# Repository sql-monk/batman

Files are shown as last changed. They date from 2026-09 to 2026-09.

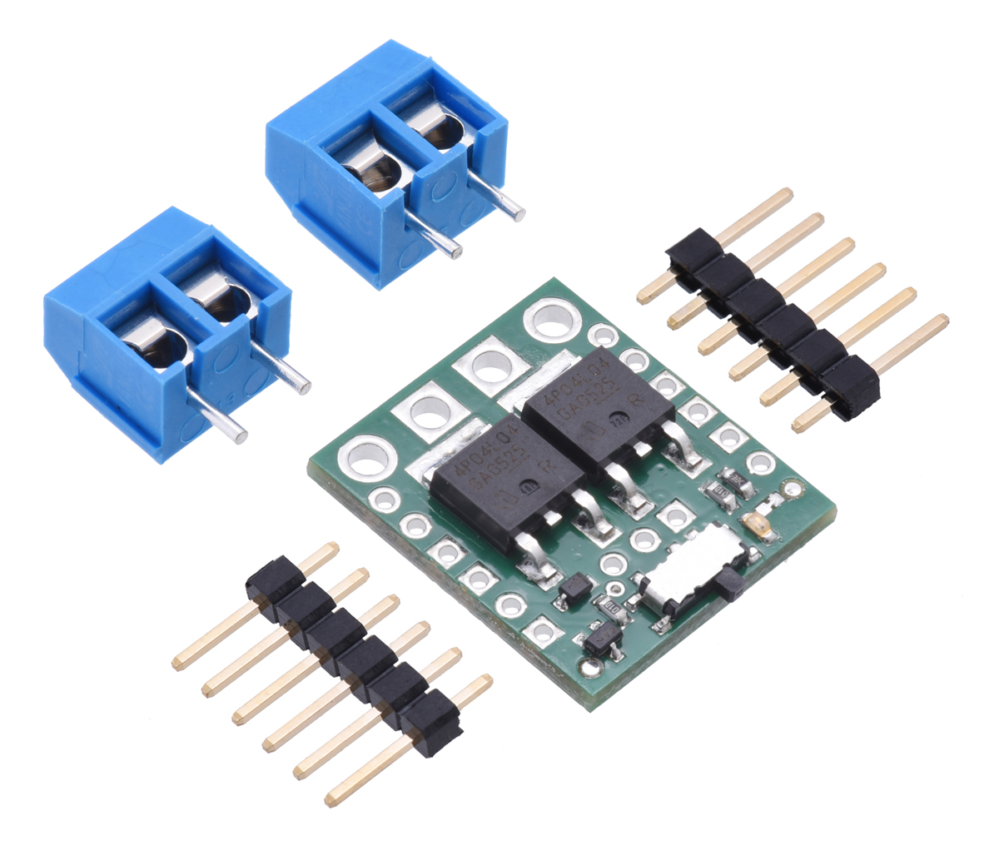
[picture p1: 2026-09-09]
mechanical/references/pololu-switch-terminals.jpg

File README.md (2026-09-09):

# batman — менеджер двох акумуляторів (LiFePO₄ 8S + свинець 24 В)

Пристрій, що заряджає два акумулятори по черзі від одного DPS5015, віддає їх на спільне навантаження через ідеальні діоди з керованими ключами, і рахує, скільки кожен акумулятор прийняв і віддав.

Основа — наявні модулі з [docs/components.md](docs/components.md). Чотири однобічні плати ЛУТ: A з ESP і двома портами I²C для ADS, B з аналоговими входами та фільтрами без I²C, C з розподілом 3,3 В, D з розподілом 5 В. Два окремі ADS1115 одержують аналог із B, живлення/I²C із A. Потрібен ще один ADS1115; C/D розподіляють готове живлення, а не замінюють стабілізатори.

| Тека | Вміст |
|---|---|
| [docs/concept.md](docs/concept.md) | задум, архітектура, вибір модулів, вимірювання й підрахунок А·год, припущення, відкриті питання |
| [docs/plan.md](docs/plan.md) | план робіт: документація, схема й плати, корпус, прошивка, сервіс; порядок і критерії готовності |
| [docs/components.md](docs/components.md) | кожен модуль і базовий компонент: характеристики, розпіновка, розміри з позначкою джерела, кількість, публічні посилання |
| [docs/README.md](docs/README.md) | зміст документації, правило «одне число — одне місце», позначення |
| [docs/connections.md](docs/connections.md) | вузли, кола з номерами, GPIO ESP32, роз'єми A–D, шкала АЦП |
| [docs/dps5015-modbus.md](docs/dps5015-modbus.md) | порт, регістри, послідовності команд, помилки DPS5015 |
| [docs/measurement.md](docs/measurement.md) | вибірка, інтегрування, автонуль, SoC, NVS |
| [docs/protocol.md](docs/protocol.md) | пристрій ↔ сервіс: пошук, JSON, REST |
| [docs/firmware.md](docs/firmware.md) | вимоги до прошивки: старт, стейт-машина, параметри |
| [docs/service.md](docs/service.md) | вимоги до сервісу: БД, агрегати, сторінки, розгортання |
| [docs/enclosure/requirements.md](docs/enclosure/requirements.md) | що вмістити, зони, зазори, тепло, друк, перелік STL |
| [docs/tests.md](docs/tests.md) | бланки перевірок і результати |
| [hardware/README.md](hardware/README.md) | єдиний проєкт KiCad 10, сім сторінок схеми, розведені A–D, PDF ЛУТ, свердління, BOM, кабелі та умови допуску прототипу |
| `firmware/` | код ESP32: вимірювання, підрахунок А·год, Modbus до DPS5015, ключі, Wi-Fi-телеметрія |
| `service/` | кросплатформений сервіс (Windows → Raspberry Pi 4): пошук пристрою, збір, зберігання, агрегати, графіки |
| `mechanical/` | модель корпусу, STL, звіти придатності до друку |

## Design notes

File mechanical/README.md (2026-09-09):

# Корпус BATMAN: деталізоване компонування

Актуальна механічна ревізія: [cad/assembly-cable-modular.blend](cad/assembly-cable-modular.blend). Кабельні рівні кріпляться до стійок рамками з пазами й передніми планками, як рівні електроніки. Чотири однакові висувні касети C92 мають сітку 32 мм для перестановки стандартних прямих секцій, поворотів, трійників та виводів вниз. [Набір деталей і порядок перестановки](modular-cables.md). Перевірені 31 закріплена секція, 26 проходів і стиків та незмінність 118 компонентів. Це механічний конструктор маршрутів; нові довжини джгутів, міжрівневі з'єднання й друкованість ще не затверджені.

Попередня ревізія з індивідуальними опорами й з'єднаними кабель-каналами: [cad/assembly-cable-supported.blend](cad/assembly-cable-supported.blend). Її схема прокладання та знімання касет: [cable-routing.md](cable-routing.md). Для неї перевірено контактний шлях усіх 33 лотків до кріплень та 29 стиків. Ці результати не переносяться на нове розташування модульних кабельних касет.

Попередня ревізія каналів: [cad/assembly-cable-routing.blend](cad/assembly-cable-routing.blend), збережена без перезапису.

Попередня деталізована ревізія: [cad/assembly-detailed.blend](cad/assembly-detailed.blend). Попередній ескіз [cad/assembly.blend](cad/assembly.blend) не перезаписано.

## Деталізація компонентів, 2026-09-09

У сцені `BATMAN - detailed assembly` показано всі 35 вузлів базового складу: PCB A/B/C/D, ESP32, два ADS1115, DPS5015 без дисплейної панелі, два ключі Pololu, три XL74610, три датчики струму, двоканальне реле, LM2596, OLED, кнопка, чотири ATO, C1/C2, три розподільні вузли, чотири XT60 та два зовнішні DS18B20. Не встановлені резервні модулі, налагоджувальні прилади й опційний корпусний вентилятор. Штатний вентилятор DPS показано.

Зовнішні силові з'єднання: **XT60 BAT1, BAT2, PSU IN, LOAD OUT**. У моделі є ключований корпус, два контакти, паяльні чашки й ізольовані хвости. Конкретний різновид XT60, стать контактів і спосіб фіксації власником ще не задані: це родова геометрія, не затверджене креслення панельної посадки.

- 83 посадкові позиції PCB та 216 контактних позицій перенесені з актуального KiCad, включно з монтажними отворами і допоміжними посадками. Старий список розкладки містив відсутній J9; він не створюється у моделі.
- ESP32 поставлено за координатами 38 контактів J1. Резистори й кераміка показані як один SMD-корпус 1206 з боку B.Cu; суміщені виводні конденсатори вдруге не додавалися.
- DPS має окремі клеми, конденсатори, радіатор, вентилятор, тороїд і UART; решта модулів мають відповідні корпуси, роз'єми й органи керування. Деталі покупних плат реконструйовані за описами та фото, не обміряні поелементно.
- C1/C2 перенесені безпосередньо до паяльних чашок LOAD XT60; стара віддалена колиска в новій ревізії прихована. Нова фіксація буфера ще не розроблена.
- DS18B20 показані зовні: під час роботи вони кріпляться до акумуляторів, а не всередині корпуса.

Оглядові сцени: `BATMAN - detailed open`, `BATMAN - detailed levels`, `BATMAN - logic detail`, `BATMAN - power detail`, `BATMAN - XT60 rear`. Рознесений вид не задає монтажних координат.

Перевірки у [detail-check.json](detail-check.json): повнота 35 вузлів, 83 посадки, 216 координат контактів, межі корпуса й зазор до кришки для 14 внутрішніх модулів, кадрування. **Це не повна перевірка перетинів, розведення джгутів або готовності до друку.**

Невідомими залишаються точний триконтактний ACS-модуль, корпуси C1/C2, придбання другого ADS, висоти роз'ємів, посадки XT60/ATO/OLED, доступ USB після прив'язки ESP до J1, фіксатори та тепловий режим. Генерична форма XT60 і приблизні деталі покупних плат не використовуються як підтверджені посадкові розміри.

Відтворення: запустити [export_components.py](export_components.py) Python-ом KiCad, відкрити попередню модель у Blender, виконати [detail.py](detail.py), [detail_views.py](detail_views.py), [detail_finish.py](detail_finish.py). Створюється окремий файл; генератори відмовляються перезаписувати вже наявні деталізовані сцени. Експорт PCB: [pcb-components.json](pcb-components.json).

Джерела: [компоненти](../docs/components.md), актуальний KiCad, [Pololu 2815](https://www.pololu.com/product/2815), [Pololu 2452](https://www.pololu.com/product/2452), [Joy-IT DPS5015](https://www.joy-it.net/en/products/JT-DPS5015). Фото виробників у каталозі `references` використовуються для звіряння; вони не є фото конкретних екземплярів власника.

## Попередня конструктивна основа

Це перевірка конструктивної ідеї, **не готовий комплект для друку**. Вихідну сцену Blender збережено окремою сценою `Scene`; електроніку в KiCad не змінено.

## Рівні

| Рівень | Висота основи пластин | Наповнення |
|---|---:|---|
| L0, дно | 3 мм | Навісні C1/C2, нижні зовнішні силові клеми; габарити тимчасові |
| L1, логіка | 40,2 мм | PCB A/B/C/D та окрема пластина двох ADS1115 |
| L2, силова частина | 123,2 мм | DPS5015, реле і LM2596, три пластини силових гілок |

Габарит корпуса 220 × 220 × 216 мм. Кришка, стінки й дно по 3 мм; пластини 2 мм. Кожен рамковий рівень має дві смуги напрямних, задній упор та знімну передню планку. Паз заввишки 2,4 мм дає 0,4 мм сумарного вертикального зазору.

Пластини шириною 92 мм входять спереду. Для виймання задньої пластини треба спочатку від'єднати джгути й витягти передні пластини в тій самій смузі. Передні планки стримують вихід касет. Остаточні фіксатори модулів і кріплення їхніх опор ще не завершені.

## Сцени Blender

- `BATMAN - assembly`: фактичне складене положення деталей з панелями.
- `BATMAN - open`: ті самі координати, панелі приховані для огляду.
- `BATMAN - levels`: рознесені рівні, передні пластини частково висунуті; це ілюстрація, а не монтажні координати.

Колекції підписані за рівнями та пластинами. Приховані об'єкти `envelope` містять спрощені габарити модулів. Видимі зображення компонентів не є точними моделями покупних плат.

## Що Підтверджено

- Поточні PCB: A 78 × 78, B 86 × 68, C 43 × 33, D 63 × 40 мм.
- Монтажні отвори PCB перевірені в актуальному KiCad-файлі: 3,5 мм від краю, Ø3,4 мм.
- DPS 91 × 67 × 40 мм і міжцентрові отворів 86 × 64 мм взяті з обміру в документації.
- Скрипт перевіряє габарити заготовок, інтервали між пластинами, прохід повз передні стійки та зазор стійок PCB від верхніх губок пазів.
- Окремо перевіряється замкненість сіток заготовок. Це не повна перевірка перетинів або міцності.

## Перед Друком

C1 Ø12 × 22 мм та C2 6 × 4 × 7 мм використані **лише як тимчасові макети**: фактичні кількість і розміри не підтверджені. Конденсатори на PCB й готових модулях залишаються на місці. Навісний буфер треба тримати поруч із клемами LOAD, не подовжуючи його виводи заради компонування.

Потрібні обмір покупних модулів і панельних клем, фінальні притиски, кріплення опор до пластин, посадки OLED/USB/DS18B20/запобіжників, перевірка джгутів, вентиляції та друкованості рамок. STL поки не випущені, щоб ескіз не сприймався як готова механіка.

Повний перелік заготовок, їхні габарити й об'єми: [report.md](report.md). Результати: [check-result.json](check-result.json), [mesh-check.json](mesh-check.json).

## Відтворення

У новій сесії Blender виконати [build.py](build.py), потім [views.py](views.py) через Python із заданим `__file__`. Обидва скрипти використовують `bpy`; звичайний Python не створить модель. Генератор відмовляється перезаписувати вже створену непорожню сцену.

[check.py](check.py) працює звичайним Python після генерації [manifest.json](manifest.json). Джерело габаритів PCB: [../hardware/modular-layout.json](../hardware/modular-layout.json).

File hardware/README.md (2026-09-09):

# BATMAN: чотири модульні PCB

**CAD-прототип, не перевірений на стенді.** Основний проєкт: [batman/batman.kicad_pro](batman/batman.kicad_pro), KiCad 10.0.6+. У [спільній PCB](batman/batman.kicad_pcb) чотири замкнені контури: це чотири фізичні плати, не одна плата з міддю між ними. Схема має кореневий і шість функціональних аркушів.

## Склад

Актуальна ревізія трасування 2026-09-09: **223 сегменти (A: 85, B: 77, C: 28, D: 33), тільки напрямки 0/45/90°**. Попередня версія зі 165 сегментами довільного напрямку замінена. Компоненти, їхні кути, контакти та чотири перемички залишені на місцях; глобальний мінімум кількості перемичок не доведений. GND з'єднує заливка. Вільні кінці трас точно збігаються з центрами контактів, інші стики мають спільні центральні лінії; сегментів коротше 1 мм немає. DRC усіх плат, паритет схеми та PDF 1:1 перевірені. Експорт відхиляє некратні 45° напрямки. Опис перенесення GPIO33 нижче стосується попереднього етапу розміщення.

| PCB | Функція | Розмір, мм | Локальні перемички | Отвори |
|---|---|---|---|---|
| A | ESP32 DevKitC, два порти ADS I²C, OLED, UART DPS, SPI, кнопка, 1-Wire, драйвери реле | 78 × 78 | WA1–WA4 | 86 |
| B | Шість аналогових входів, дільники, RC-фільтри; аналогові виходи до окремих ADS | 86 × 68 | немає | 39 |
| C | Розподіл 3,3 В і кероване живлення mACS через Q3 | 43 × 33 | немає | 18 |
| D | Розподіл 5 В, діодне «АБО» B1/B2 перед зовнішнім LM2596, зірка живлення реле | 63 × 40 | немає | 32 |

Чотири перемички WA1–WA4 на A паяються до наявних контактів; B/C/D без перемичок. WA1 (+3V3) закінчується на SMD-паді R16.2, WA4 (SCL) на R17.1: ізолювати та механічно розвантажити дроти. WA2 з'єднує кнопку J11.2 з J1.7; WA3 — SCL J20.3 з J10.2. Жодна локальна перемичка не підключається до J22. Разом 175 отворів, включно з 16 монтажними M3 Ø3,4 мм. ADS1115 J2/J13 — два зовнішні модулі, посадок під них на A–D немає.

Ревізія GPIO33 2026-09-09: 352 сегменти, усі довжиною не менше 1 мм. **SENS_PWR перенесений на J1.8 / GPIO33; J1.12 / GPIO14 тепер NC.** J22 піднятий і повернутий вертикально; усі три його контакти (+3V3, GND, SENS_PWR) з'єднані з ESP міддю без локальних перемичок. Це перевірено на копії PCB без моделей дротів. Для проходу живлення пересунутий роз'єм кнопки J11. Кабель CB2 до окремої плати C залишається потрібним. У прошивці задати SENS_PWR=33, HIGH/Hi-Z=OFF, LOW=ON; старе призначення GPIO14 непридатне. Загальна площа плат зменшена приблизно на 6%. Збережені ручні позиції J6/J7/J26/R13/R18; попередні зміни J20/J21/R16/R17, C3/C4 та роз'ємів D залишені. Старі монтажні таблиці й перемички не використовувати.

Силові 10 А батарей і навантаження не проходять через ці PCB. Зовнішні модулі, запобіжники й панельні клеми залишаються у схемі. C1/C2 навісно на зовнішній шині LOAD+/GND; D3 DNP. Нова PCB B є **аналоговою**, не колишньою платою буфера.

## Міжплатні Кабелі

Порядок у таблиці: від контакту 1 до N. Кабелі однойменні, 1→1; **не перевертати за фізичним напрямком гребінки**. Звіряти номери на монтажних PDF.

| Кабель | Звідки → куди | Контакти 1…N |
|---|---|---|
| CB2 | A.J22 → C.J23 | +3V3, GND, SENS_PWR |
| CB3 | C.J24 → B.J25 | GND, +3V3_SENS |
| CB4 | D.J27 → A.J26 | +5V, GND |
| CB5 | A.J28 → D.J29 | RELAY_IN1, RELAY_IN2, GND |
| CB6 | D.X6 → B.X8 | B1, B2, GND; напруга батарей до дільників, не рівні 3,3 В |

Між A–D п'ять кабелів, 13 жил. **CB1 вилучений; J21 тепер на A. Старі кабелі J20/J21 і J24/J25 несумісні з цією ревізією.** [interboard-cables.csv](batman/output/interboard-cables.csv) містить кожну жилу CB2–CB6. `WC*` на спільній PCB моделюють зовнішні дроти, не мідь. Лінії Dwgs.User показують відповідність кінців, не маршрут і довжину джгута.

## Підключення Окремих ADS

| Роз'єм PCB | Контакти PCB 1…N | Зовнішній модуль і контакти |
|---|---|---|
| A.J20 | +3V3, GND, SCL, SDA | J2 (0x48): VDD, GND, SCL, SDA |
| A.J21 | +3V3, GND, SCL, SDA | J13 (0x49): VDD, GND, SCL, SDA |
| B.J32 | I_B1, I_B2, U_B1, U_B2, GND | J2: A0, A1, A2, A3, GND |
| B.J33 | I_LOAD, U_LOAD, GND | J13: A0, A1, GND |

Це ще чотири кабелі, 16 жил, не включені в CB2–CB6. Точні контакти — [cable-map.csv](batman/output/cable-map.csv). На кожному ADS обидві землі кабелів з'єднати в локальній точці GND із надійною ізоляцією та розвантаженням дротів; один контакт модуля не означає два незалежні гнізда.

J20/J21 — два роз'єми **однієї** шини GPIO22=SCL/GPIO21=SDA. Є одна пара R16/R17 по 4,7 кОм до 3V3 на A; не додавати ще одну пару для другого порту. C6/C10 — локальні 100 нФ VDD–GND біля відповідного зовнішнього ADS, не на B: перевірити наявність на модулі, за відсутності встановити. Перемички ADDR та невикористані входи — [ads-configuration.csv](batman/output/ads-configuration.csv).

I²C: початково 100 кГц, короткий внутрішній кабель до 20 см, подалі від силових дротів. Перевірити фронти осцилографом і сумарні підтяжки на A, ADS-модулях та OLED: врахувати паралельний опір і допустимий струм LOW. Це не інтерфейс для довгого зовнішнього кабелю. CB6 вести окремо від I²C; дроти B1/B2 мають бути захищені від КЗ біля джерела.

## Аналогова Плата B І Канали

На B немає ADS, SDA/SCL і неперемиканої шини +3V3. Потрібні **два окремі модулі ADS1115**, один додатковий до початкового комплекту. Їхні позначення J2/J13 збережені у схемі, але мають власника EXTERNAL. Перевірити маркування `VDD GND SCL SDA ADDR ALRT A0 A1 A2 A3`. Локально на J2 ADDR з'єднати з GND, на J13 з VDD; спочатку розімкнути заводську перемичку ADDR→GND другого модуля, інакше буде КЗ. На J13 локально заземлити A2/A3, обидва ALRT залишити NC.

| АЦП | Адреса | A0 | A1 | A2 | A3 |
|---|---|---|---|---|---|
| J2 | 0x48 | I_B1 | I_B2 | U_B1 | U_B2 |
| J13 | 0x49 | I_LOAD | U_LOAD | GND | GND |

Обидва PGA ±4,096 В, 475 SPS; це діапазон перетворення, **не дозвіл перевищувати живлення на вході**. Дільники: U_B1/U_B2 100k/10k, U_LOAD 100k/4,7k. Струми через RC 1k/1u; напруги через дільники й 100n. GPIO34/39 ESP тепер NC, аналогових кабелів до A немає. ALRT не підключені, готовність опитувати через I²C.

ADS розмістити біля B; аналогові кабелі початково до 10 см, окремо від силових і цифрових джгутів. Перевірити шум та зміщення при передачі Wi-Fi й роботі реле. Усі підключення робити з вимкненим живленням: напруга на B1/B2/LOAD може підживлювати знеструмлений ADS через входи. Живі аналогові входи без живлення ADC не допускаються; схема не містить окремого захисту від такого режиму.

mACS мають лише VCC/GND/VOUT, без FAULT. J3/J4: VOUT, GND, VCC; J5: VCC, VOUT, GND. Збережене припущення ACS711EX 3,3 В / 90 мВ/А. Позначення власника `VSS` неоднозначне: **не подавати плюс без перевірки моделі та маркування**. Датчик на 5 В не є прямою заміною.

## Живлення

**C і D є розподільними платами, не новими стабілізаторами.**

- D.X1: B1, B2, GND. P28 від зовнішньої мінус-шини до D.X1.3. VD1/VD2 формують VIN_DC на D.X2.1 для входу наявного LM2596; X2.2 GND. Його вихід, заздалегідь виставлений на 5,0 В, підключається до D.X3.1/2.
- D.J27 живить VIN DevKitC на A через CB4. D.J31: резервний вихід 5V/GND, штатно без навантаження. 5 В потрібні DevKitC і реле.
- D.J8: IN1, GND, IN2, VCC, JD-VCC. Перемичку VCC–JD-VCC на реле зняти. NT1 біля X3 є мідною зіркою; гілки опто та котушок не об'єднувати біля J8.
- 3,3 В утворює стабілізатор DevKitC. A.J20/J21 живлять окремі ADS, A.J22 передає 3V3 на C.J23. C.J24 живить тільки датчики через B; Q3 комутує +3V3_SENS. SENS_PWR LOW=ON, HIGH/Hi-Z=OFF. C.J30: резервний 3V3/GND, штатно без навантаження.
- **Не підключати зовнішнє джерело до A.J20/J21 або C.J30:** це виходи 3V3 DevKitC. C.J24 також не є входом живлення. USB одночасно із зовнішнім VIN дозволений лише після перевірки конкретного DevKitC на зворотне підживлення.

Орієнтовна початкова межа зовнішнього навантаження 3,3 В: до 100 мА сумарно на ADS, mACS, OLED, підтяжки й периферію, **лише якщо конкретний DevKitC має такий запас після власного споживання**. Це не паспортний рейтинг плати. Піки Wi-Fi, котушки, нагрів LDO, падіння на Q3 й кабелях перевірити на стенді. Резервні виходи не створюють додаткової потужності. За браку запасу потрібна інша ревізія з окремим стабілізатором 3,3 В, не паралельне підключення джерел.

GND спільний. Через CB2–CB6, цифрові й аналогові кабелі ADS та UART є кілька шляхів повернення струму: модульність **не забезпечує гальванічної розв'язки чи відсутності петель землі**. Силові повернення вести окремо, перевірити топологію на стенді.

## Виготовлення

ЛУТ, тільки **B.Cu**: сигнали ≥0,8 мм; GND і живлення 3,3/5 В ≥1,0 мм; B1/B2/LOAD+/VIN_DC ≥1,2 мм. Зазор за участю доріжки ≥0,65 мм, між готовими падами ≥0,5 мм; від батарейних мереж B1/B2/LOAD+/VIN_DC до іншої міді ≥1,0 мм, включно із заливкою. Відступ від краю ≥0,5 мм. Це технологічний запас для низьковольтного батарейного пристрою, не сертифікація ізоляції та не дозвіл підвищувати робочу напругу або струм. Силові 10 А залишаються поза PCB.

Без via, mask/paste. THT-пади номінально мають F.Cu у KiCad, але цей шар не виготовляється. Резистори лише 1206; C3–C5, C7–C9, C11–C13 мають альтернативні THT/1206-пади, ставити **один** корпус на позицію. C1/C2 зовнішні на шині, C6/C10 біля зовнішніх ADS.

| Плата | Мідь, дзеркало 1:1 | Монтаж |
|---|---|---|
| A | [A/copper-mirrored.pdf](batman/output/A/copper-mirrored.pdf) | [A/assembly.pdf](batman/output/A/assembly.pdf) |
| B | [B/copper-mirrored.pdf](batman/output/B/copper-mirrored.pdf) | [B/assembly.pdf](batman/output/B/assembly.pdf) |
| C | [C/copper-mirrored.pdf](batman/output/C/copper-mirrored.pdf) | [C/assembly.pdf](batman/output/C/assembly.pdf) |
| D | [D/copper-mirrored.pdf](batman/output/D/copper-mirrored.pdf) | [D/assembly.pdf](batman/output/D/assembly.pdf) |

У кожній теці A–D є недзеркальна мідь, wiring.pdf, Excellon/карта свердління й Gerber. Спільні PDF у output показують усі чотири плати, не стару 100×80 PCB. Друк Actual size / 100%, без Fit; перевірити лінійкою контур і крок 2,54 мм.

[pinout.csv](batman/output/pinout.csv): контакти від лівого верхнього кута своєї PCB. [drill-list.csv](batman/output/drill-list.csv) і [drill-summary.csv](batman/output/drill-summary.csv): отвори за платами. [jumpers.csv](batman/output/jumpers.csv): WA1–WA4 на A. [cable-map.csv](batman/output/cable-map.csv): кабелі зовнішніх модулів, включно з ADS. [bom.csv](batman/output/bom.csv): J1 — DevKitC із гніздами, J2/J13 — окремі ADS, не дублікати модулів.

## Перевірки Та Обмеження

ERC, DRC/паритет спільної PCB, DRC кожної локальної плати та PDF 1:1: [validation.json](batman/reports/validation.json), [pdf-validation.json](batman/reports/pdf-validation.json). Експорт перевіряє відсутність міжплатної міді, сегментів коротше 1 мм та правильні контакти кабелів ADS. Для роботи потрібні чотири перемички A, п'ять кабелів CB2–CB6, чотири кабелі до ADS і їхні локальні з'єднання ADDR/A2/A3/GND. DRC не перевіряє фактичний зовнішній монтаж.

До виготовлення звірити посадки DevKitC (38 пінів, міжряддя 25,4 мм), клемників 5,00 мм, BC547/BC557 C-B-E та осьових 1N5819 K-A. MCU: USB унизу, антена зверху; keepout на A не замінює перевірки реального модуля. Зовнішні ADS закріпити на ізольованих тримачах біля B, не залишати на дротах. **Корпуси та висоти не обміряні; DRC не перевіряє їхню посадку.** Джгути не прокладати над антеною.

До підключення батарей закрити попередні питання безпеки: реле 10 А проти старої вимоги прошивки 12 А; відсутність апаратного взаємоблокування K1/K2; неможливість гарантувати безструмову комутацію при всіх відмовах DPS; ground-loop через UART. D3 DNP: напис 33 В не гарантує обмеження до 35 В. Не перевищувати 10 А на наявному реле. FAULT від mACS немає. Перший запуск з обмеженням струму, без батарей і силового навантаження. Стендові випробування не виконані.

## Відтворення

Наведений нижче старий процес **не відтворює актуальні 223 сегменти**. Поточний результат збережений у головній PCB та reports/routing45/staged. [octilinear.py](octilinear.py) обмежує маршрути напрямками 0/45/90°; [clean_paths.py](clean_paths.py) без цього обмеження дозволяє довільні кути й не відтворює поточну ревізію. Інструменти в reports/routing45 використовують історичні знімки, а не нові ручні правки. Локальні плати мають світові координати основної збірки: старий `modular.py --merge` повторно змістить їх. Для актуального комплекту не запускати старі `--finish-copper`, `polish.py` або `--merge`; перевірка та експорт головної PCB через `export.py` підтримуються.

[circuit.py](circuit.py): з'єднання й власники деталей; [connector_pinout.json](connector_pinout.json): зовнішні роз'єми; [modular-layout.json](modular-layout.json): геометрія; [modular.py](modular.py): плати й кабелі. Старі floorplan.json / placement.py / placement.json не керують цією ревізією. Прямі одноплатні входи pcb.py і freeroute.py вимкнені.

```powershell
$python = "$env:LOCALAPPDATA\Programs\KiCad\10.0\bin\python.exe"
& $python hardware/circuit.py
& $python hardware/modular.py --route --finish-copper --wire
foreach ($board in @('A', 'B', 'C', 'D')) {
	& $python hardware/polish.py "hardware/batman/reports/$board/candidate.kicad_pcb"
	if ($LASTEXITCODE -ne 0) { throw "PCB $board needs local correction" }
}
& $python hardware/modular.py --merge
& "$env:LOCALAPPDATA\Programs\KiCad\10.0\bin\kicad-cli.exe" pcb drc --refill-zones --save-board --exit-code-violations hardware/batman/batman.kicad_pcb
& $python hardware/export.py
python hardware/review_pdf.py
```

Потрібні pcbnew/numpy/sexpdata у Python KiCad, Java 25 і Freerouting 2.4.1 (`FREEROUTING_JAVA`, `FREEROUTING_JAR`, або перевірені файли в TEMP); PyMuPDF потрібний лише останній перевірці. Трасування локальне, API/аналітика вимкнені. `--board A` (або B/C/D) обмежує трасування однією платою; `--merge` збирає всі чотири. Не використовувати старі SES після зміни контактів чи геометрії.

Генератори **перезаписують** CAD. Не запускати поверх ручних правок без перенесення їх у модель. Технічні знімки й настройки DRC у reports/A–D, відкривати для роботи основний batman.kicad_pro. [batman.kicad_dru](batman/batman.kicad_dru) переносити разом із проєктом. Після зовнішньої перебудови не зберігати старий відкритий у KiCad вміст поверх нового.

[polish.py](polish.py) є історичним інструментом видалення та злиття коротких сегментів; подовження окремих шматків прибране. Чистий DRC сам по собі не гарантує акуратних стиків центральних ліній. [refine.py](refine.py) зберігає історичний експеримент у reports/refinement, використовує зафіксований saved-input і не є входом для імпорту майбутніх ручних правок.

[gpio33.py](gpio33.py) зберігає кандидат перенесення GPIO33 у reports/gpio33. `--check-j22` вилучає моделі перемичок тільки з тестової копії та перевіряє мідну зв'язність J22 з J1 по всіх трьох мережах. Очікувані обриви інших мереж у copper-only-drc.json не є DRC виробничої PCB. Скрипт використовує свій зафіксований saved-input; для майбутніх ручних правок цей знімок не є актуальним джерелом.

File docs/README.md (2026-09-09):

# Документація — зміст і правила

## Файли

| Файл | Що всередині | Хто за ним працює |
|---|---|---|
| [concept.md](concept.md) | задум, архітектура, ключові рішення, межі, припущення, відкриті питання | усі |
| [plan.md](plan.md) | план робіт по п'яти потоках, критерії «готово, коли» | усі |
| [components.md](components.md) | кожен модуль і базовий компонент: характеристики, розпіновка, розміри з позначкою джерела, кількість | схема, корпус, BOM |
| [connections.md](connections.md) | вузли, силові й сигнальні кола з номерами, GPIO ESP32, роз'єми A–D, шкала АЦП | схема, плати, прошивка (`pins.h`) |
| [dps5015-modbus.md](dps5015-modbus.md) | порт, регістри, послідовності команд, помилки | прошивка |
| [measurement.md](measurement.md) | вибірка, фільтрація, інтегрування, автонуль, SoC, що і коли в NVS | прошивка |
| [protocol.md](protocol.md) | пристрій ↔ сервіс: пошук, `POST /sink`, JSON телеметрії та подій, REST пристрою | прошивка, сервіс |
| [firmware.md](firmware.md) | вимоги до прошивки: безпечний старт, стейт-машина, пороги, OLED, Wi-Fi, OTA | прошивка |
| [service.md](service.md) | вимоги до сервісу: БД, агрегати, сторінки, розгортання | сервіс |
| [enclosure/requirements.md](enclosure/requirements.md) | що вмістити, зони, зазори, тепло, правила друку, перелік деталей | корпус |
| [tests.md](tests.md) | протоколи стендових і приймальних перевірок з результатами | усі |

## Правило «одне число — одне місце»

Кожне число живе в одному файлі, решта на нього посилаються:

- характеристики й розміри модулів, номінали компонентів — **components.md**;
- номери проводів, GPIO, адреси I2C, коефіцієнти дільників — **connections.md**;
- регістри й таймаути DPS — **dps5015-modbus.md**;
- частоти вибірки, пороги фільтрів, формули — **measurement.md**;
- профілі заряду, пороги стейт-машини — **firmware.md** (таблиця параметрів NVS), concept.md їх лише описує словами;
- формат JSON і REST — **protocol.md**;
- зазори, товщини, допуски друку — **enclosure/requirements.md**.

Закрите питання чи скасований пункт — видаляється, а не позначається виконаним.

## Позначення

| Позначення | Що |
|---|---|
| mDPS, mDIO1–3, mSW1–2, mREL2, mACS1–3, mADC, mMCU, mDC5, mOLED | модулі (components.md) |
| K1, K2 | канали mREL2 — вибір гілки на заряд |
| Bat1 / Bat2 | LiFePO₄ 8S 50 А·год / свинець 24 В 65 А·год |
| B1, B2, CHG, LOAD+, GND, +5V, +3V3 | вузли (connections.md) |
| F1, F2, Fchg, Fout | запобіжники гілок, заряду, виходу |
| P01…, L01… | силові й логічні кола (connections.md) |
| I_B1, I_B2, U_B1, U_B2, U_LOAD, I_LOAD, T1, T2 | вимірювані сигнали |
| SW1_ON, SW2_ON, K1, K2, SENS_PWR, BTN, OW, DPS_TX/RX | сигнали GPIO (connections.md); FAULT є програмним станом, не проводом mACS |
| плати A / B / C / D | ESP із двома портами ADS / аналогові фільтри / розподіл 3,3 В / розподіл 5 В; ADS зовнішні, монтаж у hardware/README.md |
| зовнішній вузол шин | силові клеми LOAD+/GND та навісні C1/C2, не PCB B |

Одиниці: В, А, А·год, Вт·год, °C, мм; десятковий роздільник — кома в тексті, крапка в коді та JSON.

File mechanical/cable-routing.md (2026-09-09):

# Наступна Механічна Ревізія

Модульні касети зі стандартними переставними секціями описані у [modular-cables.md](modular-cables.md); модель [cad/assembly-cable-modular.blend](cad/assembly-cable-modular.blend). Нижче збережено попередню схему індивідуальних лотків. Її висоти, довжини й результати перевірок не застосовуються автоматично до нових касет.

# Кабель-канали BATMAN

Актуальна модель: [cad/assembly-cable-supported.blend](cad/assembly-cable-supported.blend). Попередні моделі не перезаписано. Електроніку, положення модулів і схеми KiCad не змінено.

## Опори та стики

- Лотки A й обох ADS спираються на поперечини з кріпленням M3 до рамки: під ними немає пластини, тому опора йде саме від рамки.
- Лотки B/C/D, DPS, реле та LM2596 отримали додаткові опори на своїх пластинах. Опори C/D і DPS відсунуті від ручок висування.
- Силовий стояк і лоток запобіжників закріплені кронштейнами до задньої панелі. UI-стояк і верхній лоток OLED/кнопки мають кронштейни до передньої панелі.
- Розриви між відгалуженнями та магістралями закриті переходами зі знімними кришками. До трьох силових гілок і DPS додані дугові переходи з радіусом осьової траси 15 мм. LM2596 входить у верхню камеру силового стояка через перехід зі зміною висоти.
- Внутрішні стінки у зонах стику прорізані, включно з переходами горизонталь → вертикаль; сам контакт зовнішніх коробів не замінює кабельного проходу.

[cable-contact-check.json](cable-contact-check.json) перевіряє геометричний контакт поверхонь, а не лише перелік назв: усі 33 лотки мають контактний шлях до опори, усі 29 міжлоткових стиків проходять перевірку. Для контакту використовується числова межа 0,16 мм, а не допуск для друку. Задні й передні п'яти мають 0,1 мм модельного зазору до панелі під стягування болтом. У [cable-support-check.json](cable-support-check.json) записані опори, стики та перевірка нових деталей на перетини з корпусом/електронікою.

У сцені `BATMAN - supported cable assembly` корпус і кришки каналів на місці. У розрізі `BATMAN - supported cable cutaway` лишені задня стінка та смуги передньої панелі біля кронштейнів, щоб було видно опорні поверхні; ці смуги не є новими окремими деталями корпуса. Окремі ракурси: `BATMAN - supported cable logic`, `BATMAN - supported cable power`, `BATMAN - supported cable rear anchors`.

## Розподіл джгутів

| Канали | Призначення | Внутрішній переріз, мм |
|---|---|---|
| P-IN, PV, PF | XT60, вертикальний силовий стояк, чотири запобіжники | 22 × 14; 16 × 14; 16 × 12 |
| P0 | Верхня силова магістраль між гілками | 18 × 14 |
| P1 / P2 / P3 | ACS, вузли B1/B2/LOAD, ключі та ідеальні діоди | 16 × 12 |
| PD / PR / PL | DPS IN/OUT, зарядне реле, LM2596 | 10 × 14; 14 × 12; 8 × 10 |
| S1 / S2 | Міжплатні з'єднання й підключення керування силових модулів | 12 × 10 |
| SV | Окремі підйоми сигналів через пластини | За кількістю жил; див. перевірку |
| AN48 / AN49 | Тільки аналог і GND від B до двох ADS | 6 × 6 |
| UI | OLED і кнопка; вертикальний канал біля передньої панелі | 4 × 7 та 6 × 6 |

Всі канали підписані. Жовті призначені для силових проводів, сині для сигналів та низькострумового живлення, зелені для аналогових з'єднань B → ADS. Земляний провід сигналу йде разом із цим сигналом, а не окремою силовою магістраллю.

У моделі 33 секції з окремими знімними кришками. Передбачені вушка зі щілинами 4,2 × 1,4 мм для багаторазових стяжок шириною 3 мм. Основна верхня магістраль, канали гілок, нижня магістраль та підвіси сигнального лотка мають опори з отворами Ø3,4 під M3. Відгалуження не треба приклеювати до дротів або плат.

Силовий стояк проходить через відкриті вирізи внутрішнього краю пластин C і relay/supply. Для сигналів зроблені окремі проходи в силових пластинах, для UI — крайовий виріз біля DPS. Змінені тільки копії механічних деталей у новій ревізії. Вирізи й центри монтажних отворів перелічені у [cable-check.json](cable-check.json).

## Прокладання

1. Установити силові джгути XT60 → запобіжники → силові гілки в P-IN/PV/PF/P0. Не використовувати корпус або гвинти як електричний провідник.
2. Від P1/P2/P3 залишити короткі місцеві хвости до клем ACS, B1/B2/LOAD, ключів і діодів. Входи/виходи DPS ведуться PD, реле PR, LM2596 PL. Полярність і реальні точки підключення визначаються електричною документацією, а не кольором 3D-кривої.
3. CB2–CB6, датчики й керування прокласти по S1/S2. До модулів піднятися через окремі SV. Не прив'язувати сигнальний джгут до силового навіть у місці загального проходу; місцеві перехрещення робити під прямим кутом.
4. B.J32 → ADS 0x48 і B.J33 → ADS 0x49 вести тільки AN48/AN49. Живлення/I2C з A.J20/J21 вести окремо через S1. Не робити запас довжини аналогового кабелю великими кільцями.
5. OLED/кнопку підняти UI. DS18B20 вести від A.X4 у сигнальній зоні до задніх проходів; гільзи лишаються зовні на акумуляторах.
6. Перед вийманням касети знеструмити пристрій, розстебнути відповідні стяжки, зняти її перехідник до нерухомої магістралі, від'єднати й звільнити місцеві хвости. За потреби звільнити болтову опору лотка на касеті. Канали не є кабельним ланцюгом: висувати підключену пластину не можна. Для задньої касети спочатку вийняти передню в тій самій смузі.

Доступ до хвостів тепер через знімні кришки переходів. Старі окремі червоні дуги над розривами прибрані; їх замінено геометрією переходів. Не перегинати силові жили через торець лотка; радіус фактичного кабелю перевірити за його ізоляцією. Осьовий радіус переходу не гарантує такий самий радіус кожної жили біля внутрішньої стінки.

## Перевірено

- 33 канали, 163 змодельовані деталі каналів, кришок, опор і вушок; сітки замкнені, деталі в межах корпуса.
- Не виявлено перетинів поверхонь нових друкованих деталей із наявними деталями корпуса та електроніки після вирізів. Це не повна перевірка всіх з'єднань нових деталей між собою або вкладених об'ємів.
- Основні силові й сигнальні траси рознесені на 20,7–30,7 мм. Цей результат не поширюється на короткі хвости біля самих роз'ємів.
- Розрахункове заповнення кожного каналу не більше 45%; для силових жил прийнято зовнішній Ø3,5 мм, для сигналів Ø1,3 мм, для LM2596 Ø2 мм. Перевірено також укладання намальованих рядів під кришкою.
- AN48/AN49 приблизно по 76 мм, включно із 15 мм резерву на хвости, за змодельованими точками й низькопрофільним укладанням. Перед обтисканням перевірити реальні гребінки; обмеження 100 мм зберігається.

Дроти в моделі демонструють заповнення й призначення каналів. Це **не перевірена поконтактна 3D-розводка**: криві окремих каналів не є доказом електричної неперервності між клемами.

## До виготовлення

Кріплення стояків і лотків до панелей та пластин змодельовані й геометрично перевірені. Перед виготовленням залишаються вибір довжин болтів і посадок гайок, з'єднання друкованих опор із лотками, втулки проходів, реальні згини та роз'єми хвостів, міцність, друкованість і доступ викруткою. Зображення M3 показують призначення кріплення, не остаточну специфікацію метизів. STL для виробництва не випущені.

У поточній PCB немає J9, хоча старий cable-map його згадує. UART-канал передбачений, але точки зняття DPS_TX/DPS_RX/GND треба підтвердити по актуальній PCB перед монтажем.

## Огляди й відтворення

- `BATMAN - cable assembly`: зібраний корпус із кришками каналів.
- `BATMAN - cable open`: стінки й кришки каналів прибрані для огляду.
- `BATMAN - cable power`, `BATMAN - cable logic`: окремі рівні.
- `BATMAN - cable rear`: задній стояк і запобіжники без панелей.

Відкрити попередню деталізовану модель у Blender, виконати [cable_channels.py](cable_channels.py), [cable_branches.py](cable_branches.py), [cable_finish.py](cable_finish.py) у цій послідовності. Вони створюють окрему ревізію та відмовляються перезаписувати готові сцени. [cable_repair.py](cable_repair.py) — тільки журнал одноразового виправлення раннього прототипу в поточній сесії; для нового відтворення його не запускати.

Для актуальної ревізії відкрити попередню модель із каналами та виконати [cable_supports.py](cable_supports.py), [cable_joinery.py](cable_joinery.py), [check_cable_supports.py](check_cable_supports.py), [cable_supported_views.py](cable_supported_views.py) в одній сесії Blender. Старі сцени збережені; нові мають префікс `BATMAN - supported cable`.

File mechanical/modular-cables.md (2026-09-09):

# Модульні кабельні касети

Модель: [cad/assembly-cable-modular.blend](cad/assembly-cable-modular.blend).

Це нова механічна ревізія: замість горизонтальних лотків з індивідуальними опорами використані окремі висувні кабельні касети. Попередня [модель з опорами](cad/assembly-cable-supported.blend) збережена без змін. Електроніка та її 118 компонентних об'єктів залишені на тих самих місцях.

## Посадка Як У Рівнів

Дві додаткові рамки повторюють принцип рамок електроніки: пази 2,4 мм, задній упор, знімна передня планка, кріплення до чотирьох кутових стійок. У копіях стійок додані отвори під кріплення рамок на висотах 88,2 і 174,2 мм. Передні кінці нових напрямних укорочені із зазором 0,2 мм до передньої планки.

Кожна рамка приймає дві **однакові касети C92 розміром 92 × 202 × 2 мм**. Праву касету розвернуто на 180°. Низ пластин: 87,2 та 173,2 мм. Висота корпуса не змінена. Сумарний вертикальний зазор пластини у пазі становить 0,4 мм. Це номінальна геометрія; усадку друку ще треба перевірити.

На кожній касеті 12 позицій, дві колонки по шість, із кроком **32 мм**. У кожної позиції вікно 22 × 22 мм для виходу джгута й вентиляції та чотири отвори Ø3,4 мм на квадраті 25 × 25 мм. Знизу отвори мають зенкування під потайні гвинти. Перестановка секцій не потребує свердління нових отворів.

## Однакові Деталі

| Код | Деталь | Призначення |
|---|---|---|
| C92 | Касета 92 × 202 мм | Спільна основа для обох рівнів і обох смуг |
| A4 | Підставка 4,2 мм із вікном | Спільний перехід від сітки касети до секції |
| S32 | Пряма | Продовження траси |
| L32 | Поворот 90° | Зміна напрямку |
| T32 | Трійник | Відгалуження |
| X32 | Чотиристоронній вузол | Сполучення чотирьох напрямків в одній порожнині |
| D32 | Кінцевий вивід вниз | Отвір Ø16 мм до модуля через вікно касети |
| J32 | Вставка стику | Перекриває зазор між секціями врівень із дном |
| K32 | Спільна кришка | Підходить до всіх п'яти видів секцій |

Усі секції мають однаковий габарит 31,6 × 31,6 × 16 мм, дно 2 мм і канал завширшки 18 мм та заввишки 14 мм. На сітці 32 мм між корпусами залишається монтажний проміжок 0,4 мм; вставка J32 перекриває його. Її номінальний бічний зазор у посадці 0,1 мм на сторону. Секції можна повертати на 0°, 90°, 180° і 270°. Колір не змінює геометрії чи сумісності.

X32 не є ізольованим перехрестям: через нього не слід змішувати силовий і чутливий сигнальний джгути. Радіуси згину конкретних силових проводів у L32/T32 ще не підтверджені; для товстого джгута може знадобитися поворот на кілька комірок.

## Кріплення Й Перестановка

Кожна секція має два незалежні яруси кишень під гайки M3. Нижні гайки кріплять секцію до касети через A4; верхні кріплять лише кришку. Гайки завантажуються збоку до складання сусідніх секцій.

Номінальні гвинти: чотири потайні M3 × 12 знизу для основи та чотири M3 × 8 зверху для кришки на секцію. Модельні гайки мають товщину 2,4 мм; кишені 2,6 мм. Обидва гвинти проходять свою гайку наскрізь; між кінцями залишається 4 мм. Тип головки, фактичні гайки та міцність тонкого зенкованого краю треба перевірити на пробному друці.

1. Знеструмити пристрій і від'єднати хвости джгутів, що виходять із потрібної касети. Натягнуті дроти не повинні утримувати касету.
2. Зняти передню панель для доступу, відгвинтити передню утримувальну планку кабельної рамки та витягти касету вперед.
3. Для доступу до проводів зняти лише верхні гвинти й кришки. Кріплення секцій до касети лишається затягнутим.
4. Для зміни маршруту зняти вставки J32, відгвинтити нижні гвинти потрібних секцій, переставити їх разом із A4 на інші позиції сітки або повернути на 90°.
5. Укласти вставки стиків, перевірити проходи, закріпити секції та кришки. Вставити касету й повернути передню планку.

Поки касета вставлена, нижні гвинти недоступні для перестановки. Це свідомо розділяє обслуговування джгута зверху та перекомпонування касети на столі. Між лівою і правою касетами немає незнімної жорсткої перемички.

## Варіанти У Blender

- `BATMAN - modular cable assembly`: складене положення з корпусом, кришками та модельними кріпленнями.
- `BATMAN - modular cable cutaway`: та сама збірка без передньої та бокових панелей, кришки корпуса й кришок каналів.
- `BATMAN - modular cable levels`: рамки поруч; по одній касеті висунуто, передні планки відведені. Це рознесений огляд, не монтажні координати.
- `BATMAN - modular cable kit`: окремо всі дев'ять типів деталей.
- `BATMAN - modular cable alternatives`: два різних маршрути на однакових C92. В обох рівно 2 × S32, 2 × L32, 2 × D32, 6 × A4 та 5 × J32; кришки для огляду не показані.

Екземпляри секцій у збірці використовують спільні mesh-дані відповідного типу. Переміщення або поворот окремого об'єкта не змінює інших екземплярів; редагування його mesh у Edit Mode змінює весь тип. Для унікальної форми спочатку потрібна окрема копія даних.

## Перевірено І Відкладено

[modular-cable-check.json](modular-cable-check.json): чотири однакові касети; 31 секція має опору та співвісні монтажні отвори; 26 стиків мають відкриті проходи й перекрите дно; кінцеві виводи відкриті через підставку й пластину. Перевірені зв'язність маршрутів, замкненість сіток шаблонів, межі корпуса, поверхневі перетини нових деталей між собою та з вихідними деталями. Контакт вставки J32 з її посадковим дном є навмисним і обліковується окремо. Положення 118 компонентів незмінні.

Це **механічний набір і приклади трас, не завершене нове прокладання всіх електричних з'єднань**. Старі індивідуальні лотки, стояки й умовні провідники до цієї збірки не перенесені. Хвости до клем, міжрівневі з'єднання, панельні ділянки та розвантаження натягу потрібно узгодити з новими висотами. Попередні результати довжин джгутів для старого розташування тут не чинні.

Для аналогових B → ADS залишається обмеження 100 мм, для I2C 200 мм. Не вести аналогові сигнали через високу кабельну касету без перевірки довжини: короткі сині маршрути справа на C1 є резервними цифровими прикладами, а не трасами ADS. Аналогові зв'язки потрібно залишити локальними біля плат. Заповнення каналів, силові радіуси, вентиляція над DPS, доступ до запобіжників після встановлення касет, міцність і полегшення пластин потребують перевірки на реальному комплекті. STL для виробництва не випущені.

## Відтворення

У Blender відкрити попередню [модель з опорами](cad/assembly-cable-supported.blend), що містить сцену `BATMAN - detailed assembly` і матеріали каналів. Послідовно виконати [modular_cables.py](modular_cables.py), [check_modular_cables.py](check_modular_cables.py), [modular_cable_views.py](modular_cable_views.py) в одній сесії з заданим `__file__`. Робочий простір скриптів зберігається у `bpy.app.driver_namespace["batman_modular"]`. Наявну модульну сцену генератор не перезаписує.

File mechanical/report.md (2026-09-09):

# Concept Part Report

Status: layout study, NOT released for manufacturing.

Assembly: 220 x 220 x 216 mm. Units: mm; Blender scale_length = 0.001.

Carrier plates: 2 mm; grooves: 2.4 mm; nominal vertical play: 0.4 mm.

Every modelled part fits a 226 mm bounding cube. This is not a slicer or bed-contact check.

Original Blender Scene is preserved. BATMAN - assembly is dimensionally authoritative; BATMAN - open and BATMAN - levels are inspection scenes.

## Unresolved Before Printing

- C1 D12 x 22 mm and C2 6 x 4 x 7 mm are placeholders, not measured values. Confirm quantity, sizes and terminal clearance before choosing lower-level height.
- Module envelopes are simplified; mounting heights and connectors need physical measurements.
- Adjustable supports need final retaining clips/strap slots and fastener attachment. They are not complete holders yet.
- Rear terminal/fuse/DS18B20 openings, OLED bracket and USB alignment remain to be measured. Rear panel is an interface blank.
- Corner posts currently illustrate pilot holes, not final heat-set insert pockets or validated screw depths.
- Frame print orientation, support-free geometry and >=70% bed contact are not verified. Slice and redesign joints before STL release.
- No detailed harness routing or thermal verification. Preserve >=20 mm separation of signal and power harnesses, short ADS cables and ESP antenna clearance.
- The capacitor buffer must remain next to LOAD terminals; the nominal placeholders do not approve long leads.
- Rear carriers require removal of front carriers in the same lane; disconnect harnesses first.
- Final linked per-subassembly files and STL exports are intentionally withheld pending these fit checks.

## Part Geometry

Volume is model geometry only, not filament consumption. Print orientation, bed contact and slicer time: TBD for all parts.

| Part | Bounding box, mm | Volume, cm3 | Closed manifold |
|---|---|---:|---|
| base | 220.0 x 220.0 x 3.0 | 145.091 | True |
| corner post | 9.0 x 9.0 x 210.0 | 14.12 | True |
| corner post.001 | 9.0 x 9.0 x 210.0 | 14.12 | True |
| corner post.002 | 9.0 x 9.0 x 210.0 | 14.12 | True |
| corner post.003 | 9.0 x 9.0 x 210.0 | 14.12 | True |
| L1 logic frame grooved frame | 211.0 x 212.0 x 8.4 | 40.418 | True |
| L1 logic frame removable retainer | 211.0 x 4.0 x 8.4 | 6.779 | True |
| L2 power frame grooved frame | 211.0 x 212.0 x 20.0 | 40.418 | True |
| L2 power frame removable retainer | 211.0 x 4.0 x 8.4 | 6.779 | True |
| L1 carrier A plate | 92.0 x 102.0 x 2.0 | 18.696 | True |
| L1 carrier A pull lip | 24.0 x 3.0 x 7.0 | 0.504 | True |
| A M3 spacer | 8.0 x 8.0 x 5.0 | 0.205 | True |
| A M3 spacer.001 | 8.0 x 8.0 x 5.0 | 0.205 | True |
| A M3 spacer.002 | 8.0 x 8.0 x 5.0 | 0.205 | True |
| A M3 spacer.003 | 8.0 x 8.0 x 5.0 | 0.205 | True |
| L1 carrier B plate | 92.0 x 94.0 x 2.0 | 17.224 | True |
| L1 carrier B pull lip | 24.0 x 3.0 x 7.0 | 0.504 | True |
| B M3 spacer | 8.0 x 8.0 x 5.0 | 0.205 | True |
| B M3 spacer.001 | 8.0 x 8.0 x 5.0 | 0.205 | True |
| B M3 spacer.002 | 8.0 x 8.0 x 5.0 | 0.205 | True |
| B M3 spacer.003 | 8.0 x 8.0 x 5.0 | 0.205 | True |
| L1 carrier C plate | 92.0 x 62.0 x 2.0 | 11.336 | True |
| L1 carrier C pull lip | 24.0 x 3.0 x 7.0 | 0.504 | True |
| C M3 spacer | 8.0 x 8.0 x 5.0 | 0.205 | True |
| C M3 spacer.001 | 8.0 x 8.0 x 5.0 | 0.205 | True |
| C M3 spacer.002 | 8.0 x 8.0 x 5.0 | 0.205 | True |
| C M3 spacer.003 | 8.0 x 8.0 x 5.0 | 0.205 | True |
| L1 carrier D plate | 92.0 x 62.0 x 2.0 | 11.336 | True |
| L1 carrier D pull lip | 24.0 x 3.0 x 7.0 | 0.504 | True |
| D M3 spacer | 8.0 x 8.0 x 5.0 | 0.205 | True |
| D M3 spacer.001 | 8.0 x 8.0 x 5.0 | 0.205 | True |
| D M3 spacer.002 | 8.0 x 8.0 x 5.0 | 0.205 | True |
| D M3 spacer.003 | 8.0 x 8.0 x 5.0 | 0.205 | True |
| L1 carrier ADS pair plate | 92.0 x 32.0 x 2.0 | 5.888 | True |
| L1 carrier ADS pair pull lip | 24.0 x 3.0 x 7.0 | 0.504 | True |
| ADS 0x48 edge support | 28.0 x 3.0 x 5.0 | 0.42 | True |
| ADS 0x48 edge support.001 | 28.0 x 3.0 x 5.0 | 0.42 | True |
| ADS 0x48 adjustable edge saddle | 32.0 x 3.0 x 5.0 | 0.48 | True |
| ADS 0x48 adjustable edge saddle.001 | 32.0 x 3.0 x 5.0 | 0.48 | True |
| ADS 0x49 edge support | 28.0 x 3.0 x 5.0 | 0.42 | True |
| ADS 0x49 edge support.001 | 28.0 x 3.0 x 5.0 | 0.42 | True |
| ADS 0x49 adjustable edge saddle | 32.0 x 3.0 x 5.0 | 0.48 | True |
| ADS 0x49 adjustable edge saddle.001 | 32.0 x 3.0 x 5.0 | 0.48 | True |
| L2 carrier DPS plate | 92.0 x 104.0 x 2.0 | 19.064 | True |
| L2 carrier DPS pull lip | 24.0 x 3.0 x 7.0 | 0.504 | True |
| DPS M3 spacer | 8.0 x 8.0 x 5.0 | 0.205 | True |
| DPS M3 spacer.001 | 8.0 x 8.0 x 5.0 | 0.205 | True |
| DPS M3 spacer.002 | 8.0 x 8.0 x 5.0 | 0.205 | True |
| DPS M3 spacer.003 | 8.0 x 8.0 x 5.0 | 0.205 | True |
| L2 carrier relay supply plate | 92.0 x 93.0 x 2.0 | 17.112 | True |
| L2 carrier relay supply pull lip | 24.0 x 3.0 x 7.0 | 0.504 | True |
| module edge support | 50.0 x 3.0 x 5.0 | 0.75 | True |
| module edge support.001 | 50.0 x 3.0 x 5.0 | 0.75 | True |
| adjustable module edge saddle | 54.0 x 3.0 x 5.0 | 0.81 | True |
| adjustable module edge saddle.001 | 54.0 x 3.0 x 5.0 | 0.81 | True |
| module edge support.002 | 44.0 x 3.0 x 5.0 | 0.66 | True |
| module edge support.003 | 44.0 x 3.0 x 5.0 | 0.66 | True |
| adjustable module edge saddle.002 | 48.0 x 3.0 x 5.0 | 0.72 | True |
| adjustable module edge saddle.003 | 48.0 x 3.0 x 5.0 | 0.72 | True |
| L2 carrier branch 1 plate | 92.0 x 58.0 x 2.0 | 10.672 | True |
| L2 carrier branch 1 pull lip | 24.0 x 3.0 x 7.0 | 0.504 | True |
| module edge support.004 | 3.0 x 8.0 x 5.0 | 0.12 | True |
| module edge support.005 | 3.0 x 8.0 x 5.0 | 0.12 | True |
| provisional adjustable saddle | 3.0 x 23.0 x 5.0 | 0.345 | True |
| provisional adjustable saddle.001 | 3.0 x 23.0 x 5.0 | 0.345 | True |
| module edge support.006 | 3.0 x 8.0 x 5.0 | 0.12 | True |
| module edge support.007 | 3.0 x 8.0 x 5.0 | 0.12 | True |
| provisional adjustable saddle.002 | 3.0 x 23.0 x 5.0 | 0.345 | True |
| provisional adjustable saddle.003 | 3.0 x 23.0 x 5.0 | 0.345 | True |
| module edge support.008 | 3.0 x 8.0 x 5.0 | 0.12 | True |
| module edge support.009 | 3.0 x 8.0 x 5.0 | 0.12 | True |
| provisional adjustable saddle.004 | 3.0 x 23.0 x 5.0 | 0.345 | True |
| provisional adjustable saddle.005 | 3.0 x 23.0 x 5.0 | 0.345 | True |
| L2 carrier branch 2 plate | 92.0 x 58.0 x 2.0 | 10.672 | True |
| L2 carrier branch 2 pull lip | 24.0 x 3.0 x 7.0 | 0.504 | True |
| module edge support.010 | 3.0 x 8.0 x 5.0 | 0.12 | True |
| module edge support.011 | 3.0 x 8.0 x 5.0 | 0.12 | True |
| provisional adjustable saddle.006 | 3.0 x 23.0 x 5.0 | 0.345 | True |
| provisional adjustable saddle.007 | 3.0 x 23.0 x 5.0 | 0.345 | True |
| module edge support.012 | 3.0 x 8.0 x 5.0 | 0.12 | True |
| module edge support.013 | 3.0 x 8.0 x 5.0 | 0.12 | True |
| provisional adjustable saddle.008 | 3.0 x 23.0 x 5.0 | 0.345 | True |
| provisional adjustable saddle.009 | 3.0 x 23.0 x 5.0 | 0.345 | True |
| module edge support.014 | 3.0 x 8.0 x 5.0 | 0.12 | True |
| module edge support.015 | 3.0 x 8.0 x 5.0 | 0.12 | True |
| provisional adjustable saddle.010 | 3.0 x 23.0 x 5.0 | 0.345 | True |
| provisional adjustable saddle.011 | 3.0 x 23.0 x 5.0 | 0.345 | True |
| L2 carrier branch 3 plate | 92.0 x 58.0 x 2.0 | 10.672 | True |
| L2 carrier branch 3 pull lip | 24.0 x 3.0 x 7.0 | 0.504 | True |
| module edge support.016 | 3.0 x 8.0 x 5.0 | 0.12 | True |
| module edge support.017 | 3.0 x 8.0 x 5.0 | 0.12 | True |
| provisional adjustable saddle.012 | 3.0 x 23.0 x 5.0 | 0.345 | True |
| provisional adjustable saddle.013 | 3.0 x 23.0 x 5.0 | 0.345 | True |
| module edge support.018 | 3.0 x 8.0 x 5.0 | 0.12 | True |
| module edge support.019 | 3.0 x 8.0 x 5.0 | 0.12 | True |
| provisional adjustable saddle.014 | 3.0 x 23.0 x 5.0 | 0.345 | True |
| provisional adjustable saddle.015 | 3.0 x 23.0 x 5.0 | 0.345 | True |
| module edge support.020 | 3.0 x 8.0 x 5.0 | 0.12 | True |
| module edge support.021 | 3.0 x 8.0 x 5.0 | 0.12 | True |
| provisional adjustable saddle.016 | 3.0 x 23.0 x 5.0 | 0.345 | True |
| provisional adjustable saddle.017 | 3.0 x 23.0 x 5.0 | 0.345 | True |
| C1 C2 adjustable cradle | 62.0 x 32.0 x 3.0 | 5.585 | True |
| capacitor strap guide | 3.0 x 26.0 x 4.0 | 0.312 | True |
| capacitor strap guide.001 | 3.0 x 26.0 x 4.0 | 0.312 | True |
| wall left | 3.0 x 220.0 x 210.0 | 130.489 | True |
| wall right | 3.0 x 220.0 x 210.0 | 135.437 | True |
| panel back - interface blanks | 214.0 x 3.0 x 210.0 | 134.657 | True |
| panel front | 214.0 x 3.0 x 210.0 | 130.179 | True |
| lid ventilated | 220.0 x 220.0 x 3.0 | 100.163 | True |

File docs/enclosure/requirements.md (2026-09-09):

# Корпус — вимоги

## Актуальне компонування, 2026-09-09

Кабельні траси винесені в окрему механічну ревізію: [../../mechanical/cable-routing.md](../../mechanical/cable-routing.md). Силова магістраль над L2, сигнальні під L2 і над L1, окремі короткі AN48/AN49, задній силовий стояк, UI-канал. Основні силові та сигнальні траси рознесені щонайменше на 20 мм; біля роз'ємів цей зазор окремо не підтверджений. Касети виймаються тільки після від'єднання хвостів, не з натягуванням джгута.

Зовнішній силовий вхід і вихід — **XT60**, за уточненням власника. У поточній деталізованій ревізії також показані XT60 для BAT1/BAT2: чотири парні порти замість восьми одиночних гвинтових клем. Різновид XT60, стать контактів і кріплення треба підтвердити; панельні вирізи поки компонувальні, не виробничі. Нова модель: [../../mechanical/cad/assembly-detailed.blend](../../mechanical/cad/assembly-detailed.blend), перевірки й джерела: [../../mechanical/README.md](../../mechanical/README.md).

Замість старої одноплощинної розкладки нижче прийнято багаторівневий принцип: навісні конденсатори на дні; інші внутрішні модулі на окремих пластинах, які входять у пази рамок рівнів. PCB та готові модулі не переробляються заради перенесення їхніх конденсаторів.

Перший Blender-ескіз: [../../mechanical/README.md](../../mechanical/README.md), модель [../../mechanical/cad/assembly.blend](../../mechanical/cad/assembly.blend). Корпус 220 × 220 × 216 мм, L0 — навісні C1/C2, L1 — A/B/C/D та два ADS, L2 — силові модулі. Габарити C1/C2 тимчасові, не обміряні; остаточна висота нижнього відсіку залежить від уточнення цих компонентів. Ескіз не випущений для друку.

Розділи «Принцип» і «Зони» нижче описують попередній одноплощинний варіант; вони не задають нову механіку. Вимоги до електричних зазорів, доступу, тепла й перевірок залишаються чинними, але ще не всі реалізовані в ескізі.

За цим файлом корпус проєктується з нуля. Розміри модулів — components.md (з позначками джерела); тут — що вмістити, як розкласти, які зазори, як друкувати, що віддати.

## Що вмістити

| Що | Габарит, мм (Д × Ш × В) | Кріплення | Дроти |
|---|---|---|---|
| mDPS, силова плата | 91 × 67 × 40 ✔ | 4 отвори, міжцентрові 86 × 64, M3 на стійках 5 мм | 4 силові клеми з одного торця (IN±, OUT±), роз'єм UART, вентилятор на радіаторі |
| mSW1, mSW2 | 20,3 × 25,4 × 4 + клемники ~10 заввишки | тримач-панелька; на модулі 2 отвори | 2 силові клемники + 2 дюпони |
| mDIO1–3 | 17 × 10 × ~5 | **тримач з кишенею** 17,4 × 10,4, притиск зверху; модуль без отворів для гвинтів | 2 силові дроти напаяні на площадки, виходять уздовж довгої осі |
| mREL2 | 50 × 40 × 19 | 4 отвори, панелька | 6 силових клем + 5 дюпонів |
| mACS1–3 | 17,8 × 20,3 × ~8 за початковою специфікацією, звірити триконтактний екземпляр | панелька за обміром; поруч **клемний блок вузла B** | 2 силові дроти IP+/IP−, 3 сигнальні/живлення: VCC, GND, VOUT |
| плата A ESP | 78 × 78; висота за DevKitC/роз'ємами | 4 × M3, центри за 3,5 мм від країв | GPIO, UART, OLED, SPI; J20/J21 до ADS; CB2/CB4/CB5 |
| плата B analog | 86 × 68; висота за роз'ємами, без ADS | 4 × M3, відступ 3,5 мм | mACS, U_LOAD, CB3/CB6; J32/J33 аналог до ADS ≤10 см |
| J2/J13 ADS1115, окремі | ~28 × 17 кожен; звірити фактичні модулі | два ізольовані тримачі біля B; не підвішувати на дротах | кожен: аналог+GND від B, I²C/живлення від A ≤20 см; локальні ADDR та розв'язка |
| плата C 3V3 | 43 × 33; висота за роз'ємами | 4 × M3, відступ 3,5 мм | CB2/CB3, резерв 3V3 |
| плата D 5V | 63 × 40; висота за клемниками | 4 × M3, відступ 3,5 мм | LM2596, B1/B2, реле, CB4/CB5/CB6 |
| зовнішні клеми LOAD+/GND, C1/C2 навісно | за фактичними клемами й конденсаторами | ізольований тримач із розвантаженням дротів; окремої PCB немає | 8 силових/земляних проводів, окремий сенс LOAD+ |
| mDC5 | 44 × 22 × 15 | 2 отвори, панелька; **не затискати** — гріється | 4 дроти |
| mOLED | 28 × 28 × ~4 | у передній панелі: вікно 26 × 15, 4 отвори M2 або кишеня | 4 дюпони |
| кнопка | 12 мм | передня панель, гайка | 2 дроти |
| тримачі ATO ×4 | ~30 × 15 × 20 кожен | задня панель або основа біля клем | по 2 силові |
| XT60 ×4 | BAT1±, BAT2±, БЖ IN±, LOAD OUT±; точний різновид і стать контактів уточнити | задня панель; фіксація й виріз за конкретним XT60 | дві силові жили на порт, ізоляція чашок і розвантаження кабелю |
| DS18B20 ×2 | кабель Ø4 | прохід у задній панелі з фіксацією | |
| USB-C DevKitC | — | доступ через вікно в передній/бічній панелі без розбирання | |
| вентилятор 50 × 50 (опція) | 50 × 50 × 10–15 | стінка навпроти радіатора DPS: отвір Ø45, 4 × M4 на 40 × 40; заглушка-решітка | 2 дроти |

## Принцип

- **Основа** — плита 3 мм з матрицею отворів під вставки M3, крок 10 мм; кожен модуль — на своїй **панельці** (2 мм + стійки 5 мм), панелька тримається 1–2 гвинтами в матрицю.
- **Стінки** — плоскі плити 3 мм у пазах основи, прикручені M3 у кутові стійки; передня й задня — знімні окремо.
- **Кришка** — решітка; корпус працездатний без неї.
- Габарит — у межах стола принтера (**≤ 226 мм** по кожній стороні для кожної деталі); корпус може бути більший за деталь, якщо основа складається з двох плит на замках.

## Зони (вигляд згори, орієнтовно)

```
задня панель: [BAT1±][BAT2±][БЖ±][LOAD±] [F1][F2][Fchg][Fout] [DS18B20 ×2]
┌───────────────────────────────────────────────────────────────┐
│ mACS1 + блок B1   mSW1   mDIO1        клеми + навісний буфер   │  силова зона
│ mACS2 + блок B2   mSW2   mDIO2        mACS3                   │
│                    mREL2   mDIO3                              │
│ ─ ─ ─ ─ ─ лоток сигнальних дюпонів ─ ─ ─ ─ ─ ─ ─ ─ ─ ─ ─ ─ ─ │
│ mDPS силова плата (радіатор до стінки з вентилятором)         │
│ ─ ─ ─ ─ ─ ─ ─ ─ ─ ─ ─ ─ ─ ─ ─ ─ ─ ─ ─ ─ ─ ─ ─ ─ ─ ─ ─ ─ ─ ─ ─ │
│ A (ESP)   B (RC) + 2×ADS   C (3V3)   D (5V)   mDC5        │  сигнальна зона
└───────────────────────────────────────────────────────────────┘
передня панель: [OLED][кнопка][вікно USB-C]
```

Правила зон: силові дроти не заходять у сигнальну зону, крім L01/L02/P28 (тонкі); сигнальні дюпони йдуть своїм лотком ≥ 20 мм від силових; DPS між зонами, бо в нього і силове (клеми), і сигнальне (UART).

## Зазори

ADS1115 більше не встановлюються на PCB B: передбачити окремі ізольовані тримачі та короткі аналогові джгути. Фактичні висоти й посадку DevKitC звірити за PDF 1:1. Біля антени ESP не ставити метал, сусідні PCB або джгути. Відстані між платами у KiCad — для документації, не готове компонування корпусу.

| Що | Мінімум |
|---|---|
| над найвищим модулем до кришки | 15 мм |
| над **прямою** гребінкою під дюпон | 30 мм (корпус ~15 + згин джгута) |
| перед **кутовою** гребінкою вбік | 25 мм + канал далі |
| за клемою / тримачем ATO під дріт 2,5 мм² | 12 мм; радіус згину дроту ≥ 15 мм |
| між панельками | 3 мм |
| навколо mDC5 і радіатора DPS | 10 мм повітря |
| резерв площі | ~1/4 основи |
| тримач XL74610: кишеня | +0,4 мм на сторону, притиск не на компоненти, а на краї плати |

## Тепло

- DPS: штатний вентилятор дме через радіатор — радіатор до стінки з отвором під вентилятор 50 × 50 (спочатку закритим решіткою); впуск — щілини знизу бічних стінок, вихід — решітка кришки.
- mDC5 (~0,6 Вт), XL74610 (~1 Вт при 10 А кожен), mSW (0,9 Вт при 10 А), контакти mREL2 (~3 Вт при 10 А) — пасивно, з повітрям навколо; mREL2 не накривати іншими панельками.
- Тепловий тест — крок 7.3 плану; за ним вирішується вентилятор.

## Доступ

- Запобіжники, клеми, DS18B20 — ззаду, без розбирання.
- USB-C, кнопка, OLED — спереду.
- Повзунки mSW1/mSW2 — видно й досяжно при знятій кришці (це «стан при мертвому контролері», їх переставляють руками).
- Тример mDC5 — досяжний викруткою при знятій кришці.

## Друк

- PETG; усі деталі — плоскі плити на стіл, прилягання до стола ≥ 70 % (мета 90–100 %), без підпорок.
- Товщини: основа й стінки 3 мм, панельки 2 мм, стійки 5 мм Ø8; отвори під вставки M3 — Ø4,0 (підбирається тестовим друком), під гвинт M3 наскрізь — Ø3,4, M4 — Ø4,5, M2 — Ø2,4.
- Допуски: кишені +0,4 мм на сторону; пази під плити 3 мм — 3,3 мм; усі підганяються за 3.2.4 плану, результат записується сюди.
- Пріоритет: міцність → час друку → філамент.
- Кожна деталь — окремий STL; назви: `base.stl`, `wall_left.stl`, `wall_right.stl`, `panel_front.stl`, `panel_back.stl`, `lid.stl`, `post_corner.stl` (×4), `mount_<модуль>.stl` (панельки), `holder_xl74610.stl` (×3), `fan_blank.stl`.

## Що віддається (mechanical/)

- `cad/` — Blender: по файлу на вузол + `assembly.blend` з лінками; колекція «габарити модулів» для перевірки перетинів.
- `stl/` — STL кожної деталі.
- `report.md` — на кожну деталь: габарит, об'єм, прилягання до стола, орієнтовний час друку зі слайсера (заповнює той, хто друкує), примітки.
- Скрипт перевірки (`check.py` у Blender): перетини, прилягання ≥ 70 %, габарит ≤ 226 мм.

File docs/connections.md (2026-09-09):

# З'єднання

Кожен провід має номер, кожен GPIO — одну лінію. A — ESP із двома портами ADS, B — аналогові входи/фільтри без I²C, C — розподіл 3,3 В, D — розподіл 5 В. Обидва ADS1115 зовнішні: аналог від B, живлення та I²C від A. Силовий буфер C1/C2 зовнішній. Кабелі CB2–CB6 і чотири кабелі ADS — [hardware/README.md](../hardware/README.md); CB1 вилучено. P01–P28 не змінені.

## Вузли

| Вузол | Що це | Де фізично |
|---|---|---|
| BAT1+, BAT2+ | плюси акумуляторів на вході корпусу | силові клеми задньої панелі |
| **B1, B2** | вузол гілки: після датчика струму, перед ключем; сюди ж приходить заряд і звідси живиться логіка | клемний блок на панельці датчика (2 клеми: від mACS IP+, далі на mSW VIN, mREL2 NO, тонкий дріт на плату A) |
| CHG | вихід mDIO3 = спільна точка COM обох реле | перемичка між COM1 і COM2 на клемнику mREL2 |
| **LOAD+** | спільна шина навантаження після діодів | зовнішній силовий клемник XLP |
| LOAD_OUT+ | після mACS3 і Fout | силова клема задньої панелі |
| **GND** | мінус усього: обидва акумулятори, DPS (IN− і OUT− у нього спільні), навантаження, логіка | **одна** зовнішня мінус-шина XGND; логіка сідає на неї одним проводом |
| +5V | вихід mDC5 | D.X3 — зірка для A/DevKitC, mREL2 VCC і JD-VCC |
| +3V3 | стабілізатор DevKitC | A.J20/J21 → зовнішні ADS; A → C → B живлення датчиків через Q3; OLED і підтяжки на A |

У KiCad мідна зірка **NT1 біля X3** розділяє +5V на `+5V_RELAY_VCC` (J8.4) і `+5V_RELAY_COIL` (J8.5). Це дві окремі гілки від зірки, а не додаткові джерела; об'єднувати їх біля реле не можна. Проводам L07/L08 відповідають ці дві мережі.

P28 йде від XGND1 до D.X1.3; тонкий U_LOAD_SENSE від XLP1 до B.X5.1. Позначення XGND1/XLP1 та інші числові суфікси KiCad мають вихідні назви у полі Alias. Дільники B1/B2 одержують напругу кабелем D.X6 → B.X8. Через сигнальні кабелі існують додаткові шляхи GND; один P28 не гарантує відсутності петель.

## Силові кола

Переріз — мідь, короткі відрізки всередині корпусу; гілки й заряд рахуємо на 10 А тривало, вихід — на 10 А з піками. Кольори: **червоний** — плюс до ключа, **помаранчевий** — плюс після ключа/діода (шина), **чорний** — мінус, **жовтий** — заряд.

| № | Від | До | Переріз | Струм | Примітка |
|---|---|---|---|---|---|
| P01 | клема BAT1+ | F1 (ATO 15 А) | 2,5 мм² | 10 А | |
| P02 | F1 | mACS1 **IP−** | 2,5 | 10 | орієнтація: від запобіжника в IP−, тоді розряд читається нижче центру, заряд — вище |
| P03 | mACS1 **IP+** | вузол B1 (клемний блок) | 2,5 | 10 | |
| P04 | B1 | mSW1 VIN | 2,5 | 10 | |
| P05 | mSW1 VOUT | mDIO1 **анод** (площадка, напаяти) | 2,5 | 10 | напрямок — символ діода на звороті модуля |
| P06 | mDIO1 **катод** (площадка) | XLP, клема LOAD+ | 2,5 | 10 | |
| P07 | клема BAT2+ | F2 (ATO 15 А) | 2,5 | 10 | |
| P08 | F2 | mACS2 IP− | 2,5 | 10 | |
| P09 | mACS2 IP+ | вузол B2 | 2,5 | 10 | |
| P10 | B2 | mSW2 VIN | 2,5 | 10 | |
| P11 | mSW2 VOUT | mDIO2 анод | 2,5 | 10 | |
| P12 | mDIO2 катод | XLP, клема LOAD+ | 2,5 | 10 | |
| P13 | XLP, LOAD+ | mACS3 **IP−** | 2,5 | 10 | струм навантаження читається нижче центру: 1,65 → 0,75 В при 10 А |
| P14 | mACS3 **IP+** | Fout (ATO 15 А) | 2,5 | 10 | |
| P15 | Fout | клема LOAD_OUT+ | 2,5 | 10 | |
| P16 | DPS OUT+ | Fchg (ATO 15 А) | 2,5 | 10 | |
| P17 | Fchg | mDIO3 анод | 2,5 | 10 | |
| P18 | mDIO3 катод | mREL2 COM1 | 2,5 | 10 | |
| P19 | mREL2 COM1 | mREL2 COM2 | 2,5 | 10 | перемичка на клемнику реле = вузол CHG |
| P20 | mREL2 **NO1** | вузол B1 | 2,5 | 10 | NC не використовуються |
| P21 | mREL2 **NO2** | вузол B2 | 2,5 | 10 | |
| P22 | клема БЖ+ | DPS IN+ | 2,5 | 10 | 33 В |
| P23 | клема БЖ− | DPS IN− | 2,5 | 10 | |
| P24 | DPS OUT− | XGND, мінус-шина | 2,5 | 10 | у DPS IN− і OUT− спільні — усе одно вести окремим дротом |
| P25 | клема BAT1− | XGND, мінус-шина | 2,5 | 10 | |
| P26 | клема BAT2− | XGND, мінус-шина | 2,5 | 10 | |
| P27 | XGND, мінус-шина | клема LOAD_OUT− | 2,5 | 10 | |
| P28 | XGND, мінус-шина | D.X1.3 GND | 0,75 | < 1 | основний провід землі логіки; перевірити паралельні шляхи через UART |

Зовнішній клемний вузол: LOAD+ (P06, P12, P13) і мінус-шина (P24–P28). C1 100 мкФ / 50 В і C2 100 нФ монтуються навісно між ними короткими виводами з ізоляцією та механічним кріпленням. D3 не встановлювати до вибору захисту. Окрема PCB для буфера не потрібна.

## Живлення логіки

| № | Від | До | Переріз | Примітка |
|---|---|---|---|---|
| L01 | вузол B1 | D.X1.1 **B1** | 0,5 мм² | VD1 і через CB6 дільник U_B1 на B |
| L02 | вузол B2 | D.X1.2 **B2** | 0,5 | VD2 і через CB6 дільник U_B2 на B |
| L03 | D.X2.1 **VIN_DC** | mDC5 IN+ | 0,5 | катоди VD1/VD2 |
| L04 | D.X2.2 GND | mDC5 IN− | 0,5 | |
| L05 | mDC5 OUT+ | D.X3.1 **+5V** | 0,5 | виставити 5,0 В **до** підключення |
| L06 | mDC5 OUT− | D.X3.2 GND | 0,5 | |
| L07 | D.J8.4 | mREL2 **VCC** | DuPont | опто |
| L08 | D.J8.5 | mREL2 **JD-VCC** | DuPont | обмотки; перемичка VCC–JD-VCC **знята** |
| L09 | D.J8.2 | mREL2 GND | DuPont | |
| L10 | плата A, +5V | DevKitC **VIN** | доріжка | через гніздо |
| L11 | DevKitC 3V3 | ADS через A.J20/J21, C через CB2; OLED і підтяжки на A | доріжки + кабелі | бюджет перевірити за реальним LDO, не підключати інше джерело 3,3 В |
| L12 | C.Q3 колектор (**+3V3_SENS**) | B.J3/J4/J5 VCC через CB3 | DuPont | GPIO33 (J1.8) керує через CB2; FAULT не підключений |

## Сигнали і розкладка пінів ESP32

Правила розкладки: GPIO 6–11 — flash, не чіпати; 0, 2, 12, 15 — strapping, без навантажень, що впливають на старт; 5 і 14 можуть давати імпульс при ресеті, перевірити на стенді; 34–39 — лише входи без підтяжок, у цій ревізії NC; ADC ESP не використовується; 1/3 — USB-консоль.

| GPIO | Сигнал | Напрям | Куди | Стан у ресеті → що це означає |
|---|---|---|---|---|
| 25 | SW1_ON | вихід | mSW1 пін ON | Hi-Z → ключ OFF (внутрішня підтяжка модуля вниз) |
| 26 | SW2_ON | вихід | mSW2 пін ON | Hi-Z → OFF |
| 27 | K1 | вихід | база NPN Q1 → mREL2 IN1 | Hi-Z, 10 кОм на землю → реле OFF |
| 13 | K2 | вихід | база NPN Q2 → mREL2 IN2 | те саме |
| 33 | SENS_PWR | вихід, **активний низький** | J1.8 → J22.3 міддю; CB2 → база PNP Q3 (4,7 кОм), емітер 3V3, колектор → VCC датчиків | Hi-Z, 10 кОм база–емітер → датчики **без живлення** до ініціалізації; перевірити старт на стенді |
| 21 | SDA | I2C | зовнішні ADS1115 0x48/0x49 через A.J20/J21; OLED 0x3C | одна шина, одна пара R16/R17 4,7k на A; врахувати підтяжки модулів |
| 22 | SCL | I2C | те саме | |
| 17 | DPS_TX | UART2 TX | DPS порт **R** (RXI) | |
| 16 | DPS_RX | UART2 RX | DPS порт **T** (TXO) | |
| 4 | OW | 1-Wire | DS18B20 ×2, DATA | підтяжка 4,7 кОм до 3V3 |
| 14 | — | резерв, NC | J1.12 не підключений | SENS_PWR перенесений на GPIO33/J1.8 |
| 32 | BTN | вхід, підтяжка | кнопка на панелі → GND | |
| 34, 39 | — | резерв, NC | навантаження вимірює зовнішній J13 через B.J33 | ADC ESP не використовується |
| 18, 19, 23, 5 | SCK, MISO, MOSI, CS | резерв | SPI — SD-модуль, якщо колись | гребінка на платі A, не розведена далі |
| 35, 36 | — | резерв | входи | |
| 0, 2, 12, 15 | — | не використовуємо | strapping | |
| 1, 3 | USB | UART0 | консоль/прошивка через USB-C | |

ADS1115 (I2C 0x48, ADDR → GND), PGA ±4,096 В, 475 SPS, по колу:

| Канал | Сигнал | Звідки | Що бачить |
|---|---|---|---|
| A0 | I_B1 | mACS1 VIOUT через RC 1 кОм + 1 мкФ | 1,65 В ± 0,090 В/А |
| A1 | I_B2 | mACS2 VIOUT через RC | те саме |
| A2 | U_B1 | дільник 100k / 10k з клеми B1 + 100 нФ | 30 В → 2,73 В |
| A3 | U_B2 | дільник 100k / 10k з клеми B2 | те саме |

## Роз'єми Плат A–D

Нижче порядок **контактів PCB від 1 до N**, не порядок зовнішніх модулів. Кабелі — [cable-map.csv](../hardware/batman/output/cable-map.csv), координати — [pinout.csv](../hardware/batman/output/pinout.csv). J1/J6/J7/J9/J10/J11/J12/J20/J21/X4 на A; J3/J4/J5/J25/J32/J33/X5/X8 на B; J8/X1/X2/X3 на D. J2/J13 зовнішні, посадок на PCB немає. GPIO та канали обох ADS збережені.

Зовнішні J2 0x48 (ADDR→GND) та J13 0x49 (ADDR→VDD) мають PGA ±4,096 В. J13: A0=I_LOAD, A1=U_LOAD, A2/A3 локально на GND. На обох ALRT NC. Локальна розв'язка 100 нФ C6 біля J2, C10 біля J13: перевірити на модулі або додати. Заводську перемичку ADDR→GND другого ADS розімкнути перед з'єднанням із VDD.

CB2–CB6 — [міжплатні кабелі](../hardware/batman/output/interboard-cables.csv), п'ять кабелів/13 жил. C.J30=3V3/GND і D.J31=5V/GND — резервні виходи. C.J23: 3V3/GND/SENS_PWR від ESP; C.J24: GND/3V3_SENS на B.J25. Старий CB1 прибрано; J21 тепер на A. Кабелі попередніх J20/J21 та J24/J25 не використовувати.

| Порт | Контакти 1…N | Куди |
|---|---|---|
| A.J20 | 3V3, GND, SCL, SDA | зовнішній J2: VDD, GND, SCL, SDA |
| A.J21 | 3V3, GND, SCL, SDA | зовнішній J13: VDD, GND, SCL, SDA |
| B.J32 | I_B1, I_B2, U_B1, U_B2, GND | J2: A0, A1, A2, A3, GND |
| B.J33 | I_LOAD, U_LOAD, GND | J13: A0, A1, GND |

Чотири кабелі ADS, 16 жил. На кожному ADS землі двох кабелів звести в одну надійну локальну точку. Аналогові джгути початково до 10 см, I²C до 20 см; перевірити шум і фронти. З'єднувати тільки без живлення; не подавати аналогову напругу на знеструмлений ADS.

mACS мають тільки три низьковольтні проводи: живлення, GND, VOUT. У CAD живлення назване VCC і прийнято 3,3 В за вихідною специфікацією ACS711EX. Позначення користувача `VSS` не вважається підтвердженням позитивного живлення: звірити модуль до підключення; 5-вольтовий датчик не є прямою заміною. FAULT не підключений; GPIO33 керує SENS_PWR, GPIO14 вільний.

| Поз. | Тип | Контакти | Куди |
|---|---|---|---|
| J1 | 2 × 19 гнізд 2,54 | DevKitC | знімний |
| J2 / J13 | зовнішні модулі, не роз'єми PCB | ADS1115 `VDD GND SCL SDA ADDR ALRT A0 A1 A2 A3` | локальні ADDR GND / VDD; монтаж за таблицею вище |
| J3, J4 | 3 пін | mACS1, mACS2: `VOUT GND VCC` | VCC = +3V3_SENS |
| J5 | 3 пін | mACS3: `VCC VOUT GND` | порядок відрізняється від J3/J4 |
| J6, J7 | 2 пін | mSW1, mSW2: `GND ON` | |
| J8 | 5 пін | mREL2: `IN1 GND IN2 VCC JD-VCC` | VCC і JD-VCC — дві окремі доріжки від клеми +5V |
| J9 | 3 пін | DPS: `TX RX GND` (TX = GPIO 17 → R, RX = GPIO 16 ← T) | V DPS не підключати |
| J10 | 4 пін | OLED: `VDD SCL SDA GND` | на OLED підключати за назвами контактів, не прямим шлейфом |
| J11 | 2 пін | `GND BTN` | кнопка без полярності |
| J12 | 6 пін | резерв SPI: `MOSI GND MISO SCK CS 3V3` | біля нижнього краю PCB |
| X1 | клемник 3 | `B1 B2 GND` | тонкі сенс/живлення від вузлів (L01, L02, P28) |
| X2 | клемник 2 | `VIN_DC GND` | на mDC5 IN (L03, L04) |
| X3 | клемник 2 | `+5V GND` | з mDC5 OUT (L05, L06) |
| X4 | клемник 3 | DS18B20 ×2: `DATA 3V3 GND` | обидва датчики паралельно на OW |
| X5 | клемник 1 | `U_LOAD_SENSE` | тонкий дріт з зовнішньої клеми LOAD+ |

Розподіл: A — Q1/Q2, R12–R18; B — R1–R9, C3–C5, C7–C9; C — Q3, R10/R11, C11/C12; D — VD1/VD2, NT1, C13. C6/C10 біля зовнішніх ADS. Резистори SMD 1206; конденсатори на PCB мають суміщені THT/1206 місця, один корпус на позицію. На D осьові 1N5819; SS34 потребує іншої посадки.

## Шкала АЦП і калібрування — зведено

| Величина | Тракт | Номінальний коефіцієнт | Що калібрувати |
|---|---|---|---|
| I_B1, I_B2 | ACS711EX → RC → ADS1115 ±4,096 | (V − 1,650) / 0,090 А; LSB = 1,39 мА | нуль (автонуль + ручний), масштаб проти DPS IOUT і DSN-VC288 |
| U_B1, U_B2 | 100k/10k → ADS1115 | V × 11; LSB = 1,4 мВ | масштаб проти мультиметра (допуск резисторів 1 % → похибка до 2 %) |
| U_LOAD | 100k/4,7k → ADS1115 0x49 A1 | V × (104,7 / 4,7) | масштаб проти мультиметра; LSB 125 мкВ на вході ADS |
| I_LOAD | ACS711EX → RC → ADS1115 0x49 A0 | (1,650 − V) / 0,090 А | контрольний канал, нуль ручний; знак збережений |
| T1, T2 | DS18B20 | пряме | нічого |

## Мінуси й розведення проводів у корпусі

- Мінус-шина одна, зовнішня XGND; силові мінуси — окремими дротами до неї, не ланцюжком.
- Основний GND логіки — P28 на D; датчики через B, реле через D, DPS-UART через A. Міжплатні кабелі створюють паралельні шляхи GND; перевірити струми повернення, не називати це гарантовано безпетльовою зіркою.
- Сигнальні дюпони (J3–J9) — своїм лотком, ≥ 20 мм від силових дротів, силові не перетинати; де перетин неминучий — під прямим кутом.
- DPS-UART і 1-Wire — виті пари з GND.
- Датчики ACS711EX — на панельках гілок, сигнали до B ≤ 25 см; аналог B–ADS початково ≤ 10 см, I²C ADS–A ≤ 20 см, перевірити шум і фронти.

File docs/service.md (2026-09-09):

# Сервіс — вимоги

Кросплатформений сервіс збору й аналітики: Python 3.11+, FastAPI, SQLite, один процес. Windows зараз, Raspberry Pi 4 потім, Docker опційно. Протокол з пристроєм — protocol.md.

## Що робить

1. Знаходить пристрої (mDNS, UDP-broadcast, ручний IP), реєструє, каже їм, куди слати (`POST /sink`).
2. Приймає телеметрію й події, зберігає сирі записи, стежить за розривами.
3. Рахує агрегати: година / доба / цикл — А·год і Вт·год у/з кожного акумулятора, ефективність, час у станах, мін/макс.
4. Показує: стан, графіки, таблиці циклів, події; експорт CSV.
5. Пересилає команди й конфіг на пристрій.
6. Сповіщає про FAULT, втрату зв'язку, низький SoC.

## Структура

```
service/
  batman_service/
    main.py          FastAPI-застосунок, запуск uvicorn
    config.py        читання config.toml + змінні середовища
    db.py            SQLite (sqlite3 або SQLAlchemy Core), міграції в migrations/
    discovery.py     mDNS (zeroconf) + UDP + ручний список
    ingest.py        POST /api/ingest — приймання, валідація, запис
    aggregate.py     періодичні агрегати, детекція циклів
    devices.py       реєстр, проксі команд на пристрій
    notify.py        журнал, e-mail, Telegram
    web/             сторінки (Jinja2) + статика; графіки — uPlot або Chart.js, локально, без CDN
  migrations/        001_init.sql …
  config.toml.example
  deploy/            nssm-install.ps1, batman.service (systemd), Dockerfile
  tests/
  emulator/          device_emulator.py — фейковий пристрій: шле телеметрію, відповідає на REST
```

## БД (SQLite, WAL)

| Таблиця | Колонки (головне) | Примітка |
|---|---|---|
| `device` | `id` (text, PK, = `id` пристрою), `name`, `ip`, `port`, `fw`, `first_seen`, `last_seen`, `sink_ok`, `config_json` | |
| `boot` | `id`, `device_id`, `t_service`, `uptime0`, `reset_reason` | для перерахунку `uptime → час` |
| `sample` | `id`, `device_id`, `t` (unix ms, час сервісу), `seq`, `uptime`, `state`, `b1_u`, `b1_i`, `b1_t`, `b1_soc`, `b1_sw`, `b1_ah_in`, `b1_ah_out`, `b1_wh_in`, `b1_wh_out`, `b2_*` (те саме), `load_u`, `load_i`, `dps_uin`, `dps_uout`, `dps_iout`, `dps_uset`, `dps_iset`, `dps_on`, `dps_cc`, `dps_prot`, `dps_k`, `rssi`, `warn` (text), `raw` (json) | індекс `(device_id, t)`; `raw` — повний JSON на випадок нових полів |
| `event` | `id`, `device_id`, `t`, `seq`, `uptime`, `event`, `from_state`, `to_state`, `reason`, `data` (json) | індекс `(device_id, t)` |
| `gap` | `device_id`, `t_from`, `t_to`, `seq_from`, `seq_to`, `kind` (`no_data` / `seq_gap` / `reboot`) | розриви |
| `agg_hour`, `agg_day` | `device_id`, `bat` (1/2), `t_start`, `ah_in`, `ah_out`, `wh_in`, `wh_out`, `u_min`, `u_max`, `u_avg`, `i_min`, `i_max`, `t_min`, `t_max`, `soc_min`, `soc_max`, `s_charge`, `s_float`, `s_idle`, `s_fault` (секунди в станах), `samples`, `gaps` | |
| `cycle` | `id`, `device_id`, `bat`, `t_start`, `t_end`, `ah_in`, `ah_out`, `wh_in`, `wh_out`, `eff` (= `ah_out_prev / ah_in`), `duration_s`, `end_reason`, `u_start`, `i_tail` | з подій `state` + `cycle_complete` |
| `notification` | `id`, `t`, `device_id`, `kind`, `text`, `sent` | |

Ретенція: сирі `sample` старші за `retention.raw_days` (типово 90) проріджуються до 1 запису на хвилину; старші за `retention.min_days` (365) — видаляються; агрегати живуть вічно. `VACUUM` раз на тиждень уночі.

## Приймання

`POST /api/ingest` — тіло: масив повідомлень (protocol.md). На кожне:
- валідація `v`, `id`, `type`; невідомий `id` → авто-реєстрація зі статусом `unclaimed`;
- `t = now()`; при `event: boot` — новий запис у `boot`; для повідомлень з буфера (прийшли пачкою) `t` рахується як `now − (uptime_last − uptime_msg)`;
- `seq` порівнюється з попереднім: пропуск → `gap kind=seq_gap`; `uptime` менший за попередній без `boot` → `gap kind=reboot`;
- запис у `sample`/`event`, оновлення `device.last_seen`.
Відповідь `200 {"ok":true,"accepted":N}`. Без відповіді пристрій буферизує — тому обробка має бути швидкою (< 50 мс), агрегати рахуються окремо.

Контроль зв'язку: фонова задача раз на 10 с — пристрій без телеметрії довше `3 × interval_s + 5` с → `gap kind=no_data` + сповіщення `offline`; повернення → закриття gap.

## Пошук і реєстрація

- `zeroconf` слухає `_batman._tcp`; UDP-broadcast `BATMAN?` на 47474 раз на 60 с (і по кнопці «Знайти»); ручне додавання за IP.
- Знайдений пристрій → `device` зі статусом `discovered`; користувач натискає «Підключити» → сервіс робить `POST /sink` зі своєю адресою (`public_url` з конфігу, бо адресу приймача пристрій має бачити зі свого боку мережі) і `interval_s`; успіх → `sink_ok = 1`.
- Раз на 10 хв сервіс перевіряє `GET /status` пристрою: якщо `sink` там не наш — повторює `POST /sink` (пристрій міг перезавантажитись без NVS або хтось перехопив).

## Агрегати

Задача раз на хвилину: для кожного пристрою й гілки добудовує `agg_hour` для завершених годин (і поточну — з позначкою `partial`), раз на добу — `agg_day`. Джерело — сирі `sample`: інтегрування `bX_i` трапеціями по `t` (а не різниця лічильників пристрою — щоб розриви й ресети не псували; лічильники пристрою — для звірки, розбіжність > 3 % → попередження в журнал). Час у станах — за `state` у семплах.

Цикли: від події `state → CHG_Bx_*` (старт) до `cycle_complete` або `state → IDLE` з іншої причини (`end_reason`). `eff` — А·год, віддані з моменту попереднього «100 %», поділені на А·год, прийняті в цьому циклі.

## Сторінки

| Шлях | Що |
|---|---|
| `/` | усі пристрої: стан, U/I/SoC обох гілок, DPS, останнє повідомлення, попередження; автооновлення раз на 2 с (SSE `/api/stream`) |
| `/d/{id}` | пристрій: живі графіки за останні 1 год / 24 год / 7 діб — U, I, SoC, T обох гілок, U/I навантаження, DPS UIN/UOUT/IOUT; смуга станів; події |
| `/d/{id}/cycles` | таблиця циклів з фільтрами, ефективність, тривалість; клік → графік циклу |
| `/d/{id}/events` | події й попередження, фільтр за типом |
| `/d/{id}/control` | старт/стоп заряду, ключі, скидання FAULT, калібрування (з підказкою, що для цього треба), конфіг (форма за `GET /config`), OTA (завантажити `.bin`) |
| `/d/{id}/export` | CSV: семпли за період (з проріджуванням), агрегати, цикли, події |
| `/settings` | сервіс: `public_url`, ретенція, сповіщення, ручне додавання пристрою |

Мінімум JS, без збірки фронтенду: Jinja2 + uPlot (одна статика). Графіки — з `agg_hour` для довгих періодів, із сирих — для ≤ 24 год.

## Команди

`POST /api/d/{id}/control` → проксі на `POST http://<ip>/control` з тим самим тілом; відповідь пристрою повертається як є; кожна команда — запис у `event` з `event=command`, `data={cmd, by, result}`. Те саме для `/config`.

## Сповіщення

Канали: журнал (завжди), e-mail (SMTP), Telegram (bot token + chat id). Події: `fault` (негайно), `offline` довше 5 хв, `soc < soc_alert` (типово 20 %), `warn` новий код (раз на добу на код), `cycle_complete` (опційно). Антидребезг: одне сповіщення на подію, «відбій» окремо.

## Конфіг сервісу (`config.toml`)

```toml
[server]      host = "0.0.0.0"   port = 8000   public_url = "http://192.168.1.10:8000"
[db]          path = "data/batman.db"
[discovery]   mdns = true   udp = true   udp_interval_s = 60
[retention]   raw_days = 90   min_days = 365
[alerts]      soc_alert = 20   offline_min = 5
[alerts.telegram]  enabled = false   token = ""   chat_id = ""
[alerts.email]     enabled = false   smtp = ""   from = ""   to = ""
```

## Розгортання

- **Windows:** `deploy/nssm-install.ps1` — створює службу `batman` (`python -m batman_service`), лог у `logs/`; альтернатива — Task Scheduler при вході.
- **Raspberry Pi 4:** `deploy/batman.service` (systemd, `Restart=always`, `User=batman`), venv у `/opt/batman`.
- **Docker:** `Dockerfile` + том для `data/`; `network_mode: host` — інакше mDNS/UDP не працюють.
- Оновлення: `git pull` + міграції при старті (номер схеми в таблиці `meta`).

## Емулятор

`emulator/device_emulator.py --id test01 --sink http://localhost:8000/api/ingest` — імітує пристрій за protocol.md: відповідає на UDP і REST, шле телеметрію з правдоподібними кривими заряду/розряду, реагує на команди. Ним сервіс доводиться до готового стану без заліза (кроки 5.1–5.5 плану).

## Тести

`pytest`: валідація ingest (порядок, буфер, пропуски seq, ресет), агрегати на синтетичних даних (відома площа під кривою), детекція циклів, міграції з порожньої БД, емулятор ↔ сервіс end-to-end.

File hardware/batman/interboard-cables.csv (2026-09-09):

Cable | From | Pin | To | Pin_to | Net
CB2 | J22 | 1 | J23 | 1 | +3V3
CB2 | J22 | 2 | J23 | 2 | GND
CB2 | J22 | 3 | J23 | 3 | SENS_PWR
CB3 | J24 | 1 | J25 | 1 | GND
CB3 | J24 | 2 | J25 | 2 | +3V3_SENS
CB4 | J26 | 1 | J27 | 1 | +5V
CB4 | J26 | 2 | J27 | 2 | GND
CB5 | J28 | 1 | J29 | 1 | RELAY_IN1
CB5 | J28 | 2 | J29 | 2 | RELAY_IN2
CB5 | J28 | 3 | J29 | 3 | GND
CB6 | X6 | 1 | X8 | 1 | B1
CB6 | X6 | 2 | X8 | 2 | B2
CB6 | X6 | 3 | X8 | 3 | GND

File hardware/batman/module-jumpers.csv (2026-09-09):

Ref | Board | Net | X1_mm | Y1_mm | X2_mm | Y2_mm | Min_length_mm
WA1 | A | +3V3 | 64.0 | 24.1 | 64.0 | 12.0 | 12.1
WA2 | A | BTN | 12.54 | 39.0 | 28.0 | 27.24 | 19.42
WA3 | A | SCL | 64.0 | 17.08 | 65.54 | 8.0 | 9.21
WA4 | A | SCL | 72.0 | 17.08 | 72.0 | 27.9 | 10.82

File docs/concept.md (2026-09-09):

# Концепція

Що будуємо, як вимірюємо, рахуємо й куди відправляємо. Основа — наявні модулі; модульна ревізія потребує додаткового ADS1115. Характеристики й підключення уточнюються в components.md / connections.md.

## Задача

- Два акумулятори: **Bat1 — LiFePO₄ 8S, 50 А·год** (номінал 25,6 В, заряд 28,8 В), **Bat2 — свинець 24 В, 65 А·год за паспортом** (2 × 12 В, absorption 28,8 В, float 27,2–27,6 В).
- **Розряд:** кожен акумулятор → запобіжник → датчик струму → ключ → ідеальний діод → спільна шина навантаження. Ключ дає змогу відрізати будь-який акумулятор у потрібний момент. Навантаження зазвичай ~100 Вт (≈4–5 А), рідко 7 А, піки до 10 А — малоймовірні.
- **Заряд:** один DPS5015 від зовнішнього БЖ 33 В / 10 А; вихід DPS механічними реле підключається до одного з акумуляторів. Профіль (CC/CV для LiFePO₄, стадійний для свинцю) веде прошивка по Modbus.
- **Облік:** для кожного акумулятора окремо — скільки А·год і Вт·год прийняв, скільки віддав. На пристрої — поточний стан і наростаючі лічильники; **історія, аналітика й графіки — на віддаленому сервісі**, куди пристрій постійно шле телеметрію по Wi-Fi.
- Це playground: усе має зніматися й замінятися, у корпусі — запас місця.

## Схема ядра

```
                     ┌──── DPS5015 OUT+ ──[mDIO3]───┬── K1 (mREL2·1) ──┐
   БЖ 33 В / 10 А ───┤ IN                             └── K2 (mREL2·2) ──┼─┐
                     └──── UART (Modbus) ── mMCU                        │ │
                                                                        │ │
Bat1 (LiFePO₄) ─[F1]─[mACS1]─── вузол B1 ───────────────────────────────┘ │
                                  └──[mSW1]──[mDIO1]──┐                   │
                                                      ├── LOAD+ ─[mACS3]─[Fout]─→ навантаження
Bat2 (свинець) ─[F2]─[mACS2]─── вузол B2 ─────────────────────────────────┘
                                  └──[mSW2]──[mDIO2]──┘

Живлення логіки:  B1 ─[VD1]─┐
                  B2 ─[VD2]─┴─ mDC5 (LM2596 → 5 В) ─ mMCU, реле K1/K2 (VCC і JD-VCC окремо);
                              3,3 В зі стабілізатора mMCU ─ mADC, датчики, mOLED

Керування:        mMCU GPIO ─→ ON ключів mSW1/mSW2 (3,3 В напряму; повзунок на модулі — стан без контролера)
                  mMCU GPIO ─[NPN]─→ IN1/IN2 реле K1/K2 (активний низький, транзистор тягне до землі)
```

Ключові рішення:

- **Заряд приходить у вузол B — після датчика струму, до ключа.** Тому датчик бачить і заряд, і розряд (один датчик на акумулятор — це і є лічильник), а заряджати можна відрізаний від навантаження акумулятор.
- **Реле заряду K1/K2 комутують без струму:** перед перемиканням прошивка вимикає DPS5015 і перевіряє нульовий струм. Робоча межа **10 А** задана реле та БЖ: 10 А × 28,8 В = 288 Вт; за ККД DPS ~93 % це близько 310 Вт на вході. Стару вимогу прошивки 12 А ще потрібно узгодити з паспортними 10 А реле; на цьому залізі 12 А не дозволені. У триконтактній ревізії mACS немає лінії FAULT, покладатися на неї як на захист не можна.
- **Ключі гілок — MOSFET-модулі Pololu #2815, не реле.** Без контактів, без обмоток, без правила «комутувати тільки без струму»; у вимкненому стані блокують зворотний струм. **Стан при мертвому контролері задає повзунок на самому модулі:** повзунок OFF — гілка під керуванням прошивки (пін ON від GPIO) і без неї від'єднана; повзунок ON — гілка живить навантаження завжди, прошивка її вимкнути не може, лише бачить (командує OFF, а струм іде → показує «примусово ввімкнено»). Стартове положення обох — OFF.
- **Логіка живиться від обох акумуляторів через діодне «АБО» з вузлів B1/B2**, тобто *після* датчиків: споживання логіки (~50–100 мА, це 1–2 А·год на добу!) чесно потрапляє в облік того акумулятора, що її живить. Контролер живий, поки підключений хоч один акумулятор, незалежно від стану ключів.
- **Супердіод у гілці заряду:** третій XL74610 між виходом DPS5015 і реле K1/K2 — щоб знеструмлений DPS не бачив напруги акумулятора. Півватта втрат — прийнятна ціна за те, щоб не залежати від поведінки конкретного екземпляра. Усі три XL74610 задіяні, резерву немає (на заміну — Шотткі TO-220 на радіаторі).
- **Реле K1/K2 керуються через NPN-транзистори**, по одному на канал: GPIO → 1 кОм → база, 10 кОм база–емітер, колектор на IN. Модуль хоче 5 В на вході — транзистор просто тягне його оптрон до землі, і 3,3 В GPIO вистачає з запасом. У ресеті ESP32 (GPIO високоімпедансні) база на землі → реле вимкнене. Жодних перетворювачів рівнів.
- **АЦП — зовнішній ADS1115, не вбудований у ESP32.** Лічильник А·год інтегрує 90 мВ/А довкола 1,65 В; йому потрібні лінійність, стабільний нуль і власне опорне джерело. АЦП ESP32 — 12 біт без опорного джерела, нелінійний, шумить ±5–10 LSB і ще більше при Wi-Fi (ADC2 з Wi-Fi недоступний узагалі): це ±50–90 мА шуму й дрейф нуля з нагрівом чипа. ADS1115 — дельта-сигма 16 біт з опорним джерелом і PGA: 1,4 мА на LSB. Серед популярних MCU вбудованого АЦП такого класу немає, тому «MCU з достатньою кількістю аналогових входів» задачу не вирішує. Деталі — components.md.
- **Без великого накопичувального буфера на шині** — навантаження приходить через свої DC-DC. Малий буфер C1 100 мкФ / 50 В + C2 100 нФ монтується навісно біля зовнішніх клем LOAD+/GND, окремої PCB не потребує. TVS D3 лишається DNP до вимірювання викидів і вибору захисту за реальною напругою обмеження.
- **Уставка напруги заряду — за напругою на вузлі B (mADC), а не за виходом DPS.** Прошивка підтягує U-SET так, щоб на акумуляторі було рівно 28,8 В; тоді падіння на mDIO3, реле й дротах не псує профіль.

## Модулі

Характеристики, розпіновки, розміри й джерела кожного — у [components.md](components.md); тут лише роль і ключ до рішення.

| Поз. | Роль | Модуль | Треба | Є | Примітка |
|---|---|---|---|---|---|
| mDPS | зарядний перетворювач | DPS5015, 0–50 В / 15 А, Modbus RTU по TTL-UART | 1 | 2 | **без дисплея** — керується по Modbus з UART силової плати, перевірено; другий екземпляр — резерв; порт, регістри й порядок команд — `docs/dps5015-modbus.md` |
| mDIO1, mDIO2 | ідеальні діоди гілок | XL74610 (LM74610), 1,5–36 В, 15 А без радіатора | 2 | 3 | при 5–7 А радіатор не потрібен |
| mDIO3 | розв'язка виходу DPS від акумулятора | третій XL74610 | 1 | (з тих 3) | резерву XL74610 не лишається — на заміну Шотткі TO-220 (є) |
| mSW1, mSW2 | ключі гілок | Pololu Big MOSFET Slide Switch HP #2815, 4,5–40 В, 16 А, 8,6 мОм | 2 | 2 | пін ON від GPIO 3,3 В напряму; повзунок = стан без контролера |
| mREL2 | вибір акумулятора на заряд K1/K2 | реле 2-кан. FL-3FF-S-Z, 10 А @ 30 В DC | 1 | 1 | тригер за низьким рівнем, входи через NPN; перемичку JD-VCC зняти, VCC і JD-VCC окремими проводами від mDC5; обмотка ≈ 71 мА (паспорт) |
| mACS1, mACS2 | струм Bat1, Bat2 (заряд і розряд) | ACS711EX ±15,5 А за початковою специфікацією; тільки VCC/GND/VOUT | 2 | 3 | підтвердити модель і 3,3 В живлення; без FAULT |
| mACS3 | струм навантаження | третій ACS711EX | 1 | (з тих 3) | не обов'язковий; альтернатива — ACHS-7122 (5 В, є 1 шт.) |
| mADC | два зовнішні модулі, аналог від B, I²C/живлення від A | ADS1115, I2C 0x48 і 0x49 | 2 | 1 | другий додати; J2 — гілки, J13 — навантаження |
| mMCU | керування на A | ESP32 DevKitC 38 пін | 1 | 2 | ADC ESP не використовується; UART2 Modbus, I2C до B/OLED, 1-Wire, Wi-Fi |
| mDC5 | 5 В для логіки | LM2596 (вхід ≤ 40 В) | 1 | 4 | найгірший випадок ≈ 0,5 А (2 обмотки × 71 мА + ESP32 з Wi-Fi + OLED) |
| mOLED | поточний стан на корпусі | OLED 0,96″ SSD1306 (два різновиди з протилежним порядком пінів) | 1 | 3 | |
| T1, T2 | температура акумуляторів | DS18B20 у гільзі | 2 | 2 | свинець: термокомпенсація заряду; LiFePO₄: заборона заряду нижче 0 °C |
| — | USB-TTL для перевірки Modbus на столі | FT232RL | 1 | 1 | лише для налагодження |

Резерв (є в наявності, у базову схему не входять) — перелік у components.md: ACS758 ±100 А, CD74HC4067, модуль SD і DS3231.

## Базові компоненти для плат ЛУТ

Чотири PCB: A ESP із двома роз'ємами спільної I²C та парою підтяжок; B лише дільники, RC і аналогові виходи; C розподіл 3,3 В; D розподіл 5 В. ADS1115 J2/J13 стоять окремо біля B: аналогові кабелі від B, живлення/I²C від A. C/D не містять нових стабілізаторів: джерела — DevKitC і зовнішній LM2596. Кабелі та монтаж — [hardware/README.md](../hardware/README.md). Силові шини й C1/C2 зовнішні.

Номінали й варіанти — у [components.md](components.md#базові-компоненти-для-плат-лут); тут лише принцип: кілька популярних номіналів на кожну позицію, підійде будь-який із ряду.

## Вимірювання

| Сигнал | Звідки | Куди | Шкала |
|---|---|---|---|
| I_B1, I_B2 | mACS1/mACS2 · VIOUT (центр 1,65 В, 90 мВ/А) | ADS1115 A0, A1, PGA ±4,096 В | 125 мкВ на LSB = **1,4 мА**; ±15,5 А → 0,25…3,05 В без обрізу |
| U_B1, U_B2 | вузли B1/B2 через дільник 1 : 11 | ADS1115 A2, A3, PGA ±4,096 В | ≈ **1,4 мВ** напруги гілки на LSB |
| U_LOAD | шина через дільник 100k/4,7k | ADS1115 0x49 A1 | контроль, не облік |
| I_LOAD | mACS3 · VOUT через RC | ADS1115 0x49 A0 | контроль; струм навантаження нижче центру (1,65 → 0,75 В при 10 А) |
| U_chg, I_chg, U_in | DPS5015 по Modbus | — | перехресна перевірка mACS під час заряду; U_in — ознака «БЖ зник» |
| T_B1, T_B2 | DS18B20 | 1-Wire | термокомпенсація свинцю −3 мВ/°C на банку; заборона заряду LiFePO₄ < 0 °C |

Орієнтація датчиків: дріт від запобіжника — в IP−, вузол B — з IP+. Тоді розряд читається нижче центру, заряд — вище.

**Шум і нуль датчиків.** ACS711EX має смугу 100 кГц і без фільтра «танцює» біля нуля. Розділяємо дві речі: випадковий **шум** при інтегруванні сам себе гасить (плюси й мінуси взаємно знищуються) і псує лише картинку, а систематичний **зсув нуля** прямо краде А·год — 30 мА зсуву це 0,7 А·год на добу. Тому: RC 1 кОм + 1 мкФ на кожному VIOUT (зріз ≈ 160 Гц), усереднення за 0,5–1 с **для показу**, повне інтегрування без відкидання малих значень, автонуль (нижче). **Мертвої зони у підрахунку немає взагалі**: логіка їсть 50–100 мА цілодобово з вузла B, і поріг «менше 100 мА = нуль» стер би саме її; на екрані поріг 20 мА допустимий. Якщо після фільтра σ за 1 с усе одно > 20 мА або зсув пливе більш ніж на 30 мА за добу — план Б: шунт 5 мОм у мінусовому проводі гілки на диференціальний вхід ADS1115 при PGA ±0,256 В (7,8 мкВ на LSB = 1,6 мА, зовсім інша фізика). Деталі й критерії — крок 0.1 плану.

## Підрахунок А·год на пристрої

- **Метод:** інтегрування струму за часом окремо для заряду й розряду: `Ah_in`, `Ah_out`, `Wh_in`, `Wh_out` — наростаючим підсумком і за поточний цикл; лічильник циклів; момент і причина останнього «повного». Це єдина «історія», що живе на пристрої: без неї не порахувати SoC після перезавантаження.
- **Вибірка:** ADS1115 у безперервному режимі, 4 канали по колу при 250–475 SPS → кожен струм ≈ 60–120 разів на секунду; інтегрування трапеціями.
- **Синхронізація SoC:** «100 %» — у момент завершення заряду (CV і струм хвоста: LiFePO₄ ≤ 2,5 А, тобто 0,05 C; свинець — перехід у float при ≤ 1,3 А); далі SoC = 100 % − Ah_out/ємність (50 / 65 А·год як параметри).
- **Нуль датчиків:** (а) ручне калібрування зі знятим запобіжником; (б) **автонуль**: коли ключ mSW гілки вимкнений, заряд не на ній і логіку живить *інший* (вищий за напругою) акумулятор — струм через датчик гарантовано нульовий, прошивка підправляє зсув. Дрейф зсуву Холла (десятки мА) за добу давав би ~1 А·год похибки.
- **Масштаб:** калібрується проти телеметрії DPS5015 під час заряду (постійний струм) і проти мультиметра/DSN-VC288. Для ACS711EX від 3,3 В: **90 мВ/А**, нуль **VCC/2 = 1,65 В** (не переплутати з числами ACS712 від 5 В — 185 мВ/А і 2,5 В).
- **Збереження:** лічильники в NVS кожні 10 хв і на кожній події (старт/стоп заряду, зміна ключів, FAULT).
- **Показ на пристрої:** mOLED — стан ключів і заряду, U/I обох гілок, SoC, лічильники циклу, Wi-Fi/сервіс; кнопка гортає екрани.

## Телеметрія і сервіс

Пристрій — джерело даних, сервіс — пам'ять і аналітика.

- **Пошук пристрою:** ESP32 анонсує себе через **mDNS** (`batman.local`, сервіс `_batman._tcp`) і відповідає на UDP-broadcast «хто тут» (резерв для мереж, де mDNS ріжеться); користувач може вказати IP вручну.
- **Підключення:** сервіс викликає на пристрої `POST /sink` з адресою свого приймача та інтервалом — пристрій зберігає це в NVS і починає слати.
- **Потік:** пристрій **сам** відправляє JSON по HTTP POST (типово раз на 2 с; параметр 1–60 с): U/I обох гілок, U/I навантаження, T1/T2, телеметрія DPS (U/I/режим/U_in), стан ключів і реле заряду, стан стейт-машини, лічильники Ah/Wh, SoC, FAULT, uptime, RSSI. Події (зміна стану, старт/стоп заряду, FAULT, помилки Modbus) — окремим типом повідомлення негайно. Якщо сервіс недоступний — кільцевий буфер в оперативній пам'яті (~10 хв), далі дані втрачаються: історія — справа сервісу, а не пристрою.
- **API пристрою** (для сервісу й для налагодження з браузера): `GET /status`, `GET /telemetry`, `POST /sink`, `GET|POST /config` (пороги, профілі, калібрування, політика черговості), `POST /control` (старт/стоп заряду, вибір акумулятора, ключі), `GET /events`. Мінімальна вбудована сторінка — лише щоб побачити стан і задати Wi-Fi/сервіс без сервісу.
- **Сервіс:** кросплатформений (Windows → Raspberry Pi 4). Пропозиція: **Python 3 + FastAPI + SQLite**, один процес, запуск як служба Windows / systemd, вебінтерфейс на вбудованих сторінках із графіками. Робить: пошук пристроїв, реєстрацію, приймання телеметрії, зберігання сирих зразків, агрегати (година/доба/цикл: А·год і Вт·год у/з кожного акумулятора, к-сть циклів, ефективність Ah_out/Ah_in, час у станах), графіки, експорт CSV, пересилання команд і налаштувань на пристрій, сповіщення про FAULT і втрату зв'язку. Час у записах — від сервісу; пристрою власний годинник не потрібен (NTP по Wi-Fi — лише для журналу подій на OLED).

## Струми й межі

| Ділянка | Межа | Чим обмежена |
|---|---|---|
| Заряд | не більше 10 А на поточному залізі | контакти K1/K2 на 10 А; стара стеля 12 А у вимогах прошивки є незакритою суперечністю, не дозволом. Датчики не забезпечують апаратної відсічки |
| Розряд гілки | до 10 А (реально 4–7 А, колись 9) | mSW #2815 16 А (0,7 Вт при 9 А); XL74610 15 А без радіатора; запобіжник 15 А |
| Запобіжники гілок | 15 А | найпростіший захист від КЗ на шині |
| Логіка | ≈ 0,5 А найгірший випадок з mDC5 | ESP32 з Wi-Fi 0,25 А (пік 0,4) + 2 обмотки по 71 мА + OLED і датчики ~50 мА |
| БЖ | 33 В / 10 А = 330 Вт | заряд 288 Вт + втрати DPS ≈ 310 Вт: БЖ завантажений на 94 % у кінці заряду; навантаження від БЖ не живиться — тільки через акумулятори |

## Припущення (працюємо так, поки не спростовано)

1. Акумулятори, БЖ 33 В і DC-DC споживачів — **поза корпусом**; у корпусі — ядро (силова плата mDPS без дисплея, реле, діоди, датчики, логіка, клеми, запобіжники).
2. Профілі: LiFePO₄ — CC 10 А → CV 28,8 В → стоп при хвості ≤ 2,5 А, без float; свинець — bulk 10 А → absorption 28,8 В → float 27,4 В з термокомпенсацією. Ключі розряду керуються вручну (з сервісу/сторінки) й порогами (LiFePO₄ 24,0 В, свинець 23,0 В) — розрядна логіка мінімальна, як і задумано.
3. Стан ключів при мертвому контролері — за повзунками mSW1/mSW2; стартове положення обох OFF (усе вимкнено), поки стенд не доведе надійність. Безпечний стан керування: у ресеті GPIO високоімпедансні — ON-піни ключів у нулі, бази NPN на землі, усе вимкнене.
4. Плати — однобічний ЛУТ за перевіреними на практиці правилами: доріжки сигнальні **≥ 0,7 мм**, силові ≥ 3 мм із пропайкою, зазор **≥ 0,5 мм**, отвір = вивід + 0,2–0,3 мм і пад = отвір + 1,2 мм **під конкретний компонент** (у резистора ніжка тонка, у силового діода — товста), перемички дротом — норма. Повна таблиця падів — у плані, крок 2.2.
5. Уся логіка з'єднується **дюпонами**: на платах гребінки 2,54 прямі або кутові (є обидва типи), **на дроті — тільки прямі корпуси**. Корпус це враховує: ≥ 30 мм над прямою гребінкою, ≥ 25 мм убік перед кутовою.
6. Сервіс — Python/FastAPI/SQLite; якщо на етапі 6 захочеться один бінарник без залежностей — переписати на Go, протокол пристрою від цього не зміниться.
7. Охолодження — штатним вентилятором DPS5015; наявний 50 × 50 (5 В) лише як передбачена в корпусі альтернатива, рішення після теплового тесту.

## Відкриті питання

1. **Наскільки шумлять ACS711EX біля нуля** — вирішить, чи вистачить RC + усереднення + автонуль. Варіант із шунтами потребує окремої переробки входів і перевірки допустимої синфазної напруги; 0x49 вже використовується для навантаження, його A2/A3 зараз заземлені. Критерії — крок 0.1 плану.
2. **Чи потрібен вентилятор 50 × 50** замість штатного вентилятора DPS5015 — за результатом теплового тесту (крок 7.3); місце в корпусі під нього закладено одразу.

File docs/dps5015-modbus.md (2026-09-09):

# DPS5015 — керування по Modbus RTU

Усе, що прошивці треба знати про DPS5015: порт, налаштування, регістри, послідовності команд, поведінка при помилках. Дані з трьох джерел: власна практика на цих платах (✔), офіційний протокол RuiDeng «DPS5015 CNC Communication Protocol V1.2» у переказі публічних драйверів (🌐), мануал joy-it (🌐).

## Порт

| | Значення | Джерело |
|---|---|---|
| Де | TTL-UART на **силовій платі**; плата дисплея не потрібна — DPS працює і повністю керується без неї | ✔ |
| Роз'єм | 4 контакти, шовкографія типу `V R T G` (у деяких партіях останній підписаний `B`): **V** = 3,3 В з DPS, **R** = RXI — вхід DPS (сюди TX ESP32), **T** = TXO — вихід DPS (сюди RX ESP32), **G** = GND | ✔ |
| Рівні | 3,3 В TTL — до ESP32 напряму, без перетворювачів | ✔ |
| Живлення | пін **V не з'єднувати**: логіка живиться від mDC5, спільна тільки земля | — |
| Параметри | **9600 8N1**, Modbus-адреса **1** (обидва можна змінити в меню DPS, утримуючи V/▲ при вмиканні — нам не треба) | ✔ |
| Дріт | три жили (GND, TX, RX) ≤ 30 см, окремо від силових | — |

На ESP32: **UART2**, TX GPIO 17 → R (RXI), RX GPIO 16 ← T (TXO). Розкладка пінів — connections.md.

## Кадр

Стандартний Modbus RTU: `[адреса][функція][дані…][CRC16 LE]`, пауза між кадрами ≥ 3,5 символи (≈ 4 мс на 9600). Функції:

| Код | Що | Використовуємо |
|---|---|---|
| 0x03 | читання holding-регістрів | так, блоками |
| 0x06 | запис одного регістра | так |
| 0x10 | запис кількох регістрів | так, для U-SET + I-SET одним кадром |
| 0x04 | читання input-регістрів | ні; старий драйвер читав ним 0x02–0x05 і DPS відповідав — але канонічний 0x03 |

Усі регістри 16-бітні. Напруги і струми — **ціле × 100** (2880 = 28,80 В; 1000 = 10,00 А). Потужність — теж × 100 (для DPS5015 підтверджено практикою: `P / 100`).

## Регістри

Основний блок — читати одним кадром 0x03 з адреси 0x0000 на 13 регістрів.

| Адреса | Ім'я | R/W | Масштаб | Значення | Джерело |
|---|---|---|---|---|---|
| 0x0000 | U-SET | R/W | × 100 | уставка напруги | ✔ |
| 0x0001 | I-SET | R/W | × 100 | уставка струму | ✔ |
| 0x0002 | UOUT | R | × 100 | напруга на виході | ✔ |
| 0x0003 | IOUT | R | × 100 | струм на виході | ✔ |
| 0x0004 | POWER | R | × 100 | потужність на виході | ✔ |
| 0x0005 | UIN | R | × 100 | напруга на вході (БЖ) | ✔ |
| 0x0006 | LOCK | R/W | — | блокування кнопок: 0 ні, 1 так (без дисплея не має значення) | 🌐 |
| 0x0007 | PROTECT | R | — | стан захисту: **0** норма, **1** OVP, **2** OCP, **3** OPP | 🌐 |
| 0x0008 | CV/CC | R | — | **0** CV, **1** CC | ✔ |
| 0x0009 | ONOFF | R/W | — | вихід: **0** вимкнено, **1** увімкнено | ✔ |
| 0x000A | B-LED | R/W | — | яскравість підсвітки 0–5 (без дисплея — байдуже) | 🌐 |
| 0x000B | MODEL | R | — | 5015 | 🌐 |
| 0x000C | VERSION | R | — | версія прошивки | 🌐 |
| 0x0023 | EXTRACT-M | R/W | — | викликати групу пресетів 0–9 | 🌐, не використовуємо |

Групи пресетів M0–M9 — по 8 регістрів від `0x0050 + n × 0x0010`: U-SET, I-SET, S-OVP, S-OCP, S-OPP, B-LED, M-PRE, S-INI. **M0 — те, з чим DPS стартує після подачі живлення.** Це важливо: якщо в M0 лежить ONOFF = 1 (S-INI), DPS після зникнення й повернення БЖ увімкне вихід сам, до того як прошивка щось скаже. Тому:

| Адреса | Ім'я | Що записати один раз (команда `dps_m0` з `/control`, поза зарядом) |
|---|---|---|
| 0x0050 | M0 U-SET | 2000 (20,00 В — нижче будь-якого акумулятора, безпечно) |
| 0x0051 | M0 I-SET | 100 (1,00 А) |
| 0x0052 | M0 S-OVP | 3100 (31,00 В) — апаратна стеля, незалежна від прошивки ESP32 |
| 0x0053 | M0 S-OCP | 1250 (12,50 А) — те саме для струму |
| 0x0054 | M0 S-OPP | 40000? — перевірити масштаб на своєму екземплярі (× 10 або × 100); мета ≈ 400 Вт |
| 0x0057 | M0 S-INI | **0** — після подачі живлення вихід вимкнений |

Ці пороги OVP/OCP спрацьовують у самому DPS і вмикають PROTECT ≠ 0 — другий рубіж після прошивки.

## Що прошивка робить, і в якому порядку

**Опитування.** Раз на 500 мс — один кадр 0x03 від 0x0000 на 10 регістрів (U-SET … ONOFF). З нього: UOUT, IOUT для перехресної перевірки датчиків; UIN — ознака живого БЖ; CV/CC — фаза заряду; PROTECT — аварія; ONOFF і уставки — звірка «чи DPS у тому стані, який ми думаємо».

**Старт заряду гілки X:**
1. `ONOFF ← 0`; чекати, поки `IOUT = 0` і `UOUT < 1 В` (до 2 с), інакше → FAULT_DPS.
2. Замкнути реле KX (інше — розімкнене). Пауза 50 мс.
3. Прочитати U_BX з ADS1115; `U-SET ← min(U_BX + 0,5 В, стеля профілю)` — щоб при вмиканні не було стрибка; `I-SET ← струм профілю` (одним кадром 0x10 з 0x0000 на 2 регістри).
4. `ONOFF ← 1`.
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

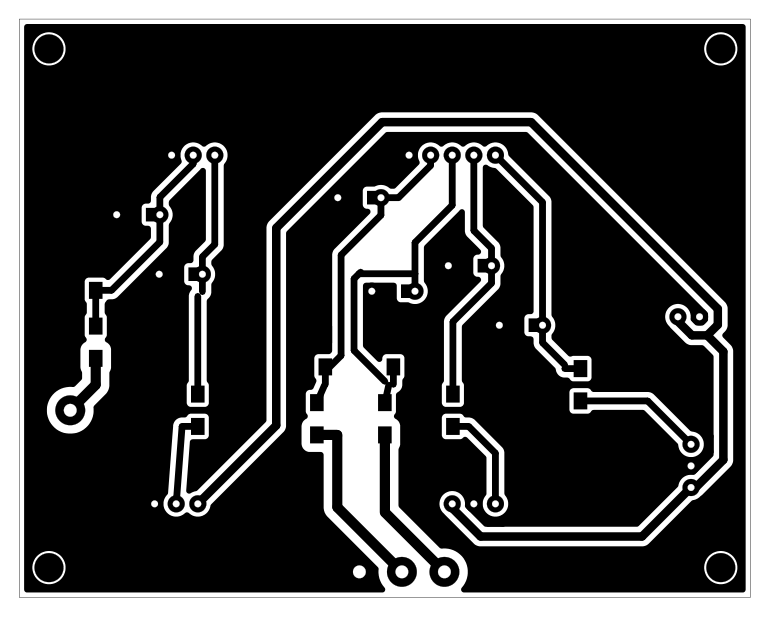
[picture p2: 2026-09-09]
hardware/batman/reports/refinement/staged/reports/previews/B-copper-mirrored.png

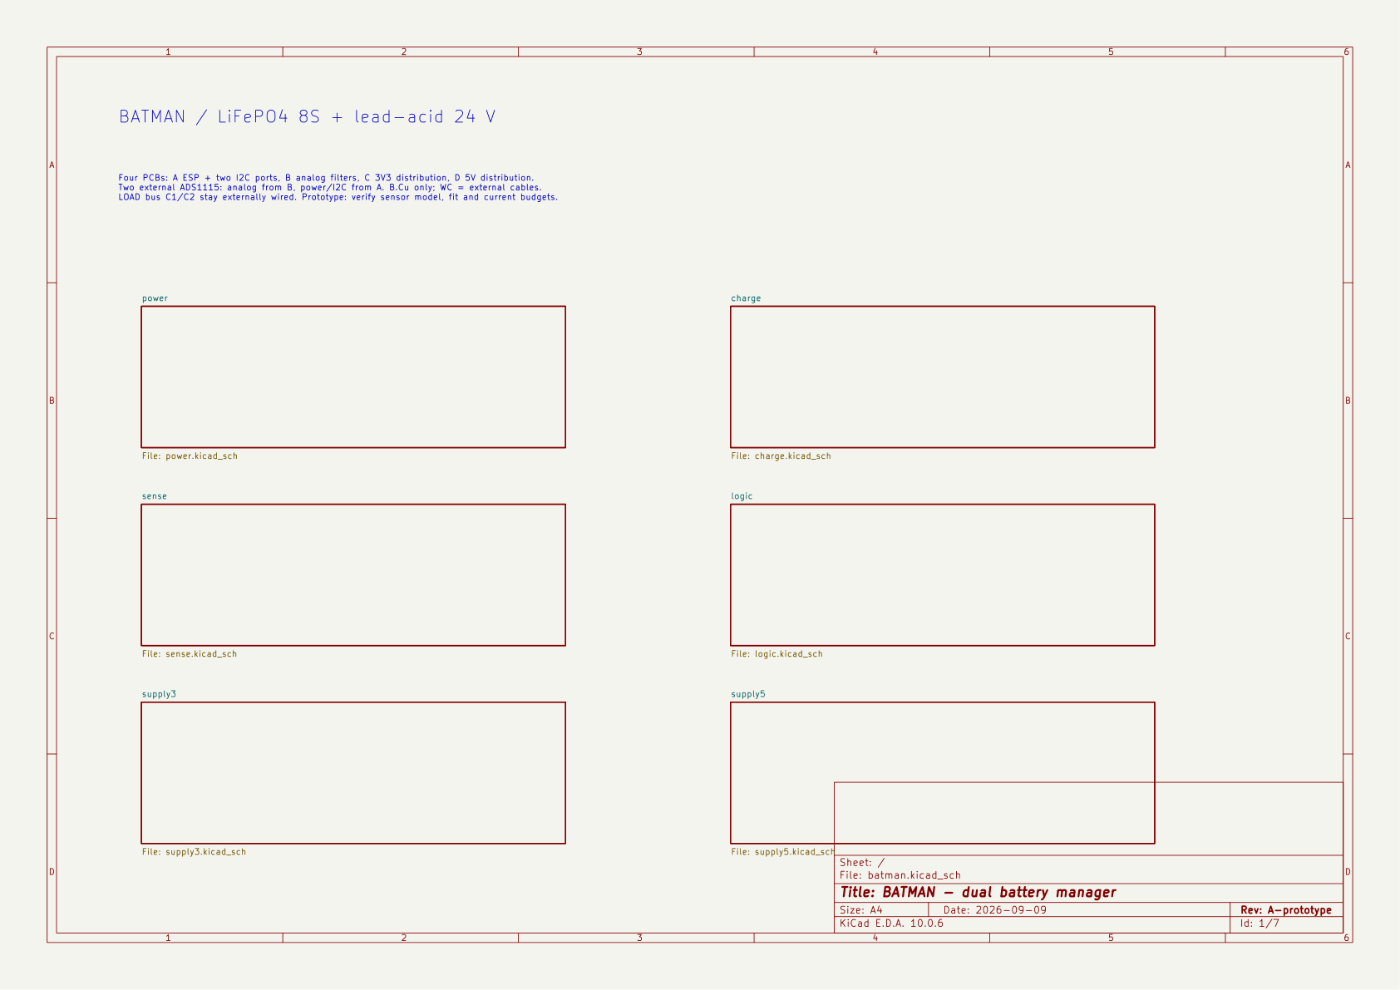
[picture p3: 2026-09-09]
hardware/batman/reports/gpio33/before-publish-20260909-184347/reports/previews/schematic-1.png

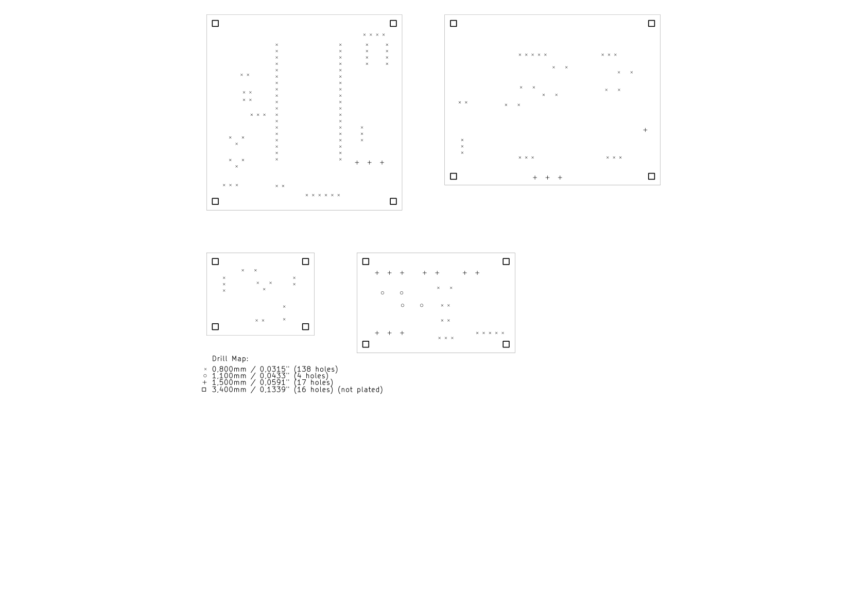
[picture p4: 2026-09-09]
hardware/batman/reports/gpio33/before-publish-20260909-184347/reports/previews/drill-map.png

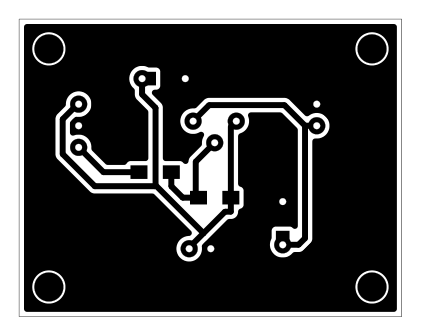
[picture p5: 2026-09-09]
hardware/batman/reports/refinement/before-publish-20260909-170518/reports/previews/C-copper-top-view.png

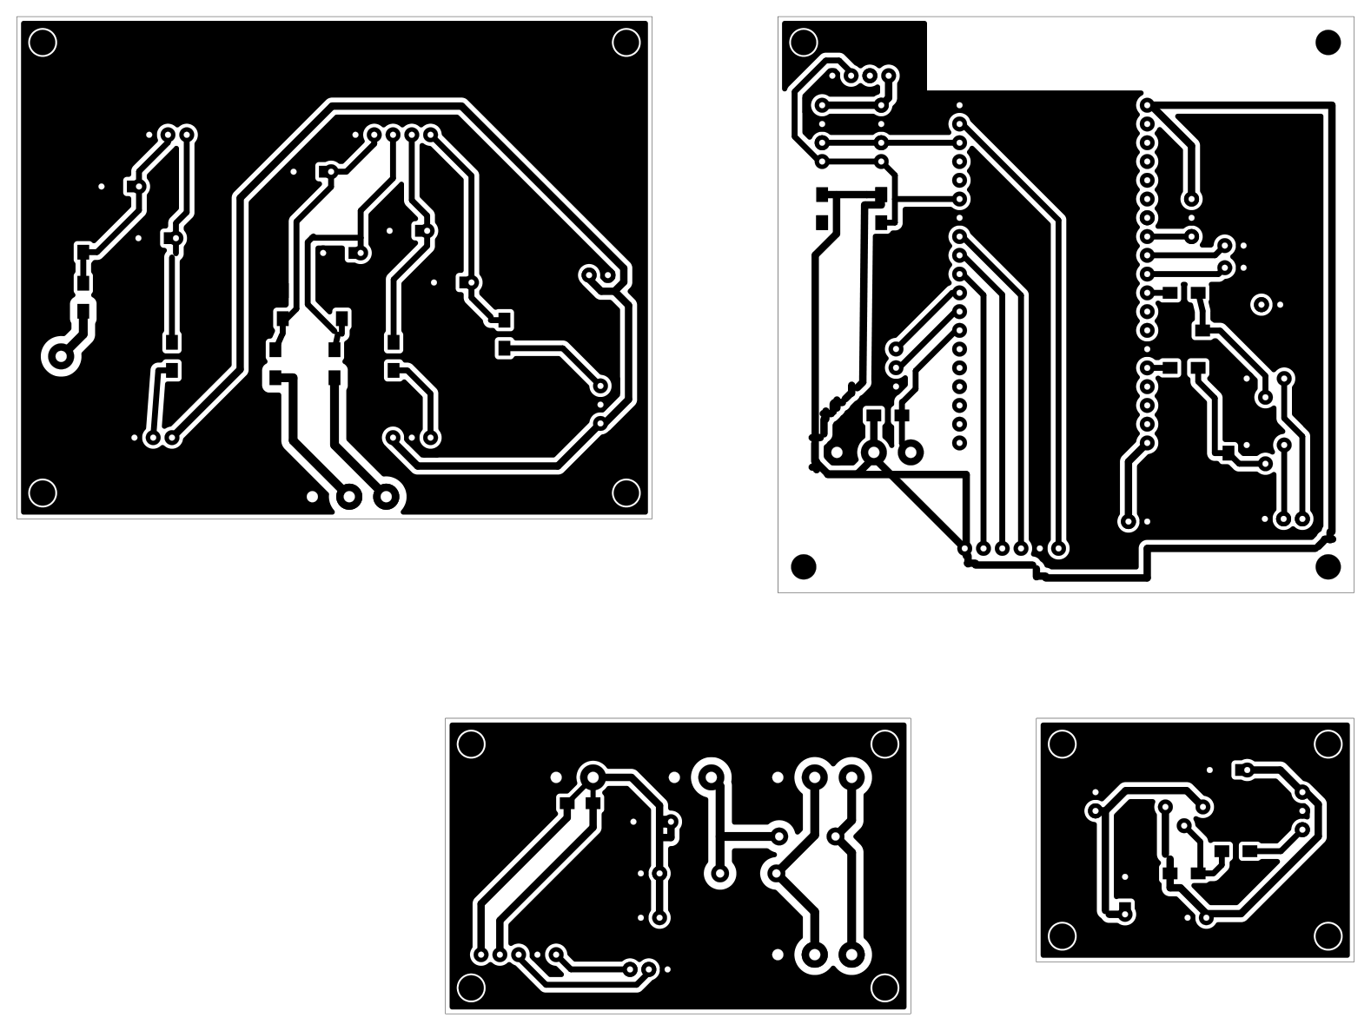
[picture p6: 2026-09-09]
hardware/batman/reports/clean-routing/before-publish-20260909-212552/reports/previews/copper-mirrored.png

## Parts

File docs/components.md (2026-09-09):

# Компоненти

Усе, з чого складається пристрій: готові модулі та базові компоненти. Файл самодостатній — зовнішні джерела лише публічні (магазин, виробник, даташит). Кожен розмір несе позначку походження:

| Позначка | Звідки | Що з ним робити |
|---|---|---|
| **✔** | штангенциркуль | остаточне, ним і креслимо |
| **🌐** | виробник, магазин або даташит (посилання в рядку) | креслити можна; перед друком деталі начисто перевірити штангенциркулем |
| **≈** | оцінка за фото чи аналогом | креслити із запасом ≥ 2 мм на сторону; у деталі, яку друкуємо начисто, лишатися не може |

## Зведена таблиця

| Поз. | Модуль | Призначення | Треба | Є | Розміри, мм | Джерело розміру |
|---|---|---|---|---|---|---|
| mDPS | DPS5015 (RuiDeng), лише силова плата — дисплей не ставимо | керований заряд: із 33 В БЖ робить CC/CV для акумулятора, уставки задає прошивка по Modbus | 1 | 3 | 91 × 67 × 40 | ✔ (joy-it дає те саме; інші продавці 93 × 71 — не брати) |
| mDIO1–3 | XL74610 «ідеальний діод» | замість силового діода майже без падіння: розв'язка гілок між собою (mDIO1, mDIO2) і виходу DPS (mDIO3) | 3 | 3 | 17 × 10 | ✔ |
| mSW1–2 | Pololu Big MOSFET Slide Switch HP #2815 | силові ключі гілок: відрізати акумулятор від навантаження без контактів; повзунок задає стан без контролера, пін ON — керування з ESP32 | 2 | 2 | 20,3 × 25,4 × 4 | 🌐 Pololu |
| mREL2 | реле 2-кан. FL-3FF-S-Z | вибір, яку гілку ставимо на заряд від DPS (K1, K2) | 1 | 1 | 50 × 40 × 19 | ✔ |
| mACS1–3 | Pololu ACS711EX ±15,5 А | датчики струму на ефекті Холла (розв'язані від силового кола): струм гілок для лічильника А·год і струм навантаження | 3 | 3 | 17,8 × 20,3 | 🌐 Pololu |
| mADC | ADS1115 | два зовнішні 16-бітні I2C-АЦП: аналог із B, живлення/I²C із A | 2 | 1 | ~28 × 17 кожен | 🌐 за фото магазину |
| mMCU | ESP32 DevKitC 38 пін (USB-C, CH340) | мозок пристрою: логіка заряду/розряду, лічильник ємності, Wi-Fi-телеметрія на сервіс | 1 | 2 | 55 × 28, з гребінками 13 заввишки | ✔ |
| mDC5 | LM2596 (HW-411) | живлення логіки: з 27–29 В шини робить 5 В для ESP32 і обмоток реле K1/K2 | 1 | 4 | 44 × 22 × 15 | 🌐 arduino.ua |
| mOLED | OLED 0,96″ SSD1306 I2C | локальний екран стану (напруга, струм, ємність) — щоб не лізти в телефон | 1 | 3 | плата 28 × 28, активна 24,8 × 16,8 | 🌐 arduino.ua |
| T1, T2 | DS18B20 у гільзі | температура акумуляторів: T1 на LiFePO₄ (заборона заряду < 0 °C), T2 на свинці (термокомпенсація уставки) | 2 | 2 | гільза Ø6 × 50, кабель ~1 м | 🌐 arduino.ua |
| — | FT232RL USB-UART (налагодження) | ноутбук ↔ TTL-UART: перевірка Modbus-обміну з DPS5015 і друга консоль ESP32 | 1 | 1 | ~36 × 18 | 🌐 за фото |
| — | DSN-VC288 вольт-амперметр (еталон при калібруванні) | зразковий прилад, за яким виставляємо масштаб датчиків струму й дільників напруги | 1 | 1 | корпус 48 × 29 × 21 | 🌐 arduino.ua |
| — | вентилятор 50 × 50, 5 В (опція) | примусовий обдув радіатора DPS5015, якщо тепловий тест покаже перегрів | 0–1 | 1 | 50 × 50 × (10…15), отвори 40 × 40 | 🌐 стандарт |

## mDPS — DPS5015

Регульований понижувальний перетворювач RuiDeng з цифровим керуванням. Продається як два вузли — силова плата (вентилятор, тороїд, клеми IN/OUT) і плата дисплея на шлейфі. **У пристрої стоїть лише силова плата**: вона працює й повністю керується по Modbus через свій TTL-UART без дисплея — перевірено на цих платах. Дисплей не потрібен: стан показують OLED і сервіс.

| Параметр | Значення | Джерело |
|---|---|---|
| Вхід | 6–60 В DC за даташитом joy-it; **тримаємось ≤ 55 В** (так само пише магазин; перевищення миттєво спалює ключі) | 🌐 |
| Вихід | 0–50 В, 0–15 А, до 750 Вт; режими CC/CV | 🌐 |
| Роздільність | 0,01 В / 0,01 А | 🌐 |
| Пульсації | 100 мВ п-п | 🌐 |
| Захисти | OVP, OCP, OPP, OTP — пороги задаються в меню (перевірити на своєму екземплярі) | 🌐 загальновідомо для серії DPS |
| Вентилятор | штатний, малий, на силовій платі; вмикається автоматично за температурою | 🌐 |
| Зв'язок | Modbus RTU, TTL 3,3 В, **9600 8N1, адреса 1**, порт UART на силовій платі — перевірено на цих платах без дисплея; регістри й порядок команд — `dps5015-modbus.md` | ✔ |
| Висота силової плати | **40 мм** (з вентилятором і радіатором) | ✔ |
| Довжина × ширина силової плати | 91 × 67; отвори з міжцентровими 86 × 64 | ✔ (збігається з [joy-it JT-DPS5015](https://www.joy-it.net/en/products/JT-DPS5015)) |
| Кількість | треба 1, є 3 (дві — резерв; усі три відповідають по Modbus) | |

Перше вмикання — через запобіжник і на мінімальній вхідній напрузі; вихід здатний на 15 А, коротке замикання дає іскру й оплавлений провід.

## mDIO1–mDIO3 — XL74610, «ідеальний діод»

Двовивідний модуль-замінник силового діода: контролер **TI LM74610-Q1** керує N-MOSFET (AGM403A1), відкриваючи його при прямому зміщенні й закриваючи при зворотному. Вмикається **послідовно, як звичайний діод**: площадка-«анод», площадка-«катод», напрямок — символом діода на звороті (маркування XL74610L V1.0). Живлення драйвера — з накопичувального конденсатора, тому статичне споживання ≈ 0.

| Параметр | Значення |
|---|---|
| Робоча напруга | 1,5–36 В |
| Струм без охолодження | ≤ 15 А (12 В, 25 °C, перевірено магазином 30 хв) |
| Струм з радіатором і обдувом | ≤ 30 А |
| Падіння | ≈ 0,3 В на холостому ходу, менше під струмом |
| Статичний струм | ~0 мА |
| Розміри | **17 × 10 мм** ✔ |
| Підключення | на кожному кінці велика мідна площадка з отворами (крок 2,54); **дроти напаюємо прямо на площадки** — надійніше за виводи в отворах |
| Монтаж | **не на плату** — модуль кріпиться до корпусу у власному тримачі, дроти йдуть до зовнішнього клемного вузла LOAD+/GND і до клемників ключів |

⚠ Що важливо саме для нас:
- **Не безрозривний:** ≈ 2 % часу (близько 2 с зі 100) падіння підіймається до 0,7 В — це моменти підзарядки конденсатора драйвера. Для гілок розряду й гілки заряду це прийнятно (уставку напруги заряду прошивка все одно веде за вузлом B, а не за виходом DPS); для ДБЖ і схем, чутливих до провалів, модуль не годиться.
- **Немає спільної землі** → на модулі немає ані захисного діода, ані вихідного конденсатора. Буфер LOAD C1 100 мкФ / 50 В і C2 100 нФ ставимо навісно біля зовнішніх клем, без окремої PCB. D3 лишається DNP до вимірювання викидів і вибору захисту за реальною напругою обмеження.
- Полярність не переплутати — пропускає лише в один бік.

Кількість: треба 3 (mDIO1, mDIO2 — гілки; mDIO3 — розв'язка виходу DPS), є 3 — резерву немає; на заміну є Шотткі TO-220.

Джерела: [arduino.ua NPN432](https://arduino.ua/prod7266-modyl-idealnii-diod-30a-xl74610-1sht) · [TI LM74610-Q1](https://www.ti.com/product/LM74610-Q1) · [даташит LM74610-Q1](https://www.ti.com/lit/ds/symlink/lm74610-q1.pdf)

## mSW1, mSW2 — Pololu Big MOSFET Slide Switch HP (#2815)

Силовий ключ гілки на P-канальних MOSFET з захистом від переполюсування: повзунок не комутує струм, а керує затворами, тому крихітний перемикач тримає одиниці–десятки ампер. Купувався саме під це. Замінює реле в ролі SW1/SW2: без контактів, без обмоток, без «комутувати тільки без струму», і сам блокує зворотний струм у вимкненому стані.

| Параметр | Значення |
|---|---|
| Напруга | 4,5–40 В (абсолютний максимум 40 В) |
| Струм | паспортно 16 А (Pololu наводить 6 А як «плата не тепліша за 55 °C» і 16 А при 150 °C); короткочасно до 90 А |
| Опір каналу | 8,6 мОм при 10 В на затворі (40 мОм при 4,5 В) → 0,2 Вт при 5 А, 0,4 Вт при 7 А, 0,7 Вт при 9 А — тепла нема про що говорити |
| Власне споживання | ~65 мкА на вольт (світлодіод): ≈ 1,8 мА при 28 В — іде через датчик гілки, у підрахунок потрапляє чесно |
| Зворотний струм у OFF | блокується |
| Розміри | 20,3 × 25,4 × 4 мм (0,8″ × 1,0″ × 0,16″), 2,7 г |
| У комплекті | 2 клемники 5 мм на 2 контакти, гребінки |

Розпіновка: `VIN` / `GND` (вхід, великий отвір + два по 2,54), `VOUT` / `GND` (вихід), `ON` — керуючий вхід, `CTRL` — виводи самого повзунка.

**Як взаємодіють повзунок і пін ON** (за Pololu): повзунок у положенні **ON** — ключ увімкнений завжди, контролер його не вимкне. Повзунок у положенні **OFF** — стан задає пін ON: понад ≈ 1 В — увімкнено, низький або нікуди не підключений — вимкнено (максимум на ON — 30 В, незалежно від VIN). Тобто GPIO 3,3 В ESP32 керує **напряму**, без транзистора, а при мертвому контролері (GPIO високоімпедансні) гілка з повзунком OFF від'єднана.

Наслідок для нас: повзунок і є «стан при мертвому контролері». OFF — гілка під керуванням прошивки й без неї вимкнена; ON — гілка живить навантаження завжди, прошивка лише бачить це (командує OFF, а гілка віддає струм → повзунок примусово ON) і показує. Стартове положення обох — OFF.

Кількість: треба 2, є 2. Наявні Pololu Mini Pushbutton #2808 сюди **не годяться**: це LV-версія, 2,2–20 В, у нас на гілці до 29,8 В.

Джерело: [Pololu #2815](https://www.pololu.com/product/2815)

## mREL2 — реле 2-канальне, FL-3FF-S-Z

Два реле FL-3FF-S-Z (аналог SONGLE SRD-05VDC-SL-C) з оптронною розв'язкою входів і світлодіодами. У пристрої: K1, K2 — вибір, яку гілку ставимо на заряд від DPS5015; комутують лише без струму (вихід DPS перед тим вимкнений).

| Параметр | Значення |
|---|---|
| Контакти | 10 А @ 250 В AC; **10 А @ 30 В DC**; перекидні COM / NO / NC на клемниках |
| Керування | **тригер за низьким рівнем**, вхід 5 В TTL |
| Живлення | 5 В; перемичка VCC ↔ JD-VCC |
| Струм обмотки | **≈ 71 мА** за паспортом реле (котушка ~70 Ом). Магазин пише «15–20 мА» — беремо гірше, паспорт |
| Розміри | 50 × 40 мм, висота з реле 19 мм ✔ |

Гребінка `VCC GND IN1 IN2`, окремо `JD-VCC`; клемники COM / NO / NC.

⚠ **Контакти працюють на паспортній межі.** Робочий струм заряду 10 А дорівнює паспортним 10 А @ 30 В DC; при опорі контакту ~30 мОм це ~3 Вт у самому контакті. Комутація завжди без струму (вихід DPS вимкнений), тож дуги немає, і залишається тільки нагрів. Що з цим робимо: на тепловому тесті (крок 7.3) міряємо температуру корпусу реле й **падіння на замкненому контакті під 10 А** — норма до ~100 мВ; якщо падіння росте від циклу до циклу, контакти деградують і реле міняється. Жорстка стеля уставки заряду в прошивці — 12 А, і піднімати її вище без заміни реле не можна.

**Керування з 3,3 В — через звичайний NPN** (по одному на канал, на платі A): GPIO → 1 кОм → база; 10 кОм база–емітер; емітер на GND; колектор на IN. Вхід модуля — світлодіод оптрона з резистором від 5 В, транзистор тягне його до землі: GPIO HIGH = реле ON. У ресеті ESP32 GPIO високоімпедансні, 10 кОм тримає базу на землі → транзистор закритий → IN підтягнутий самим модулем до 5 В → реле OFF. Підійде будь-який малопотужний NPN (BC547, 2N2222, S8050, 2N3904): треба стягнути ~5 мА.

Перемичку JD-VCC зняти; VCC і JD-VCC — окремими проводами зіркою від mDC5, GND спільний: кидки обмоток не гуляють логічною шиною.

Джерело: [arduino.ua AOC110](https://arduino.ua/prod201-2-h-kanalnii-modyl-rele-5v-10a-s-optorazvyazkoi)

## mACS1–mACS3 — Pololu ACS711EX ±15,5 А (#2452)

Вихідна специфікація вказує Pololu з датчиком Холла **Allegro ACS711KEXLT-15AB**. Для поточної ревізії задано лише три низьковольтні контакти: живлення, GND, VOUT. **FAULT не підключений і не захищає силове коло.** Точну модель триконтактного екземпляра треба підтвердити: наведені нижче 3,3 В та 90 мВ/А залишаються припущенням за вихідною специфікацією, не результатом обміру.

| Параметр | Значення |
|---|---|
| Живлення | 3–5,5 В; **використовуємо 3,3 В** |
| Вихід VIOUT | аналоговий, у спокої VCC/2 = **1,65 В** при 3,3 В |
| Чутливість | пропорційна VCC: **90 мВ/А при 3,3 В** (136 мВ/А при 5 В) |
| Діапазон | ±15,5 А → 0,25…3,05 В при 3,3 В, без обрізу |
| FAULT | не використовується, проводу до PCB немає; GPIO33 керує SENS_PWR |
| Смуга | 100 кГц (звідси шум — фільтруємо RC 1 кОм + 1 мкФ) |
| Опір силового кола | ~0,6 мОм |
| Розміри | 17,8 × 20,3 мм (0,7″ × 0,8″) |

Підключення: **VCC, GND, VOUT** плюс окремі силові IP+ / IP−. Порядок на кабельних роз'ємах PCB визначено в connections.md, він не копіює порядок модуля. Позначення `VSS` з уточнення власника неоднозначне: не подавати на нього +3,3 В без перевірки маркування й паспорта. Орієнтація силового тракту лишається: від запобіжника в IP−, вузол B з IP+ → розряд нижче центру, заряд вище; перевірити знак на стенді.

Кількість: треба 3 (mACS1, mACS2 — лічильники гілок; mACS3 — струм навантаження), є 3. Альтернативний Pololu ACHS-7122 (#4031, ±20 А, є 1 шт.) потребує 4,5–5,5 В і має 100 мВ/А від 2,5 В, 80 кГц, 20,3 × 17,8 мм, контакти `VCC GND OUT`. Це не пряма заміна на поточній B: потрібні інше живлення, узгодження сигналу з ADS1115 3,3 В і нове калібрування.

⚠ Не плутати з числами ACS712 (185 мВ/А, нуль 2,5 В) — вони трапляються в старому коді.

Джерела: [Pololu #2452](https://www.pololu.com/product/2452) · [arduino.ua](https://arduino.ua/prod5340-acs711ex-current-sensor-carrier-15-5a-to-15-5a) · [Pololu #4031 ACHS-7122](https://www.pololu.com/product/4031/specs)

## mADC — ADS1115

16-бітний I2C АЦП **TI ADS1115** з програмованим підсилювачем (PGA) і компаратором ALERT. У пристрої — серце лічильника: 4 канали I_B1, I_B2, U_B1, U_B2 при PGA ±4,096 В (125 мкВ на LSB).

| Параметр | Значення |
|---|---|
| Розрядність | 16 біт |
| Канали | 4 single-ended або 2 диференційні |
| PGA | ±0,256 … ±6,144 В (6 діапазонів) |
| Швидкість | 8–860 вибірок/с (у нас 475 SPS, 4 канали по колу) |
| Живлення | 2,0–5,5 В (у нас 3,3 В) |
| I2C | 0x48 (ADDR→GND), 0x49 (VDD), 0x4A (SDA), 0x4B (SCL) |
| Розміри | ~28 × 17 мм |

Розпіновка: `VDD GND SCL SDA ADDR ALRT A0 A1 A2 A3`. Потрібні **два зовнішні модулі**, не на PCB B: J2 0x48 одержує аналог від B.J32 та живлення/I²C від A.J20; J13 0x49 від B.J33 та A.J21. Є один, **ще один перевірити або придбати**. Локально ADDR першого→GND, другого→VDD після розмикання заводської перемички на GND; ALRT NC, J13 A2/A3→GND. C6/C10 100 нФ біля VDD модулів перевірити або додати. На A одна пара підтяжок R16/R17; врахувати наявні підтяжки модулів. RC 1 кОм, еквівалент дільників нижче 10 кОм.

**Чому він, а не АЦП ESP32.** Вбудований АЦП ESP32 — 12-бітний SAR без власного опорного джерела (міряє відносно 3,3 В живлення з усіма його просадками), з відомою нелінійністю (мертві зони внизу й угорі шкали, до кількох відсотків без калібрувальної кривої), шумом ±5–10 LSB, який ще росте, щойно працює Wi-Fi; ADC2 при Wi-Fi недоступний узагалі. Для лічильника, що інтегрує 90 мВ/А довкола 1,65 В, це ±50–90 мА шуму й дрейф нуля з температурою чипа. ADS1115 — дельта-сигма з внутрішнім опорним джерелом, 16 біт, лінійний, з PGA і диференціальними входами: 1,4 мА на LSB, шум — одиниці LSB. Це не «крутіший модуль», а інший клас приладу; у популярних MCU (ESP32/S3/C3, RP2040, AVR, STM32 F1/F4) вбудованого АЦП такого класу немає. Модуль коштує ~100 грн і займає 28 × 17 мм.

Бібліотеки: Adafruit_ADS1X15 або RobTillaart/ADS1X15.

Джерела: [arduino.ua AOC540](https://arduino.ua/prod2118-16-bit-4-kanala-i2c-acp) · [даташит ADS1115](https://www.ti.com/lit/ds/symlink/ads1115.pdf)

## mMCU — ESP32 DevKitC, 38 пінів

Плата на модулі **ESP32-WROOM-32**: 2 × Xtensa LX6 240 МГц, 520 КБ SRAM, 4 МБ flash, Wi-Fi 802.11 b/g/n + BT 4.2; USB-C, USB-UART **CH340** (драйвер CH341SER); логіка 3,3 В; живлення 5 В на пін VIN/5V; стабілізатор 3,3 В віддає до ~500 мА (з нього — mADC, датчики, mOLED).

Обмеження пінів, які поважає connections.md:

| Піни | Обмеження |
|---|---|
| GPIO6–11 | зайняті flash — не використовувати |
| GPIO34, 35, 36, 39 | тільки входи, без підтяжок; у модульній ревізії NC, аналогові канали на B |
| GPIO0, 2, 12, 15 | strapping — не вішати на них те, що може змінити рівень при старті |
| ADC2 | недоступний під час Wi-Fi; поточна ревізія не використовує ні ADC1, ні ADC2 ESP |
| UART0 (GPIO1/3) | USB-консоль; для Modbus — UART2 на будь-яких вільних GPIO через матрицю |

Розміри 55 × 28 мм, висота з гребінками 13 мм ✔. Кількість: треба 1, є 2 (+ плата розширення 65 × 55 з гніздами — для стенду).

Джерела: [Espressif ESP32-DevKitC](https://docs.espressif.com/projects/esp-dev-kits/en/latest/esp32/esp32-devkitc/index.html) · [arduino.ua AOC720](https://arduino.ua/prod3990-wi-fi-modyl-devkit-v1-s-esp-32)

## mDC5 — LM2596 (HW-411)

Понижувальний перетворювач на LM2596: одна котушка «470», багатообертовий тример, стрілка IN → OUT на платі. У пристрої: 27–29 В з діодного «АБО» вузлів B1/B2 → 5 В для mMCU і обмоток реле K1/K2.

| Параметр | Значення |
|---|---|
| Вхід | 4,5–**40 В** (усі чотири плати — звичайні, не HV) |
| Вихід | 3–35 В тримером |
| Струм | 2 А паспортно; **реально 1–1,5 А тривало**, гріється вже понад 1 А |
| Мін. різниця вхід–вихід | 1,5 В |
| Частота | 150 кГц |
| Розміри | 44 × 22 × 15 мм |

Наш найгірший випадок — ≈ 0,5 А (2 обмотки × 71 мА + ESP32 з Wi-Fi 0,25 А, пік 0,4 + OLED і датчики ~50 мА): у межах, але з падінням 24 В при 5 В виходу втрати ~0,6 Вт — панельку не затискати між іншими модулями, лишити повітря. Кількість: треба 1, є 4.

⚠ Немає захисту від переполюсування на вході. Тример — 20–40 обертів, не «зламаний». Напругу виставляти **до** підключення навантаження.

Джерело: [arduino.ua AOC251](https://arduino.ua/prod650-dc-dc-ponijyuchii-konverter-lm2596-z-4-5-40v-do-3-35v)

## mOLED — OLED 0,96″ SSD1306, I2C

Монохромний 128 × 64 на SSD1306/SSD1315, I2C, живлення 3,3–5 В, рівні 3,3 В, адреса 0x3C (у даташитах — 0x78, те саме число). Активна область 24,8 × 16,8 мм, плата 28 × 28 (варіант з перемичкою адреси — 27,6 × 27,8). Є три плати двох різновидів, і **порядок пінів у них протилежний**:

| Плата | Порядок пінів | Є |
|---|---|---|
| 4-пін без перемички | `GND VDD SCK SDA` | 1 |
| з перемичкою адреси 0x78/0x7A | `SDA SCL GND VCC` | 2 |

Тому гребінка OLED на платі A підписується за конкретним екземпляром, який стане в корпус, і звіряється з шовкографією перед кожним підключенням. Статична картинка випалює пікселі — прошивка гасить екран за таймаутом і зсуває зображення. Бібліотека: U8g2 (менше RAM, більше шрифтів) або Adafruit SSD1306. Кількість: треба 1, є 3.

Джерело: [arduino.ua AOB484](https://arduino.ua/prod7649-displei-0-96-i2c-128x64-jovto-sinii-ssd1306-28x28mm)

## T1, T2 — DS18B20 у гільзі

Цифровий датчик **DS18B20** у герметичній гільзі з нержавійки Ø6 × 50 мм (IP67), кабель ~1 м, 3 жили. 1-Wire з підтяжкою 4,7 кОм DATA → 3,3 В; кілька датчиків на одному піні, кожен зі своєю 64-бітною адресою.

| Параметр | Значення |
|---|---|
| Живлення | 3,0–5,5 В |
| Діапазон | −55…+125 °C (з ПВХ-кабелем практично до ~100 °C) |
| Точність | ±0,5 °C у −10…+85 °C |
| Роздільність | 9–12 біт (0,0625 °C) |

Жили: червона VCC, чорна GND, жовта (біла/синя) DATA. У пристрої: T1 на LiFePO₄ (заборона заряду < 0 °C), T2 на свинці (термокомпенсація −3 мВ/°C на банку = −36 мВ/°C на 24 В). Бібліотеки: OneWire + DallasTemperature. Кількість: треба 2, є 2.

Джерела: [arduino.ua DAT133](https://arduino.ua/prod414-temperatyrnii-datchik-vodonepronicaemii-ds18b20) · [даташит DS18B20](https://www.analog.com/media/en/technical-documentation/data-sheets/DS18B20.pdf)

## Інструменти (у корпус не входять)

**FT232RL, USB → UART TTL.** mini-USB, перемичка рівнів 3,3 / 5 В (для DPS5015 — **3,3 В**), піни `DTR RX TX VCC CTS GND`, до 3 Мбод. Для перевірки зв'язку з DPS5015 і як консоль. ~36 × 18 мм, є 1.

**DSN-VC288, вольт-амперметр 100 В / 10 А.** Два дисплеї 0,28″ (червоний — вольти, синій — ампери), вбудований шунт у **мінусовому** проводі, точність ±1 % ± 1 розряд, живлення індикатора 4,5–10 В окремим тонким проводом (≤ 20 мА; від вимірюваного кола не живити — покази пливуть). Товсті чорні дроти — коло шунта; тонкі: червоний +живлення, чорний −живлення, жовтий — вхід напруги. Корпус 48 × 29 × 21. Еталон при калібруванні масштабу датчиків струму. Є 1.

## Вентилятор 50 × 50, 5 В (опція)

Власний, не з покупних модулів. Стандартний осьовий 50 × 50 мм, товщина 10…15 мм, отвори під M4 з міжцентровими **40 × 40 мм**. Місце під нього закладене в стінці корпусу навпроти радіатора DPS5015; живлення — 5 В з mDC5 або з фанового роз'єму DPS. Ставиться лише за результатом теплового тесту; до того отвір закритий заглушкою-решіткою.

## Резерв (є в наявності, у базову схему не входять)

| Модуль | Коли знадобиться |
|---|---|
| Pololu Mini Pushbutton #2808 | **не годяться** на гілки: LV, 2,2–20 В |
| ACS758 ±100 А (LCB-100B, знімний клемник) | якщо струм навантаження виросте за 15 А |
| CD74HC4067, 16-канальний аналоговий мультиплексор | якщо каналів АЦП забракне |
| модуль SD-card (SPI) + DS3231 (RTC, I2C 0x68) | автономний журнал без сервісу |
| INA3221 (3 канали струм/напруга, I2C 0x40–0x43, шунти 0,1 Ом) | **не годиться** для гілок: шина до 26 В (у нас до 29 В), вбудовані шунти лише до ±1,6 А |
| Шотткі TO-220 (MBR2045CT / MBR20100CT / MBR1645) | заміна будь-якого XL74610 при відмові, на радіаторі |

## Базові компоненти для плат ЛУТ

Зовнішні силові підключення корпуса: **XT60** для входу БЖ і виходу LOAD за уточненням власника; у механічній ревізії також закладені XT60 BAT1/BAT2. Загалом чотири парні порти. Точні модифікації, стать контактів, наявність і панельне кріплення ще не підтверджені. Не підміняти ці порти одиночними гвинтовими клемами; внутрішні клемники модулів залишаються.

Кілька популярних номіналів; підійде будь-який із ряду. Резистори — SMD 1206 (без свердління); кераміка є в шухляді і SMD, і виводна, тому посадкові місця під конденсатори лишаються **суміщені**, щоб паяти те, що знайдеться.

| Для чого | Номінал | Варіанти |
|---|---|---|
| Дільники U_B1, U_B2 (→ ADS1115, шкала ±4,096 В; 30 В → 2,73 В) | 1 : 11 | 100k + 10k · 47k + 4,7k · 22k + 2,2k · 10k + 1k (1 %) |
| Дільник U_LOAD (→ ADS1115 0x49 A1; 30 В → 1,35 В) | 1 : 21–22 | 20k + 1k · 47k + 2,2k · 100k + 4,7k; у CAD 100k/4,7k |
| Фільтр на виході кожного дільника | 100 нФ | керамічний |
| Фільтр на виході кожного датчика струму (зріз ≈ 160 Гц) | 1 кОм + 1 мкФ | резистор + кераміка |
| Ключі входів реле K1/K2 | NPN × 2 + 1 кОм у базу + 10 кОм база–емітер | BC547 · 2N2222 · S8050 · 2N3904 — будь-який |
| Підтяжка 1-Wire | 4,7 кОм | 2,2k–4,7k |
| «АБО» живлення логіки VD1, VD2 | Шотткі ≥ 1 А, ≥ 40 В | 1N5819 · SS34 · 1N5822 · SR560 |
| Запасний діод на випадок відмови XL74610 | Шотткі здвоєний TO-220, ≥ 45 В, обидві половини в паралель (спільний катод, аноди разом) → 2 × 10 А | MBR2045CT · MBR20100CT · MBR1645 |
| Буфер шини LOAD (мінімум на старт) | **алюмінієвий електроліт 100 мкФ / 50 В + 100 нФ кераміка поруч**; місце під TVS 33 В лишити порожнім | будь-який електроліт 47–220 мкФ на 50–63 В; TVS потім: SMBJ33A · P6KE33A · 1.5KE33A |
| Запобіжники F1, F2 (гілки), Fchg, Fout | ножові (ATO) + тримачі | 15 А (гілки), **15 А (заряд** — ATO тримає 10 А тривало лише з дерейтингом**)**, 15 А (вихід) |
| Гребінки 2,54 прямі й кутові, корпуси DuPont | — | є |
| Клемники гвинтові 5 мм (2- і 3-контактні), силові клеми | — | є; силові — під переріз дроту гілок |

**Про запасний Шотткі.** Це не паралель до XL74610 — це заміна на випадок, якщо один із трьох модулів здохне (резерву XL74610 немає). Здвоєний TO-220 зі спільним катодом: аноди з'єднати — обидва кристали працюють паралельно, 20 А сумарно; на радіаторі, бо 0,5 В × 7 А = 3,5 Вт.

**Скільки ставити на старт.** 100 мкФ / 50 В (підійде будь-що з 47–220 мкФ) плюс 100 нФ кераміки поруч — цього досить, щоб з'їсти індуктивний викид дротів при вимкненні ключа: при 7 А і ~2 мкГн петлі це 49 мкДж, на 100 мкФ дає підйом менш як 1 В. Виводи коротити (≤ 10 мм від клеми LOAD+ до мінус-шини) — довгий вивід зводить нанівець сенс конденсатора. Пусковий струм при вмиканні ключа в розряджену шину теж не проблема: 100 мкФ × 29 В = 42 мДж, ключ #2815 короткочасно тримає 90 А. Що робити далі — вирішить осцилограф на кроці 7: якщо викид при вимкненні під навантаженням перевищує ~35 В, у порожнє місце стає TVS; якщо DC-DC навантаження чутливі до просідання у вікна підзарядки драйвера XL74610 — збільшити ємність (до ~470 мкФ без наслідків).

**Про конденсатор на шині — не тантал.** Задача цього конденсатора — приймати індуктивний викид дротів у момент, коли ключ або XL74610 закривається, і живити шину ті ~2 % часу, коли XL74610 підзаряджає свій драйвер. Тантал тут — найгірший вибір: не терпить перенапруг і кидків струму, а відмовляє коротким замиканням і горінням; для шини 29 В треба було б ≥ 50–63 В танталу з дерейтингом, таких у шухляді не буває. Алюмінієвий електроліт 100 мкФ / 50 В (або 63 В) + кераміка 1 мкФ поруч + TVS — і все. Тантал годиться на 3,3/5-вольтовій логіці, якщо захочеться.

**Посадкові місця.** Актуальне рішення за планом 2.2: резистори — **тільки SMD 1206**, без отворів і без додаткових падів 2512; кераміка C3–C9 — пади SMD 1206 між двома отворами під виводний корпус з кроком 5,08 мм (отвір 0,8, пад 2,0). На одну позицію кераміки ставиться один корпус. C1/C2 і D3 не мають місць на PCB: вони зовнішні, D3 не встановлюється. Розміри падів для ЛУТ — у плані, крок 2.2; фактичні посадки перед виготовленням звірити з деталями.

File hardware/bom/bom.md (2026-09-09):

# BOM — комплектувальний список

Комплектувальний список модульної ревізії; характеристики — [docs/components.md](../../docs/components.md). Повний [BOM KiCad](../batman/output/bom.csv), [перемички](../batman/output/jumpers.csv) і [кабелі](../batman/output/interboard-cables.csv) випускаються генератором. Наявність старих деталей збережена за попереднім списком; другий ADS1115 і додаткові роз'єми потребують перевірки комплектації. Монтаж — [hardware/README.md](../README.md).

Чотири PCB: A ESP із двома портами ADS, B аналогові фільтри, C 3V3, D 5V. NT1 на D — мідь; WA1–WA4 на A — локальні дроти. CB2–CB6: п'ять кабелів/13 жил; ще чотири кабелі ADS/16 жил. C1/C2 навісні, D3 **DNP**. J1 — DevKitC із гніздами; J2/J13 — два зовнішні ADS без посадок на PCB, не дублікати mADC нижче.

| Позначення | Що це | К-сть | Де | Статус |
|---|---|---|---|---|
| X5 | U_LOAD_SENSE ← LOAD+ — клемник 5 мм | 1 | B | є |
| X3 | +5V GND ← mDC5 OUT — клемник 5 мм | 1 | D | є |
| X2 | VIN_DC GND → mDC5 IN — клемник 5 мм | 1 | D | є |
| X1 | B1 B2 GND — клемник 5 мм | 1 | D | є |
| X4 | DS18B20 ×2: DATA 3V3 GND — клемник 5 мм | 1 | плата A | є |
| J11 | BTN — гребінка 2,54 (пряма або кутова за місцем) | 1 | плата A | є |
| J6 | mSW1 GND ON — гребінка 2,54 (пряма або кутова за місцем) | 1 | плата A | є |
| J7 | mSW2 GND ON — гребінка 2,54 (пряма або кутова за місцем) | 1 | плата A | є |
| J9 | DPS TX RX GND — гребінка 2,54 | 1 | плата A | є |
| J10 | OLED VDD SCL SDA GND — гребінка 2,54 | 1 | плата A | є |
| J3 | mACS1 VOUT GND VCC — гребінка 3 × 2,54 | 1 | B | є |
| J4 | mACS2 VOUT GND VCC — гребінка 3 × 2,54 | 1 | B | є |
| J5 | mACS3 VCC VOUT GND — гребінка 3 × 2,54 | 1 | B | є |
| J8 | mREL2 IN1 GND IN2 VCC JD-VCC — гребінка 2,54 | 1 | D | є |
| J12 | SPI резерв MOSI GND MISO SCK CS 3V3 — гребінка 2,54 | 1 | плата A | є |
| C3, C4, C5 | 100n — керамічний конденсатор | 3 | B | є |
| C6, C10 | 100n ≥16 В VDD–GND біля ADS | 2 | зовнішні J2/J13 | перевірити наявні на модулях; додати лише за відсутності |
| C7, C8, C9 | 1µ — керамічний конденсатор | 3 | B | є |
| C11–C13 | 100n ≥16 В, THT або 1206 | 3 | C11/C12 C; C13 D | додаткові, перевірити |
| VD1, VD2 | 1N5819 осьові; SS34 потребує іншої посадки | 2 | D | є |
| R1, R3, R5 | 100k 1%, SMD 1206 | 3 | B | є |
| R11, R13, R15 | 10k, SMD 1206 | 3 | R11 C; R13/R15 A | є |
| R2, R4 | 10k 1%, SMD 1206 | 2 | B | є |
| R7, R8, R9, R12, R14 | 1k, SMD 1206 | 5 | R7–R9 B; R12/R14 A | є |
| R10, R16, R17, R18 | 4.7k, SMD 1206 | 4 | R10 C; R16–R18 A | є |
| R6 | 4.7k 1%, SMD 1206 | 1 | B | є |
| Q1, Q2 | BC547 — NPN — ключ входу реле (будь-який малопотужний NPN) | 2 | плата A | є |
| Q3 | BC557 — PNP — ключ живлення датчиків | 1 | C | є |
| mADC / J2 | ADS1115, 0x48 (ADDR→GND), кабельний монтаж | 1 | зовнішній, біля B | є |
| другий mADC / J13 | ADS1115, 0x49 (ADDR→VDD), кабельний монтаж | 1 | зовнішній, біля B | додатковий, перевірити або придбати |
| J20, J21 | гребінки 1×4 2,54 мм, порти ADS | 2 | A | перевірити |
| J22, J23, J28, J29, J33 | гребінки 1×3 2,54 мм | 5 | за pinout.csv | перевірити |
| J24–J27, J30, J31 | гребінки 1×2 2,54 мм | 6 | за pinout.csv | перевірити |
| J32 | гребінка 1×5 2,54 мм, аналог до J2 | 1 | B | перевірити |
| X6, X8 | клемник 1×3, крок 5 мм | 2 | D, B | додаткові, перевірити |
| mMCU | ESP32 DevKitC — ESP32-DevKitC 38 пін; піни 1–19 ліва гребінка зверху вниз, 20–38 права; сидить у гніздах J1 | 1 | плата A (у гнізді) | є |
| XLP | LOAD+ (P06 P12 P13) — силовий клемний блок ≥10 А | 1 | зовнішній вузол шин | є |
| XGND | GND-шина (P24–P28) — силовий клемний блок ≥10 А | 1 | зовнішній вузол шин | є |
| C2 | 100n — керамічний конденсатор | 1 | навісно на шині | є |
| C1 | 100µ 50V — електроліт 50 В, буфер шини LOAD+ | 1 | навісно на шині | є |
| D3 | SMBJ33A / 1.5KE33 — TVS на шині LOAD+ (опція, DNP) | 1 | навісно, не встановлювати | є |
| mACS1, mACS2, mACS3 | триконтактні VCC/GND/VOUT до B; припущення ACS711EX 3,3 В / 90 мВ/А перевірити | 3 | зовнішні модулі | є, модель уточнити |
| mDPS | DPS5015 — RuiDeng DPS5015 без дисплея; Modbus RTU 9600 8N1 адреса 1 на порту V R T G | 1 | модуль, дюпони/дроти | є |
| mDC5 | LM2596 → 5.0 V — DC-DC 27–29 В → 5,0 В для логіки й обмоток реле | 1 | модуль, дюпони/дроти | є |
| mOLED | OLED 0.96" — SSD1306 128×64, 0x3C; порядок пінів — за екземпляром (див. components.md) | 1 | модуль, дюпони/дроти | є |
| mSW1, mSW2 | Pololu #2815 — Big MOSFET Slide Switch HP: повзунок задає стан без контролера, ON — від GPIO 3,3 В | 2 | модуль, дюпони/дроти | є |
| mREL2 | реле 2-кан. — Модуль реле 2-кан., тригер за низьким рівнем, оптрони; перемичка VCC–JD-VCC знята | 1 | модуль, дюпони/дроти | є |
| mDIO1, mDIO2, mDIO3 | XL74610 — Ідеальний діод LM74610 + MOSFET; дроти напаяні на площадки | 3 | модуль, дюпони/дроти | є |
| XB1 | BAT1 — клемник 5 мм / силова клема панелі | 1 | панель / корпус | є |
| XB2 | BAT2 — клемник 5 мм / силова клема панелі | 1 | панель / корпус | є |
| XLOAD | LOAD — клемник 5 мм / силова клема панелі | 1 | панель / корпус | є |
| XPSU | БЖ 33V 10A — клемник 5 мм / силова клема панелі | 1 | панель / корпус | є |
| F1, F2, Fchg, Fout | ATO 15A — запобіжник ATO 15 А в тримачі (задня панель) | 4 | панель / корпус | є |
| T1 | DS18B20 Bat1 — DS18B20 у гільзі з кабелем | 1 | панель / корпус | є |
| T2 | DS18B20 Bat2 — DS18B20 у гільзі з кабелем | 1 | панель / корпус | є |
| SW1 | кнопка панелі — кнопка 12 мм на передній панелі | 1 | панель / корпус | є |

Поза компонентним BOM: CB2–CB6 (13 жил), чотири кабелі ADS (16 жил), локальні з'єднання ADDR/A2/A3 і GND на ADS, чотири перемички A, силовий дріт, прямі корпуси DuPont та ізоляція, 16 точок M3 і два ізольовані тримачі ADS. Довжини джгутів визначати за корпусом; ADS ставити біля B.

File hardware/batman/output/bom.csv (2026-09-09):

Reference | Documentation_alias | Value | Quantity | Location | Populate
J1 |  | DevKitC_38_socket_mMCU | 1 | A | yes
J2 |  | ADS1115_0x48_EXTERNAL | 1 | external | yes
J3 |  | ACS1_3WIRE | 1 | B | yes
J4 |  | ACS2_3WIRE | 1 | B | yes
J5 |  | ACS3_3WIRE | 1 | B | yes
J6 |  | SW1_GND_ON | 1 | A | yes
J7 |  | SW2_GND_ON | 1 | A | yes
J8 |  | RELAY | 1 | D | yes
J9 |  | DPS_UART | 1 | A | yes
J10 |  | OLED_I2C | 1 | A | yes
J11 |  | BUTTON | 1 | A | yes
J12 |  | SPI | 1 | A | yes
X1 |  | B1_B2_GND | 1 | D | yes
X2 |  | VIN_DC_GND | 1 | D | yes
X3 |  | 5V_GND | 1 | D | yes
X4 |  | DS18B20 | 1 | A | yes
X5 |  | U_LOAD_SENSE | 1 | B | yes
NT1 |  | COPPER_STAR_AT_X3 | 1 | D | copper only
VD1 |  | 1N5819 | 1 | D | yes
VD2 |  | 1N5819 | 1 | D | yes
R1 |  | 100k_1% | 1 | B | yes
R2 |  | 10k_1% | 1 | B | yes
C3 |  | 100n_50V | 1 | B | yes
R3 |  | 100k_1% | 1 | B | yes
R4 |  | 10k_1% | 1 | B | yes
C4 |  | 100n_50V | 1 | B | yes
R5 |  | 100k_1% | 1 | B | yes
R6 |  | 4.7k_1% | 1 | B | yes
C5 |  | 100n_50V | 1 | B | yes
R7 |  | 1k | 1 | B | yes
C7 |  | 1u_16V | 1 | B | yes
R8 |  | 1k | 1 | B | yes
C8 |  | 1u_16V | 1 | B | yes
R9 |  | 1k | 1 | B | yes
C9 |  | 1u_16V | 1 | B | yes
C6 |  | 100n_16V | 1 | external | yes
R10 |  | 4.7k | 1 | C | yes
R11 |  | 10k | 1 | C | yes
Q3 |  | BC557_CBE | 1 | C | yes
R12 |  | 1k | 1 | A | yes
R13 |  | 10k | 1 | A | yes
Q1 |  | BC547_CBE | 1 | A | yes
R14 |  | 1k | 1 | A | yes
R15 |  | 10k | 1 | A | yes
Q2 |  | BC547_CBE | 1 | A | yes
R16 |  | 4.7k | 1 | A | yes
R17 |  | 4.7k | 1 | A | yes
R18 |  | 4.7k | 1 | A | yes
XLP1 | XLP | LOAD_P06_P12_P13 | 1 | external | yes
XGND1 | XGND | GND_P24_P25_P26_P27_P28 | 1 | external | yes
C1 |  | 100u_50V_ALUMINIUM | 1 | external | yes
C2 |  | 100n_50V | 1 | external | yes
D3 |  | 1.5KE33A_DNP | 1 | external | DNP
XB1 |  | BAT1_PANEL | 1 | external | yes
F1 |  | ATO_15A | 1 | external | yes
mACS1 |  | ACS711EX_15.5A | 1 | external | yes
mSW1 |  | Pololu_2815_HP | 1 | external | yes
mDIO1 |  | XL74610 | 1 | external | yes
XB2 |  | BAT2_PANEL | 1 | external | yes
F2 |  | ATO_15A | 1 | external | yes
mACS2 |  | ACS711EX_15.5A | 1 | external | yes
mSW2 |  | Pololu_2815_HP | 1 | external | yes
mDIO2 |  | XL74610 | 1 | external | yes
mACS3 |  | ACS711EX_15.5A | 1 | external | yes
Fout1 | Fout | ATO_15A | 1 | external | yes
XLOAD1 | XLOAD | LOAD_PANEL | 1 | external | yes
XPSU1 | XPSU | PSU_33V_10A_PANEL | 1 | external | yes
mDPS1 | mDPS | DPS5015_9600_8N1_ADDR1 | 1 | external | yes
Fchg1 | Fchg | ATO_15A | 1 | external | yes
mDIO3 |  | XL74610 | 1 | external | yes
mREL2 |  | FL_3FF_5V_10A_REMOVE_JUMPER | 1 | external | yes
mDC5 |  | LM2596_SET_5.0V_FIRST | 1 | external | yes
mOLED1 | mOLED | SSD1306_0x3C | 1 | external | yes
T1 |  | DS18B20_PROBE | 1 | external | yes
T2 |  | DS18B20_PROBE | 1 | external | yes
SW1 |  | PANEL_BUTTON_NO | 1 | external | yes
J13 |  | ADS1115_0x49_EXTERNAL | 1 | external | yes
C10 |  | 100n_16V | 1 | external | yes
C11 |  | 100n_16V | 1 | C | yes
C12 |  | 100n_16V | 1 | C | yes
C13 |  | 100n_16V | 1 | D | yes
J20 |  | LINK_+3V3_GND_SCL_SDA | 1 | A | yes
J21 |  | LINK_+3V3_GND_SCL_SDA | 1 | A | yes
J22 |  | LINK_+3V3_GND_SENS_PWR | 1 | A | yes
J23 |  | LINK_+3V3_GND_SENS_PWR | 1 | C | yes
J24 |  | LINK_GND_+3V3_SENS | 1 | C | yes
J25 |  | LINK_GND_+3V3_SENS | 1 | B | yes
J26 |  | LINK_+5V_GND | 1 | A | yes
J27 |  | LINK_+5V_GND | 1 | D | yes
J28 |  | LINK_RELAY_IN1_RELAY_IN2_GND | 1 | A | yes
J29 |  | LINK_RELAY_IN1_RELAY_IN2_GND | 1 | D | yes
J30 |  | LINK_+3V3_GND | 1 | C | yes
J31 |  | LINK_+5V_GND | 1 | D | yes
J32 |  | LINK_I_B1_I_B2_U_B1_U_B2_GND | 1 | B | yes
J33 |  | LINK_I_LOAD_U_LOAD_GND | 1 | B | yes
X6 |  | BAT_SENSE_TO_B | 1 | D | yes
X8 |  | BAT_SENSE_FROM_D | 1 | B | yes

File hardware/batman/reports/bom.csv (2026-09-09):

Reference | Documentation_alias | Value | Quantity | Location | Populate
J1 |  | DevKitC_38_socket_mMCU | 1 | A | yes
J2 |  | ADS1115_socket_mADC | 1 | A | yes
J3 |  | ACS1_3WIRE | 1 | A | yes
J4 |  | ACS2_3WIRE | 1 | A | yes
J5 |  | ACS3_3WIRE | 1 | A | yes
J6 |  | SW1_GND_ON | 1 | A | yes
J7 |  | SW2_GND_ON | 1 | A | yes
J8 |  | RELAY | 1 | A | yes
J9 |  | DPS_UART | 1 | A | yes
J10 |  | OLED_I2C | 1 | A | yes
J11 |  | BUTTON | 1 | A | yes
J12 |  | SPI | 1 | A | yes
X1 |  | B1_B2_GND | 1 | A | yes
X2 |  | VIN_DC_GND | 1 | A | yes
X3 |  | 5V_GND | 1 | A | yes
X4 |  | DS18B20 | 1 | A | yes
X5 |  | U_LOAD_SENSE | 1 | A | yes
NT1 |  | COPPER_STAR_AT_X3 | 1 | A | copper only
VD1 |  | 1N5819 | 1 | A | yes
VD2 |  | 1N5819 | 1 | A | yes
R1 |  | 100k_1% | 1 | A | yes
R2 |  | 10k_1% | 1 | A | yes
C3 |  | 100n_50V | 1 | A | yes
R3 |  | 100k_1% | 1 | A | yes
R4 |  | 10k_1% | 1 | A | yes
C4 |  | 100n_50V | 1 | A | yes
R5 |  | 100k_1% | 1 | A | yes
R6 |  | 4.7k_1% | 1 | A | yes
C5 |  | 100n_50V | 1 | A | yes
R7 |  | 1k | 1 | A | yes
C7 |  | 1u_16V | 1 | A | yes
R8 |  | 1k | 1 | A | yes
C8 |  | 1u_16V | 1 | A | yes
R9 |  | 1k | 1 | A | yes
C9 |  | 1u_16V | 1 | A | yes
C6 |  | 100n_16V | 1 | A | yes
R10 |  | 4.7k | 1 | A | yes
R11 |  | 10k | 1 | A | yes
Q3 |  | BC557_CBE | 1 | A | yes
R12 |  | 1k | 1 | A | yes
R13 |  | 10k | 1 | A | yes
Q1 |  | BC547_CBE | 1 | A | yes
R14 |  | 1k | 1 | A | yes
R15 |  | 10k | 1 | A | yes
Q2 |  | BC547_CBE | 1 | A | yes
R16 |  | 4.7k | 1 | A | yes
R17 |  | 4.7k | 1 | A | yes
R18 |  | 4.7k | 1 | A | yes
XLP1 | XLP | LOAD_P06_P12_P13 | 1 | external | yes
XGND1 | XGND | GND_P24_P25_P26_P27_P28 | 1 | external | yes
C1 |  | 100u_50V_ALUMINIUM | 1 | external | yes
C2 |  | 100n_50V | 1 | external | yes
D3 |  | 1.5KE33A_DNP | 1 | external | DNP
XB1 |  | BAT1_PANEL | 1 | external | yes
F1 |  | ATO_15A | 1 | external | yes
mACS1 |  | ACS711EX_15.5A | 1 | external | yes
mSW1 |  | Pololu_2815_HP | 1 | external | yes
mDIO1 |  | XL74610 | 1 | external | yes
XB2 |  | BAT2_PANEL | 1 | external | yes
F2 |  | ATO_15A | 1 | external | yes
mACS2 |  | ACS711EX_15.5A | 1 | external | yes
mSW2 |  | Pololu_2815_HP | 1 | external | yes
mDIO2 |  | XL74610 | 1 | external | yes
mACS3 |  | ACS711EX_15.5A | 1 | external | yes
Fout1 | Fout | ATO_15A | 1 | external | yes
XLOAD1 | XLOAD | LOAD_PANEL | 1 | external | yes
XPSU1 | XPSU | PSU_33V_10A_PANEL | 1 | external | yes
mDPS1 | mDPS | DPS5015_9600_8N1_ADDR1 | 1 | external | yes
Fchg1 | Fchg | ATO_15A | 1 | external | yes
mDIO3 |  | XL74610 | 1 | external | yes
mREL2 |  | FL_3FF_5V_10A_REMOVE_JUMPER | 1 | external | yes
mDC5 |  | LM2596_SET_5.0V_FIRST | 1 | external | yes
mOLED1 | mOLED | SSD1306_0x3C | 1 | external | yes
T1 |  | DS18B20_PROBE | 1 | external | yes
T2 |  | DS18B20_PROBE | 1 | external | yes
SW1 |  | PANEL_BUTTON_NO | 1 | external | yes

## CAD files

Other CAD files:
mechanical/cad/assembly-cable-modular.blend
mechanical/cad/assembly-cable-routing.blend
mechanical/cad/assembly-cable-supported.blend
mechanical/cad/assembly-detailed.blend
mechanical/cad/assembly.blend
mechanical/cad/revision-01.blend

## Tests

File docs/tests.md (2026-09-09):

# Перевірки

Бланки протоколів. Результат пишеться сюди ж, під протоколом; що змінилося внаслідок — у components / connections / concept.

## 0.1 Шум і нуль датчиків

Умови: ACS711EX від 3V3 DevKitC, ADS1115 PGA ±4,096, 475 SPS, запис 10 хв у CSV при **гарантовано нульовому струмі** (силовий дріт не підключений).

| Вимірювання | Без RC | З RC 1 кОм + 1 мкФ | Критерій |
|---|---|---|---|
| середнє V_zero, В | | | 1,60…1,70 |
| σ одного відліку, мА | | | |
| σ середнього за 1 с, мА | | | ≤ 20 |
| розмах за 10 хв, мА | | | |
| зсув через 12 год, мА | | | ≤ 30/добу |
| показ на 5 А проти DSN-VC288 | | | ± 2 % |
| те саме при Wi-Fi, що передає | | | без стрибків |

Висновок (план Б потрібен / не потрібен):

## Модульна Ревізія A–D

Це бланк фізичних перевірок, не результати CAD. Спочатку без батарей і DPS, від лабораторного джерела з обмеженням струму; модель mACS та значення VSS підтвердити до подачі живлення.

| Перевірка | Критерій | Результат |
|---|---|---|
| Прозвонка A/B/C/D і CB2–CB6 | немає КЗ; 13 жил за таблицею; CB1 відсутній, CB3 два контакти; CB6 не переплутаний з 3V3 | |
| Чотири кабелі окремих ADS | 16 жил за cable-map; A.J20/J21 до VDD/GND/SCL/SDA, B.J32/J33 до A0…/GND; на B немає I²C | |
| LM2596 → D → A | 5,0 В до встановлення ESP; полярність правильна, USB не створює зворотного живлення | |
| Живлення ADS і датчиків | ADS від A.J20/J21, датчики через C.J24 → B.J25; один LDO, виходи не живляться ззовні | |
| Бюджет 3V3, Wi-Fi + обидва ADS + OLED + датчики | записати піковий струм, просідання і температуру; у межах паспорта фактичного LDO | |
| GPIO33 (J1.8) / Q3 | HIGH/Hi-Z вимикає живлення датчиків, LOW вмикає; перевірити старт і reset; ADC не одержують недопустимих напруг | |
| ADDR і I²C | 0x48, 0x49, OLED 0x3C; заводська перемичка другого ADDR не коротить VDD на GND | |
| Локальні з'єднання ADS | C6/C10 100 нФ біля VDD; J13 A2/A3 GND; обидва ALRT NC; землі двох кабелів надійно зведені | |
| I²C 100 кГц, фронти осцилографом | допустимі рівні та час наростання з усіма підтяжками; без помилок під Wi-Fi | |
| Шість аналогових каналів | 0x48 A0/A1 струми, A2/A3 напруги гілок; 0x49 A0 I_LOAD, A1 U_LOAD; правильний MUX і масштаб | |
| GND кабелів, UART, реле | немає небезпечних струмів повернення; короткі аналогові кабелі не додають недопустимого шуму/зсуву | |
| Порядок підключення | лише при вимкненому живленні; аналогові напруги не подаються на знеструмлені ADS | |
| Посадки й монтаж | гнізда ESP, антена, окремі ізольовані тримачі ADS, 16 кріплень PCB і кабелі не конфліктують | |

## 4.x Прошивка

| Перевірка | Критерій | Результат |
|---|---|---|
| 4.1 ресет при ввімкнених ключах | стан ключів не змінився; лічильники відновились | |
| 4.2 показання проти DSN-VC288 / мультиметра | U ± 1 %, I ± 1 % при 5 А | |
| 4.3 година заряду | Ah_in проти ∫IOUT DPS ≤ 2 % | |
| 4.4 обрив UART під час заряду | FAULT_DPS ≤ 1,5 с, реле розімкнені, прошивка жива | |
| 4.5 повний цикл обох гілок | без втручання; переходи за таблицею | |
| 4.7 сервіс знаходить пристрій | mDNS і UDP; потік іде | |
| 4.8 тиждень | heap без тренду, втрати телеметрії < 0,1 %, зависань 0 | |

## 7 Стенд і приймання

| Крок | Критерій | Результат |
|---|---|---|
| 7.1 заряд одного акумулятора вручну | профіль витриманий, U на клемах = уставка ± 0,05 | |
| 7.1 mSW: повзунок OFF, ON-пін вільний / 3,3 В / GND | VOUT = 0 / VIN / 0 | |
| 7.1 mSW: повзунок ON, ON-пін GND | VOUT = VIN (примусово), прошивка показує `forced` | |
| 7.1 mSW: падіння при 5 А; ресет ESP32 (EN) | ≤ 50 мВ; ключ не вмикається | |
| 7.1 K1/K2 через NPN: GPIO HIGH / Hi-Z (ресет) / обидві обмотки | клац без деренчання / OFF / +5V ≥ 4,8 В | |
| 7.1 DPS: версія прошивки (0x000C), масштаб POWER і S-OPP, `dps_m0` + перезапуск живлення | вихід після старту вимкнений, U-SET 20,00 | |
| 7.2 калібрування | усі G_cal, V_zero записані; звірка Ah ≤ 2 % | |
| 7.3 повний цикл + тепловий тест 1 год при 10 А під кришкою | T корпусу реле, падіння на контакті K (≤ 100 мВ), T XL74610 при 5 і 10 А, T mDC5, T радіатора DPS; рішення про вентилятор | |
| 7.3 осцилограф на шині LOAD при вимкненні ключа під 7 А | викид ≤ 35 В (інакше TVS) | |
| 7.4 тиждень із сервісом | без втрат і зависань; агрегати збігаються з лічильниками ± 3 % | |

## Записи

(тут з'являються результати з датами)

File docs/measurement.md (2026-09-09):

# Вимірювання й підрахунок

Як із сирих відліків виходять струми, напруги, А·год і SoC. Номери каналів і коефіцієнти — connections.md; тут — що з ними робить прошивка.

## Канали й темп

| Канал | Джерело | Темп | Для чого |
|---|---|---|---|
| I_B1, I_B2, U_B1, U_B2 | Зовнішній J2 ADS1115 0x48 через B.J32; I²C/живлення через A.J20; PGA ±4,096 В, 475 SPS, чотири канали по колу; ALRT NC | ціль ≈ 118 відліків/с на канал, фактичний темп виміряти | підрахунок і керування |
| U_LOAD, I_LOAD | Зовнішній J13 ADS1115 0x49 через B.J33; I²C/живлення через A.J21; A1/A0, PGA ±4,096 В, 475 SPS; послідовні single-shot | 10 Гц на кожен канал | контроль, показ |
| T1, T2 | DS18B20, 12 біт | 1 Гц (конверсія 750 мс, асинхронно) | профіль свинцю, заборона заряду LiFePO₄ |
| DPS UOUT, IOUT, UIN, CV/CC, PROTECT, ONOFF | Modbus, блок 0x0000–0x0009 | 2 Гц | перехресна перевірка, ознака БЖ |

mACS підключені трьома проводами VCC/GND/VOUT. GPIO33 керує живленням через SENS_PWR; FAULT IRQ і апаратної відсічки від датчика немає. Масштаб 90 мВ/А та живлення 3,3 В застосовні лише після підтвердження фактичної моделі ACS711EX.

GPIO34/39 також NC: ADC ESP не використовується. Для обох ADS при PGA ±4,096 В LSB=125 мкВ; перетворення U_LOAD = V × (104,7/4,7), I_LOAD = (V_zero − V)/0,090 з калібруванням. Не застосовувати старі `esp_adc_cal`, атенюацію чи масштаб 12-бітного ESP. I²C спільна з OLED, 100 кГц; серіалізувати транзакції, не блокувати опитування очікуванням готовності іншого АЦП. При зміні MUX у continuous mode відкидати відлік попереднього каналу й перевірити фактичний темп; номінальні 475 SPS не гарантують 118 коректних відліків кожного каналу за секунду.

## Струм гілки

```
I_raw  = (V_adc − V_zero) / K_sens          K_sens = 0,090 В/А номінально
I      = I_raw × G_cal                       G_cal ≈ 1,00 — калібрування масштабу
```

- `V_zero` — збережений нуль каналу (номінал 1,650 В). Оновлюється **автонулем** і ручним калібруванням.
- Знак: **+ заряд** (у акумулятор), **− розряд** — так виходить з орієнтації датчиків (connections.md P02/P03).
- **Мертвої зони в підрахунку немає.** Кожен відлік іде в інтеграл як є.
- Для **показу** — ковзне середнє за 1 с (≈ 118 відліків); на екрані `|I| < 0,02 А` показуємо як `0,00`.
- Апаратний фільтр RC 1 кОм + 1 мкФ (≈ 160 Гц) стоїть перед АЦП — далі нічого не фільтруємо, щоб не вносити затримку в керування.

## Напруга гілки

`U = V_adc × K_div × G_ucal`, K_div = 11 номінально, `G_ucal` — калібрування проти мультиметра. Для показу — середнє за 0,5 с. Для керування уставкою DPS — середнє за 2 с (крок підтягування U-SET — див. dps5015-modbus.md).

## Інтегрування

Трапеціями, окремо для знаків:

```
dt      = t_k − t_(k−1)                            (мкс, з таймера відліку)
q       = (I_k + I_(k−1)) / 2 × dt                 (А·с)
if q > 0: Ah_in  += q / 3600;  Wh_in  += q × U / 3600
else:     Ah_out −= q / 3600;  Wh_out −= q × U / 3600
```

Накопичувачі — `double`, чотири на гілку × 2 набори: **наростаючим підсумком** (за все життя) і **за поточний цикл** (скидається в момент «100 %»). Плюс `cycles` — лічильник повних зарядів.

Перевірка: за годину заряду з постійним струмом сума `Ah_in` має збігтися з інтегралом IOUT з телеметрії DPS у межах 2 %. Розбіжність більша → масштаб датчика (G_cal) або нуль.

## Автонуль

Умова гарантовано нульового струму гілки X: **mSW_X вимкнений і не `forced`**, **заряд не на гілці X**, **логіку живить інша гілка** (U_другої > U_X + 0,3 В — тоді VD_X закритий і навіть 50 мА логіки йдуть не через датчик X).

Коли умова тримається ≥ 30 с:
```
V_zero_new = V_zero + α × (mean_30s(V_adc) − V_zero),  α = 0,1
```
— повільно, щоб одиночний викид не зсунув нуль. Оновлений `V_zero` пишеться в NVS не частіше ніж раз на годину. Дрейф понад 0,05 В від заводського 1,650 В → попередження в телеметрію (датчик або живлення).

Ручний нуль: команда `calibrate_zero` при знятому запобіжнику гілки — `V_zero = mean_5s(V_adc)`, без α.

## Масштаб

Команда `calibrate_gain {ch, i_ref}` під час заряду з постійним струмом: `G_cal = i_ref / I_raw_mean_10s`, де `i_ref` — показання DSN-VC288 у розриві або IOUT з DPS (з поправкою на струм логіки ≈ 0,05–0,1 А, який іде з вузла B повз DPS). Для напруги — `calibrate_ugain {ch, u_ref}` проти мультиметра.

## SoC

- `SoC = 100 % − Ah_out_cycle / C_nom + Ah_in_cycle × η / C_nom` у межах 0…100 %; `C_nom` — 50 / 65 А·год (параметр), `η` — ефективність заряду за замовчуванням 0,98 (LiFePO₄) і 0,90 (свинець), уточнюється з агрегатів сервісу.
- **Синхронізація «100 %»** — момент завершення заряду за профілем (firmware.md): LiFePO₄ — у CV струм ≤ 2,5 А; свинець — у absorption струм ≤ 1,3 А. Тоді `Ah_*_cycle ← 0`, `cycles += 1`, у сервіс іде подія `cycle_complete` з підсумками циклу.
- Без синхронізації SoC поступово втрачає сенс; після 7 діб без «100 %» показувати його з позначкою `~`.
- Пороги низького SoC/напруги (відсічка розряду) — у firmware.md.

## Що і коли в NVS

| Що | Коли | Навіщо |
|---|---|---|
| `Ah_in/out`, `Wh_in/out` — обидва набори, `cycles`, `SoC` | кожні **10 хв** і на кожній події (старт/стоп заряду, зміна ключів, FAULT, «100 %») | пережити ресет без втрати обліку |
| `V_zero[3]`, `G_cal[3]`, `G_ucal[3]` | після кожного калібрування; автонуль — не частіше ніж раз на годину | калібрування |
| конфіг (профілі, пороги, sink, Wi-Fi) | при зміні | |

NVS у ESP32 витримує ~100 000 записів на ключ; 10-хвилинний темп — 144 записи на добу, тобто роки. Частіше не треба: втрата ≤ 10 хв обліку при ресеті — це ≤ 1,7 А·год при 10 А, і подія «ресет» іде в сервіс, де по сирих даних це видно.

## Перехресні перевірки (раз на 2 с)

| Що | Умова тривоги | Реакція |
|---|---|---|
| I_BX проти DPS IOUT під час заряду X | розбіжність > 0,5 А + 5 % довше 10 с | попередження `sensor_mismatch` (не стоп: датчик може бути правий, а DPS — ні) |
| U_BX проти DPS UOUT при замкненому KX | > 1,0 В (падіння на mDIO3 + реле + дроти має бути ~0,3–0,5 В) | попередження, перевірити контакт реле |
| Сума I_B1 + I_B2 (у розряді) проти I_LOAD | > 0,5 А + 10 % | попередження |
| Струм гілки при вимкненому ключі й без заряду | |I| > 0,3 А довше 5 с | **повзунок mSW у ON** — стан `forced`; або залип K → попередження |

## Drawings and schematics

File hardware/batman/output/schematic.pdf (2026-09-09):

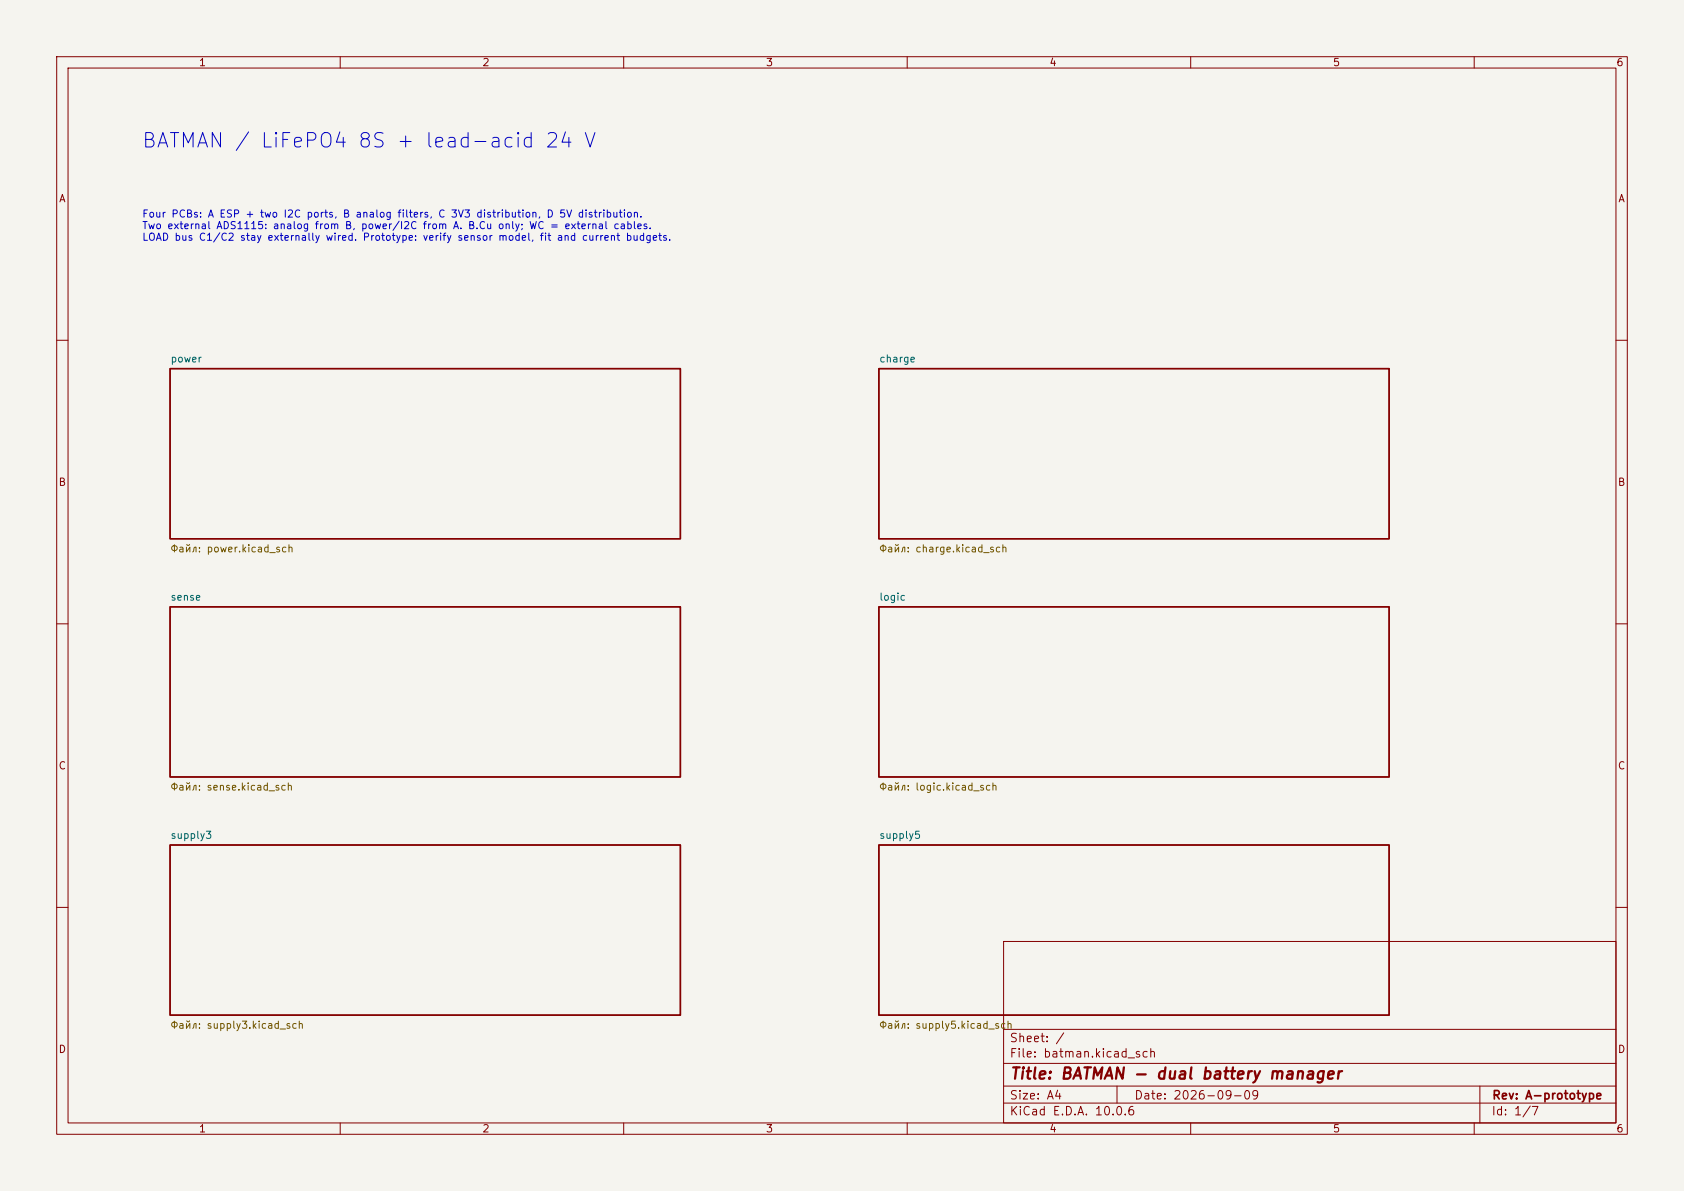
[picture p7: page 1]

Four PCBs: A ESP + two I2C ports, B analog filters, C 3V3 distribution, D 5V distribution. Two external ADS1115: analog from B, power/I2C from A. B.Cu only; WC = external cables. LOAD bus C1/C2 stay externally wired. Prototype: verify sensor model, fit and current budgets.

Sheet: /
File: batman.kicad_sch
Title: BATMAN - dual battery manager

Size: A4 | Rev: A-prototype
KiCad E.D.A. 10.0.6 | Id: 1/7

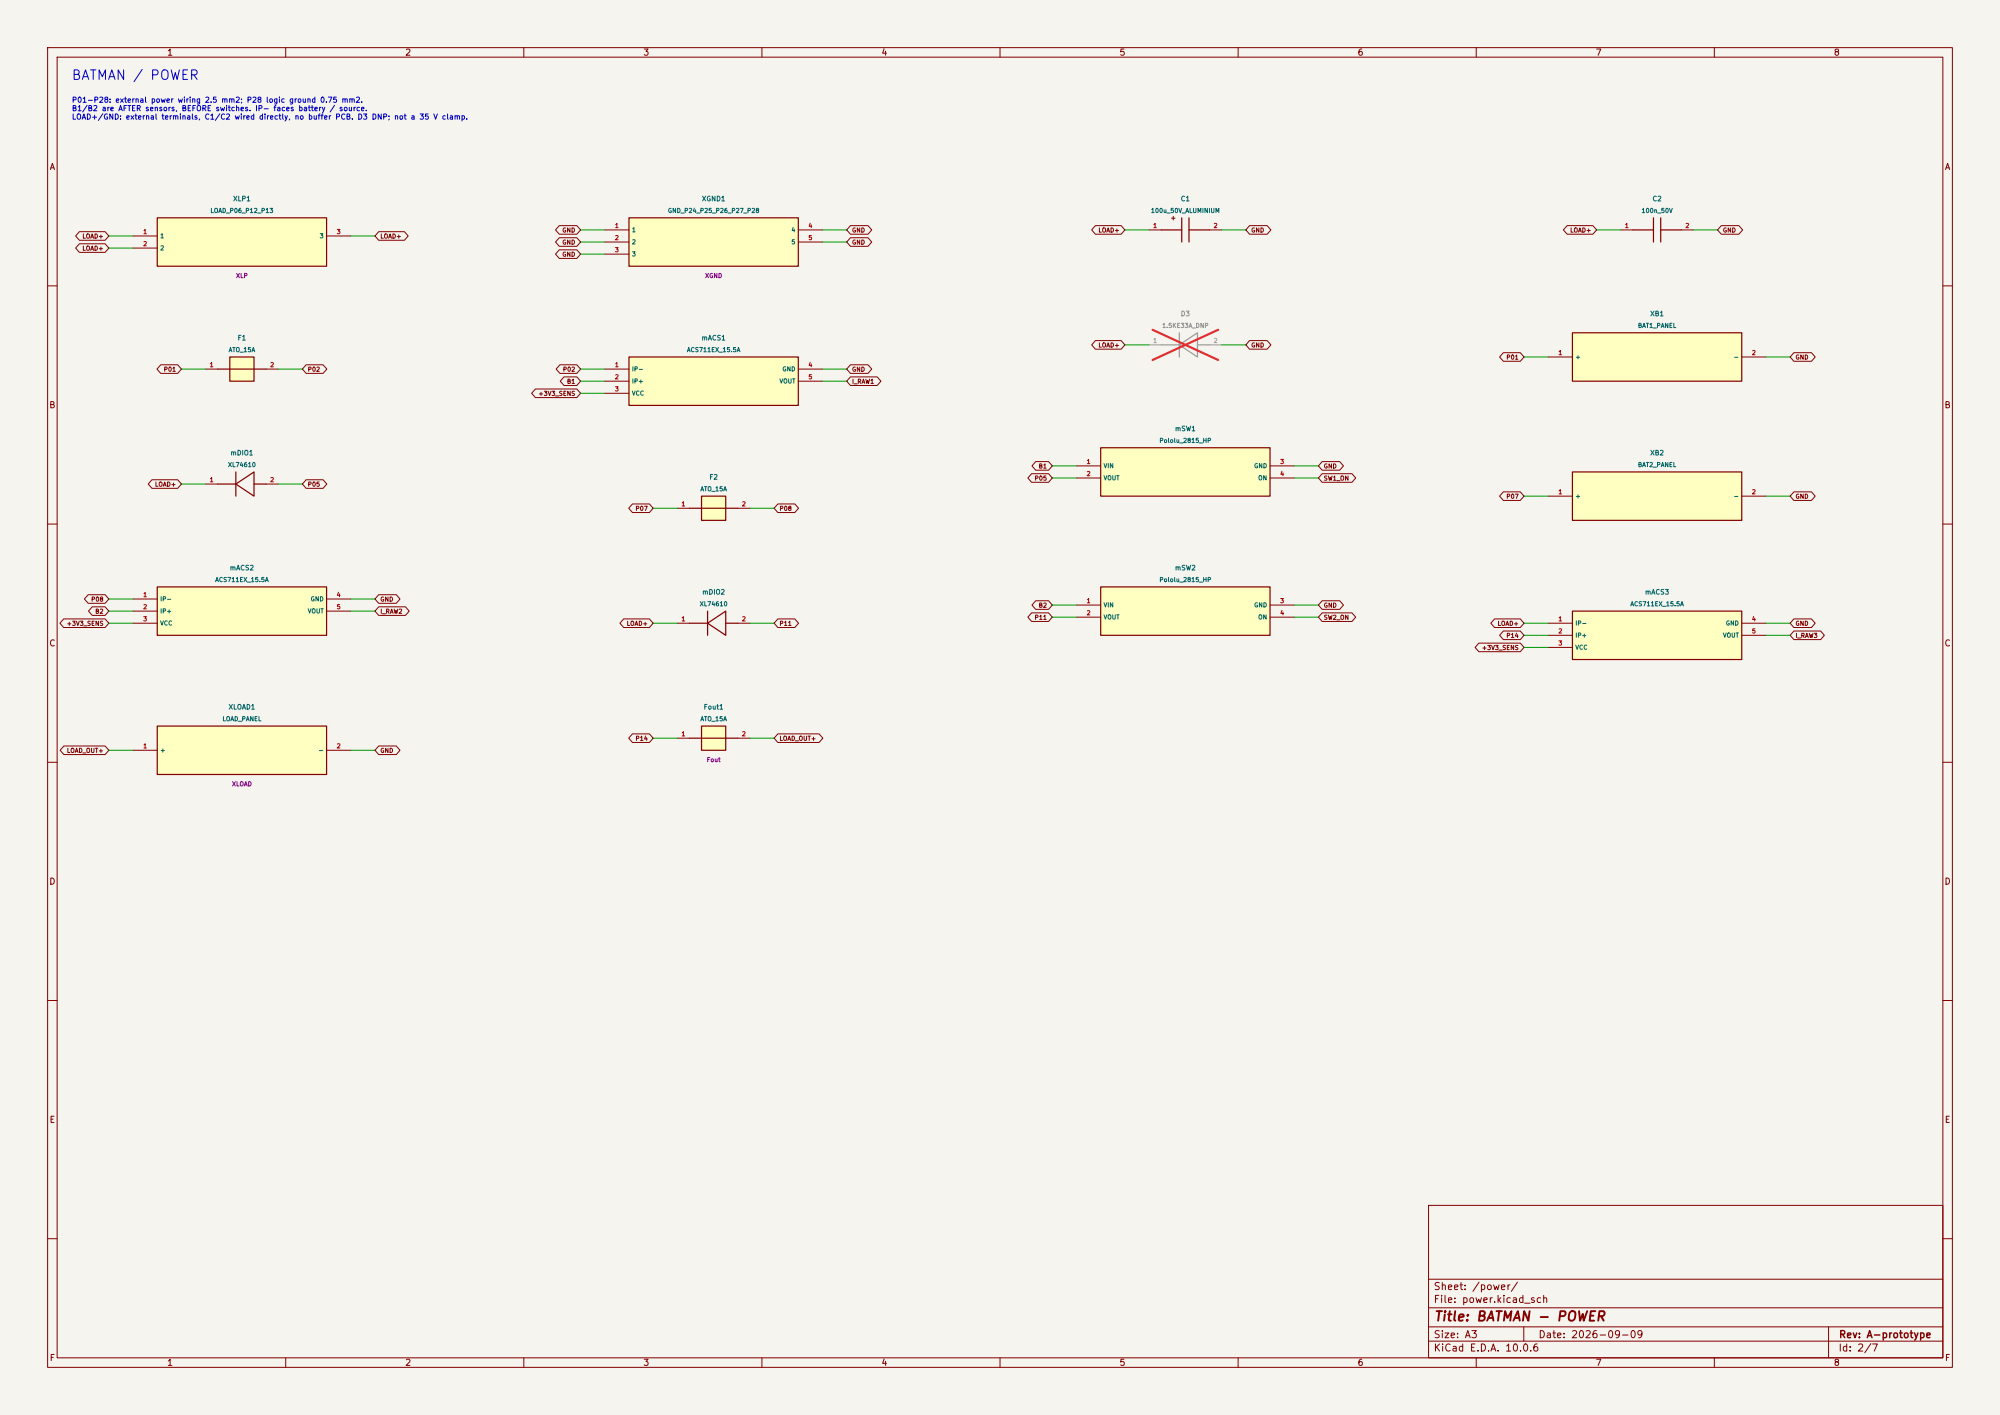
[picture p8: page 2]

P01-P28: external power wiring 2.5 mm2; P28 logic ground 0.75 mm2. B1/B2 are AFTER sensors, BEFORE switches. IP- faces battery / source. LOAD+/GND: external terminals, C1/C2 wired directly, no buffer PCB. D3 DNP; not a 35 V clamp.

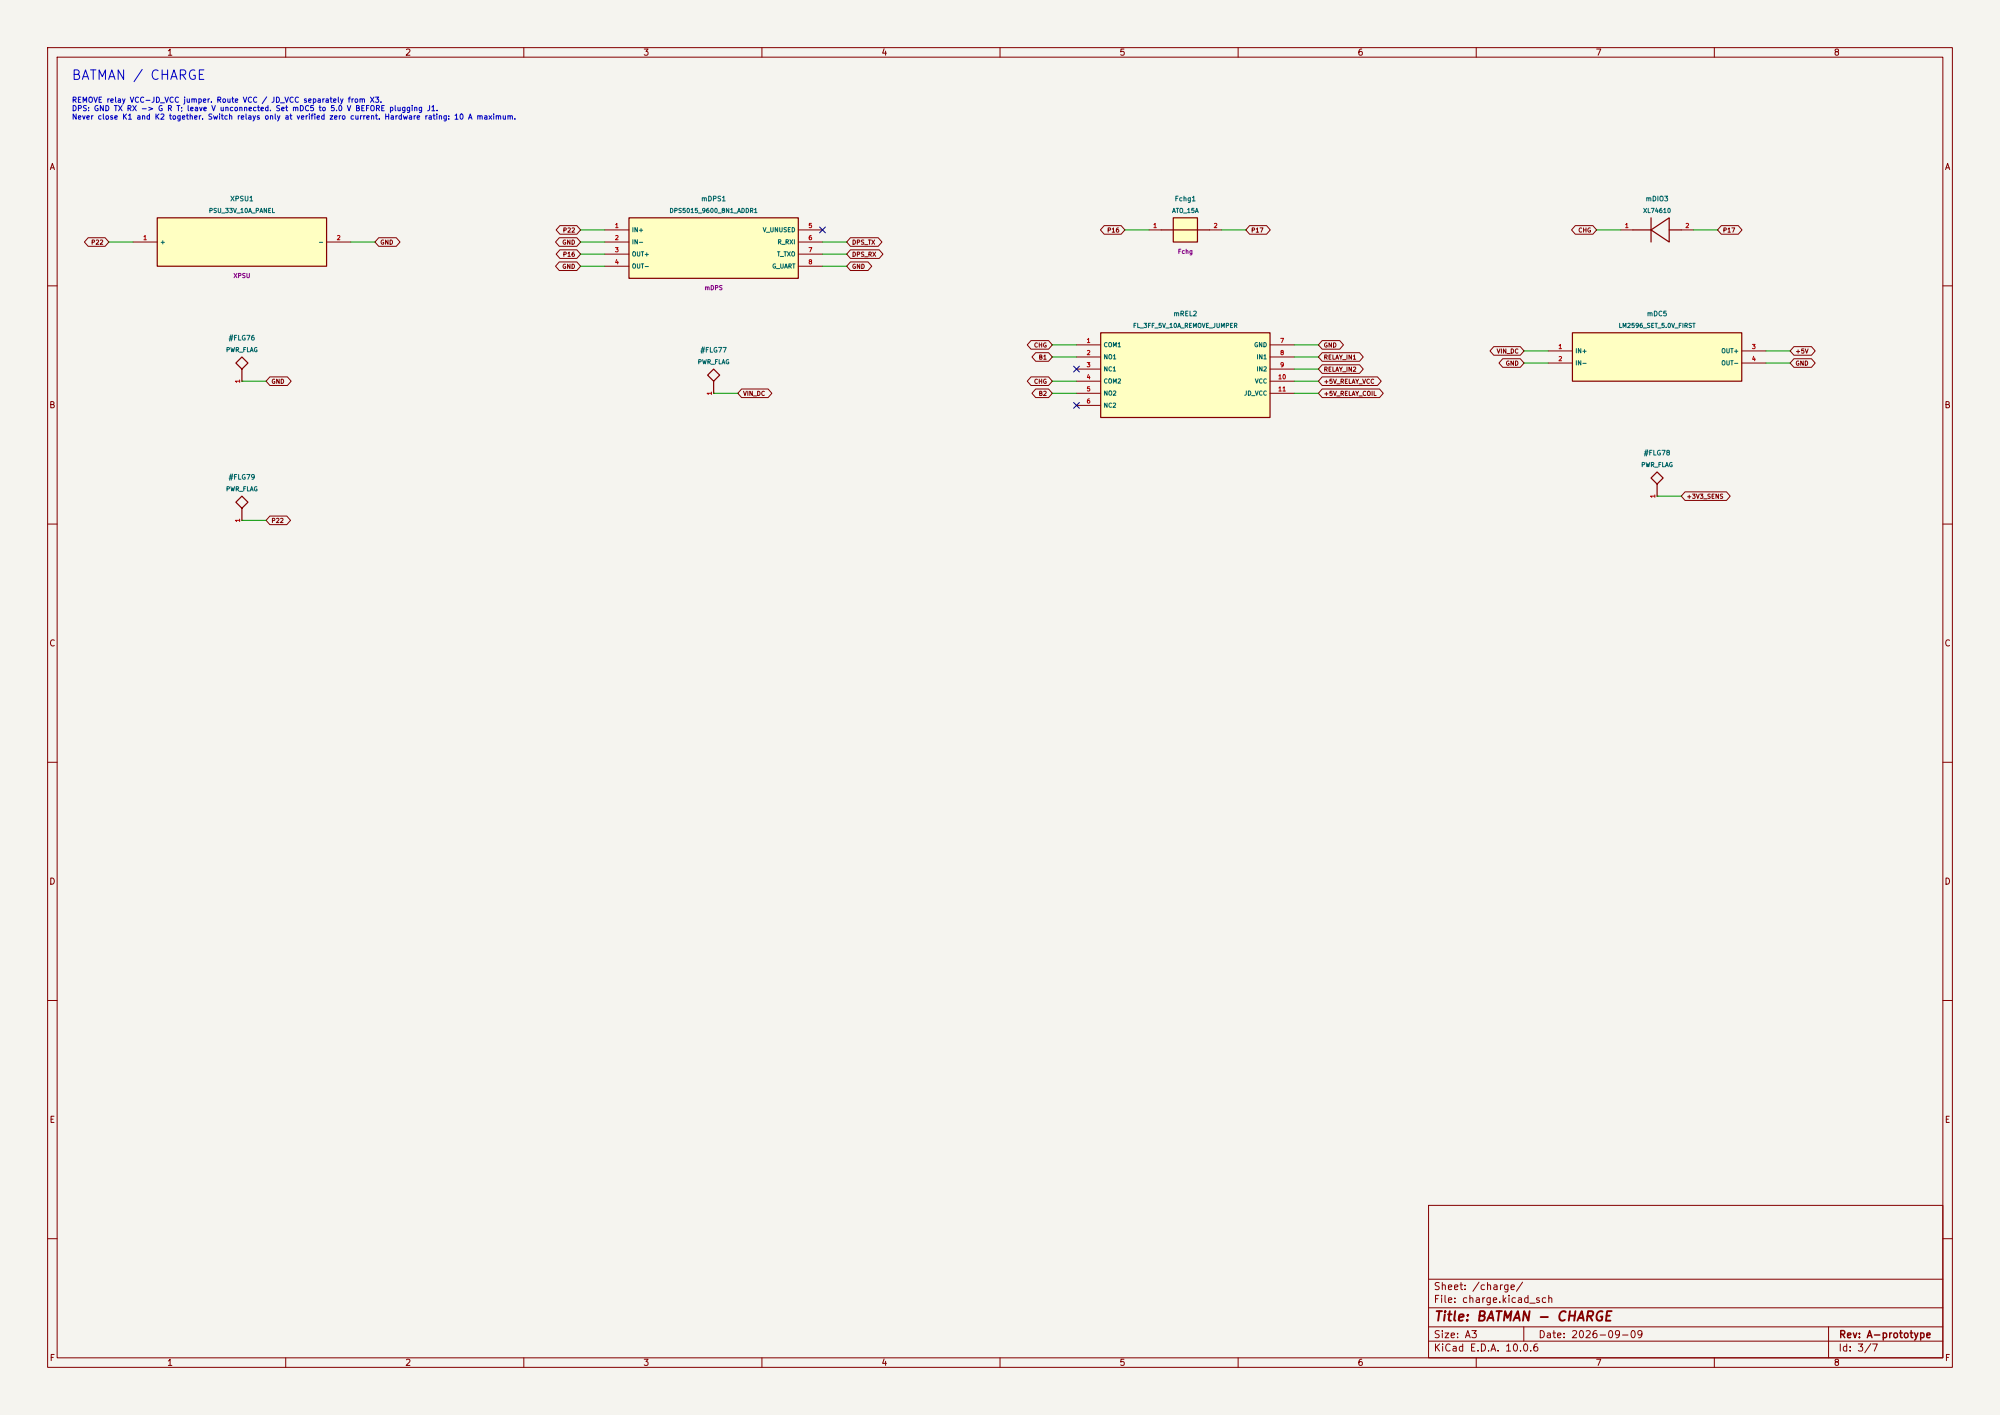
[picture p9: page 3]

REMOVE relay VCC-JD_VCC jumper. Route VCC / JD_VCC separately from X3. DPS: GND TX RX -> G R T; leave V unconnected. Set mDC5 to 5.0 V BEFORE plugging J1. Never close K1 and K2 together. Switch relays only at verified zero current. Hardware rating: 10 A maximum.

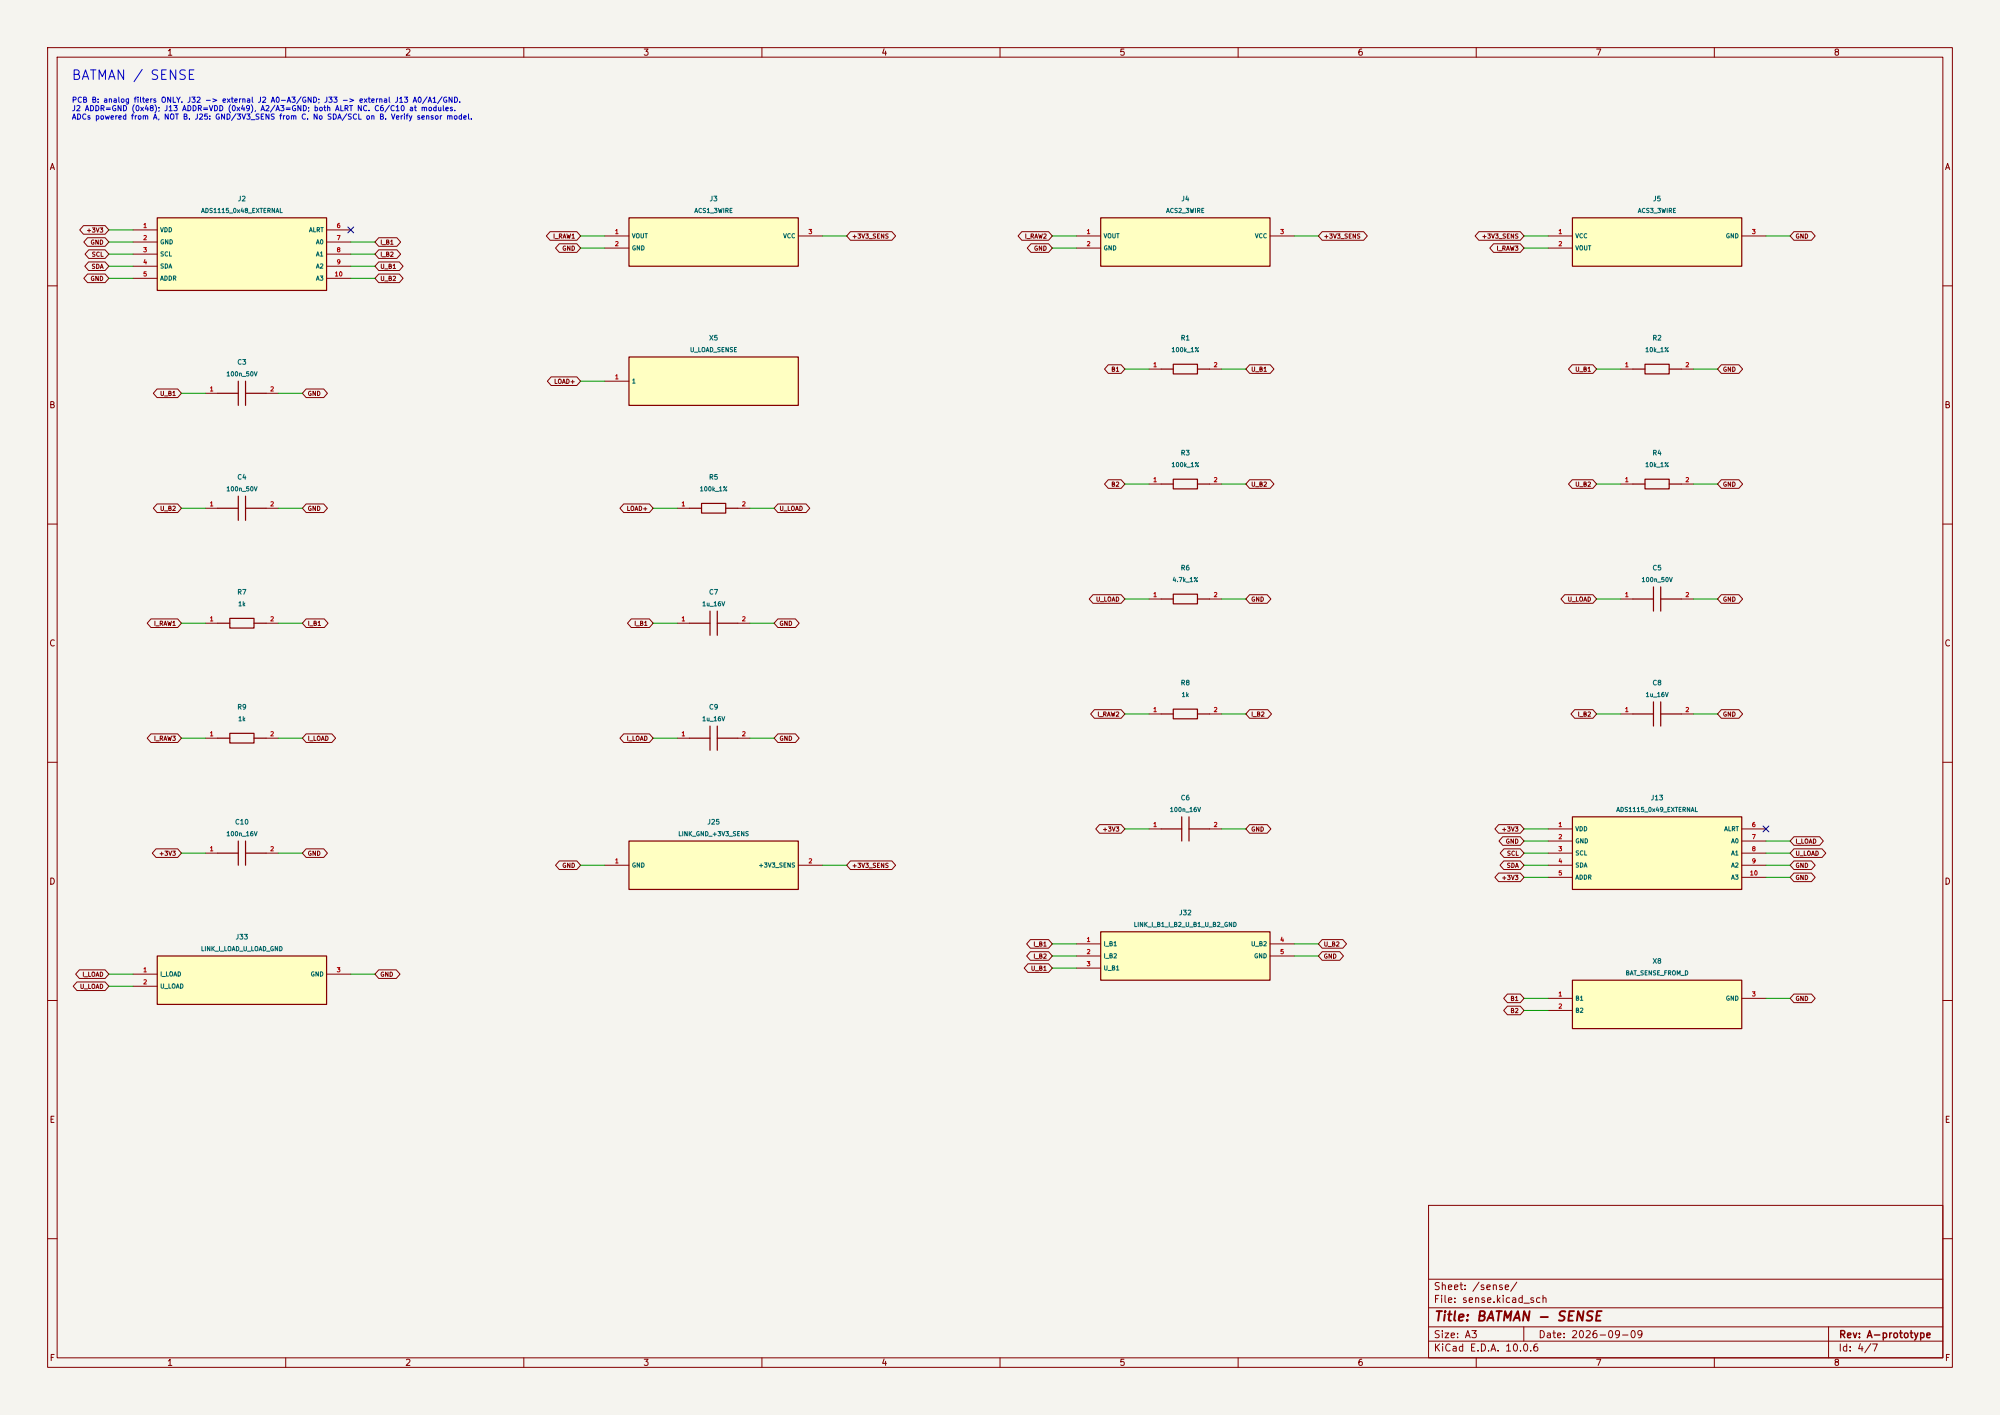
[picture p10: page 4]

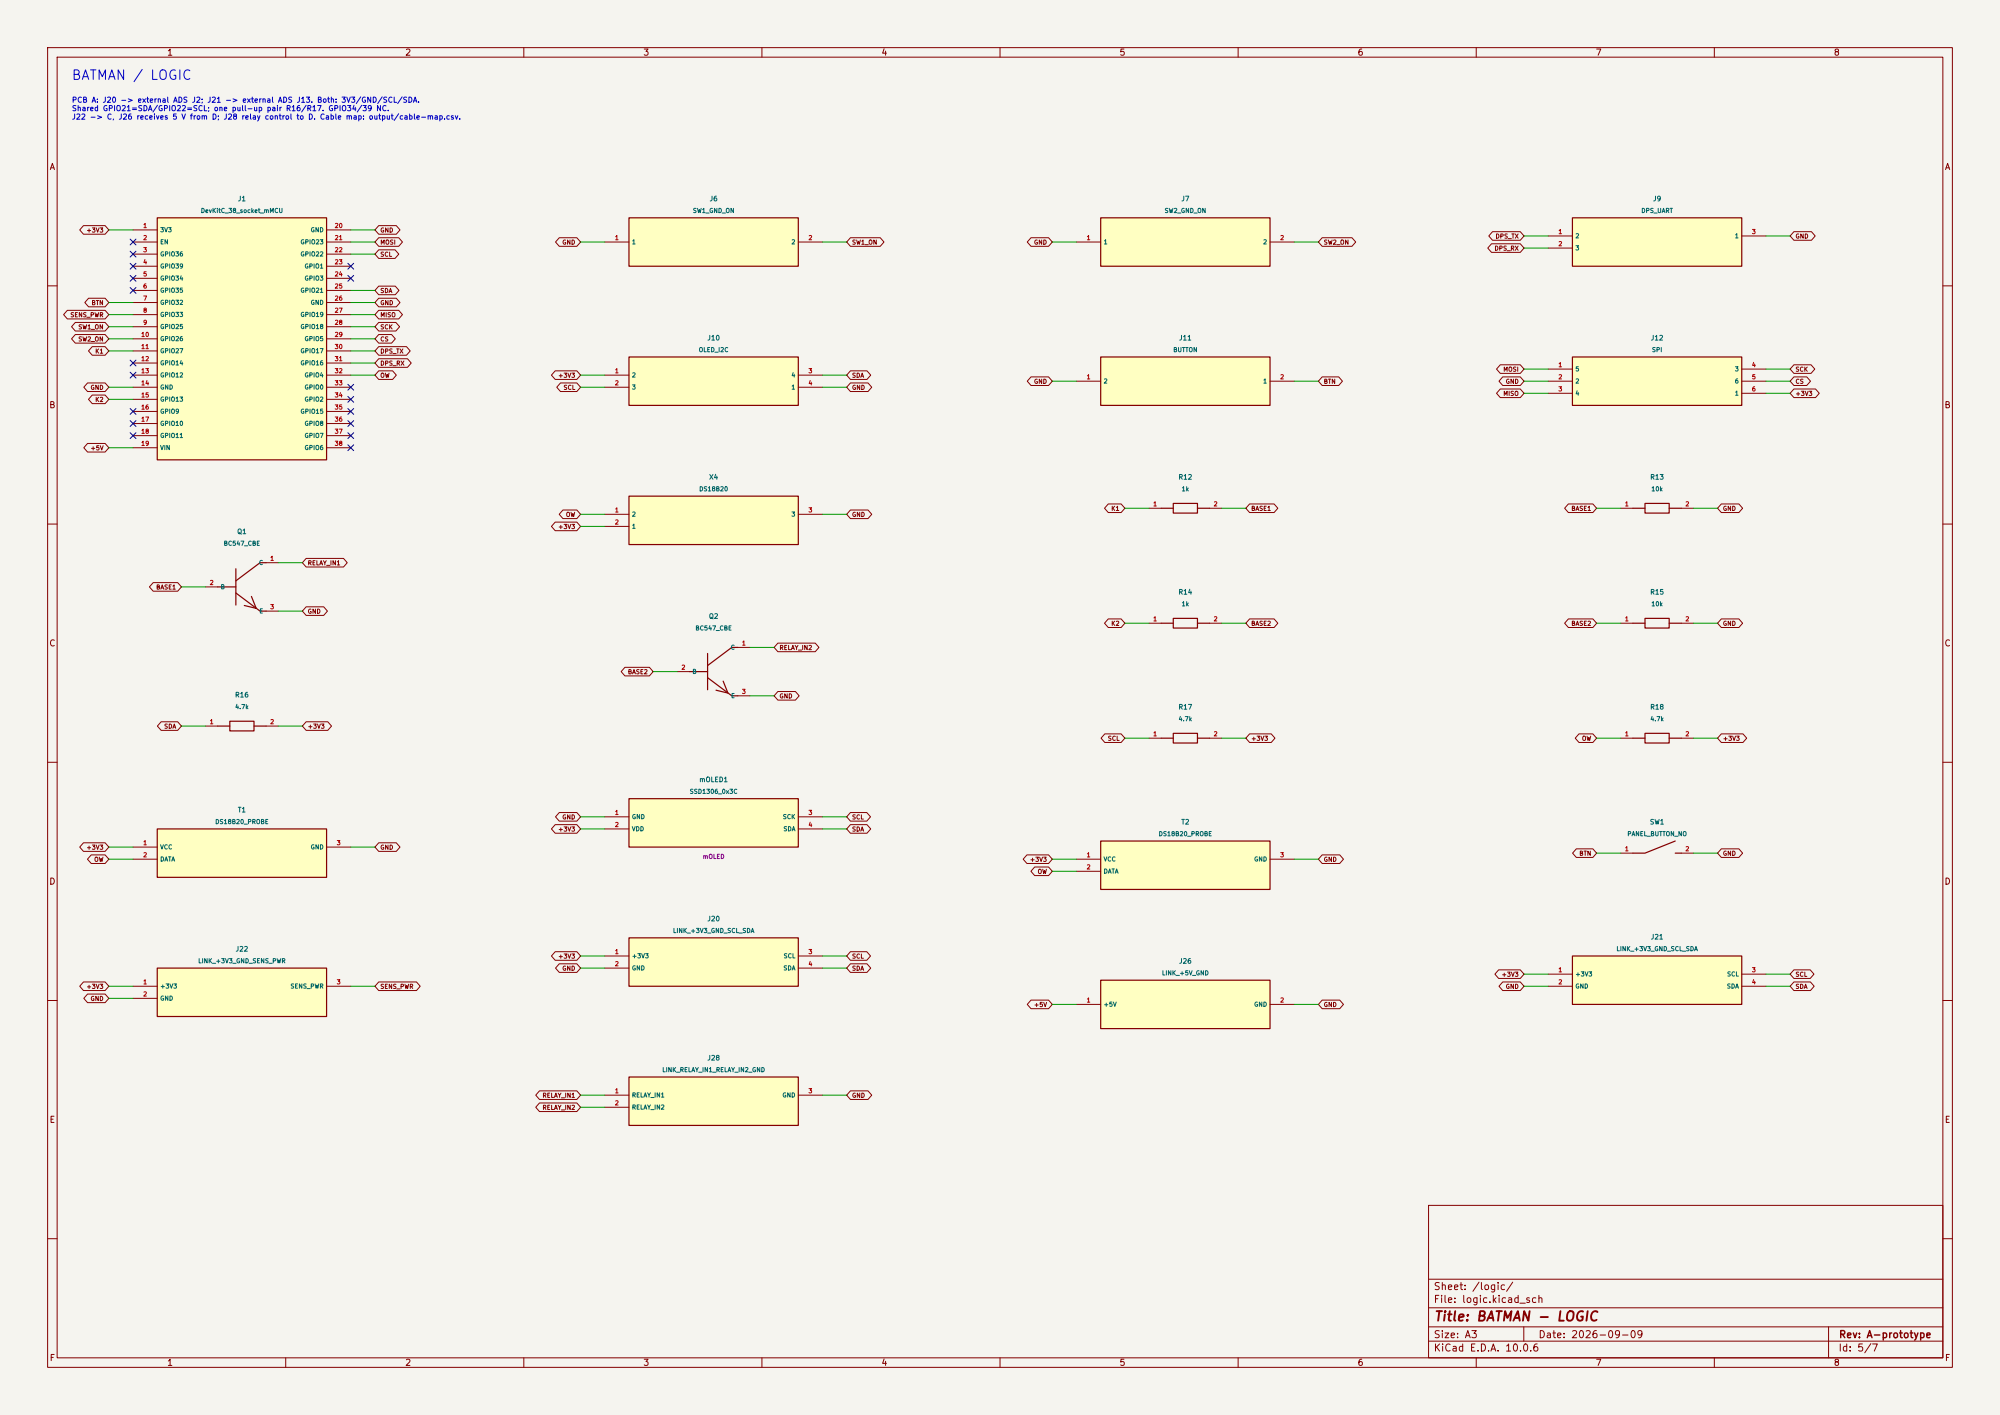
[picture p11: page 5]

PCB A: J20 -> external ADS J2; J21 -> external ADS J13. Both: 3V3/GND/SCL/SDA. Shared GPIO21=SDA/GPIO22=SCL; one pull-up pair R16/R17. GPIO34/39 NC. J22 -> C, J26 receives 5 V from D; J28 relay control to D. Cable map: output/cable-map.csv.

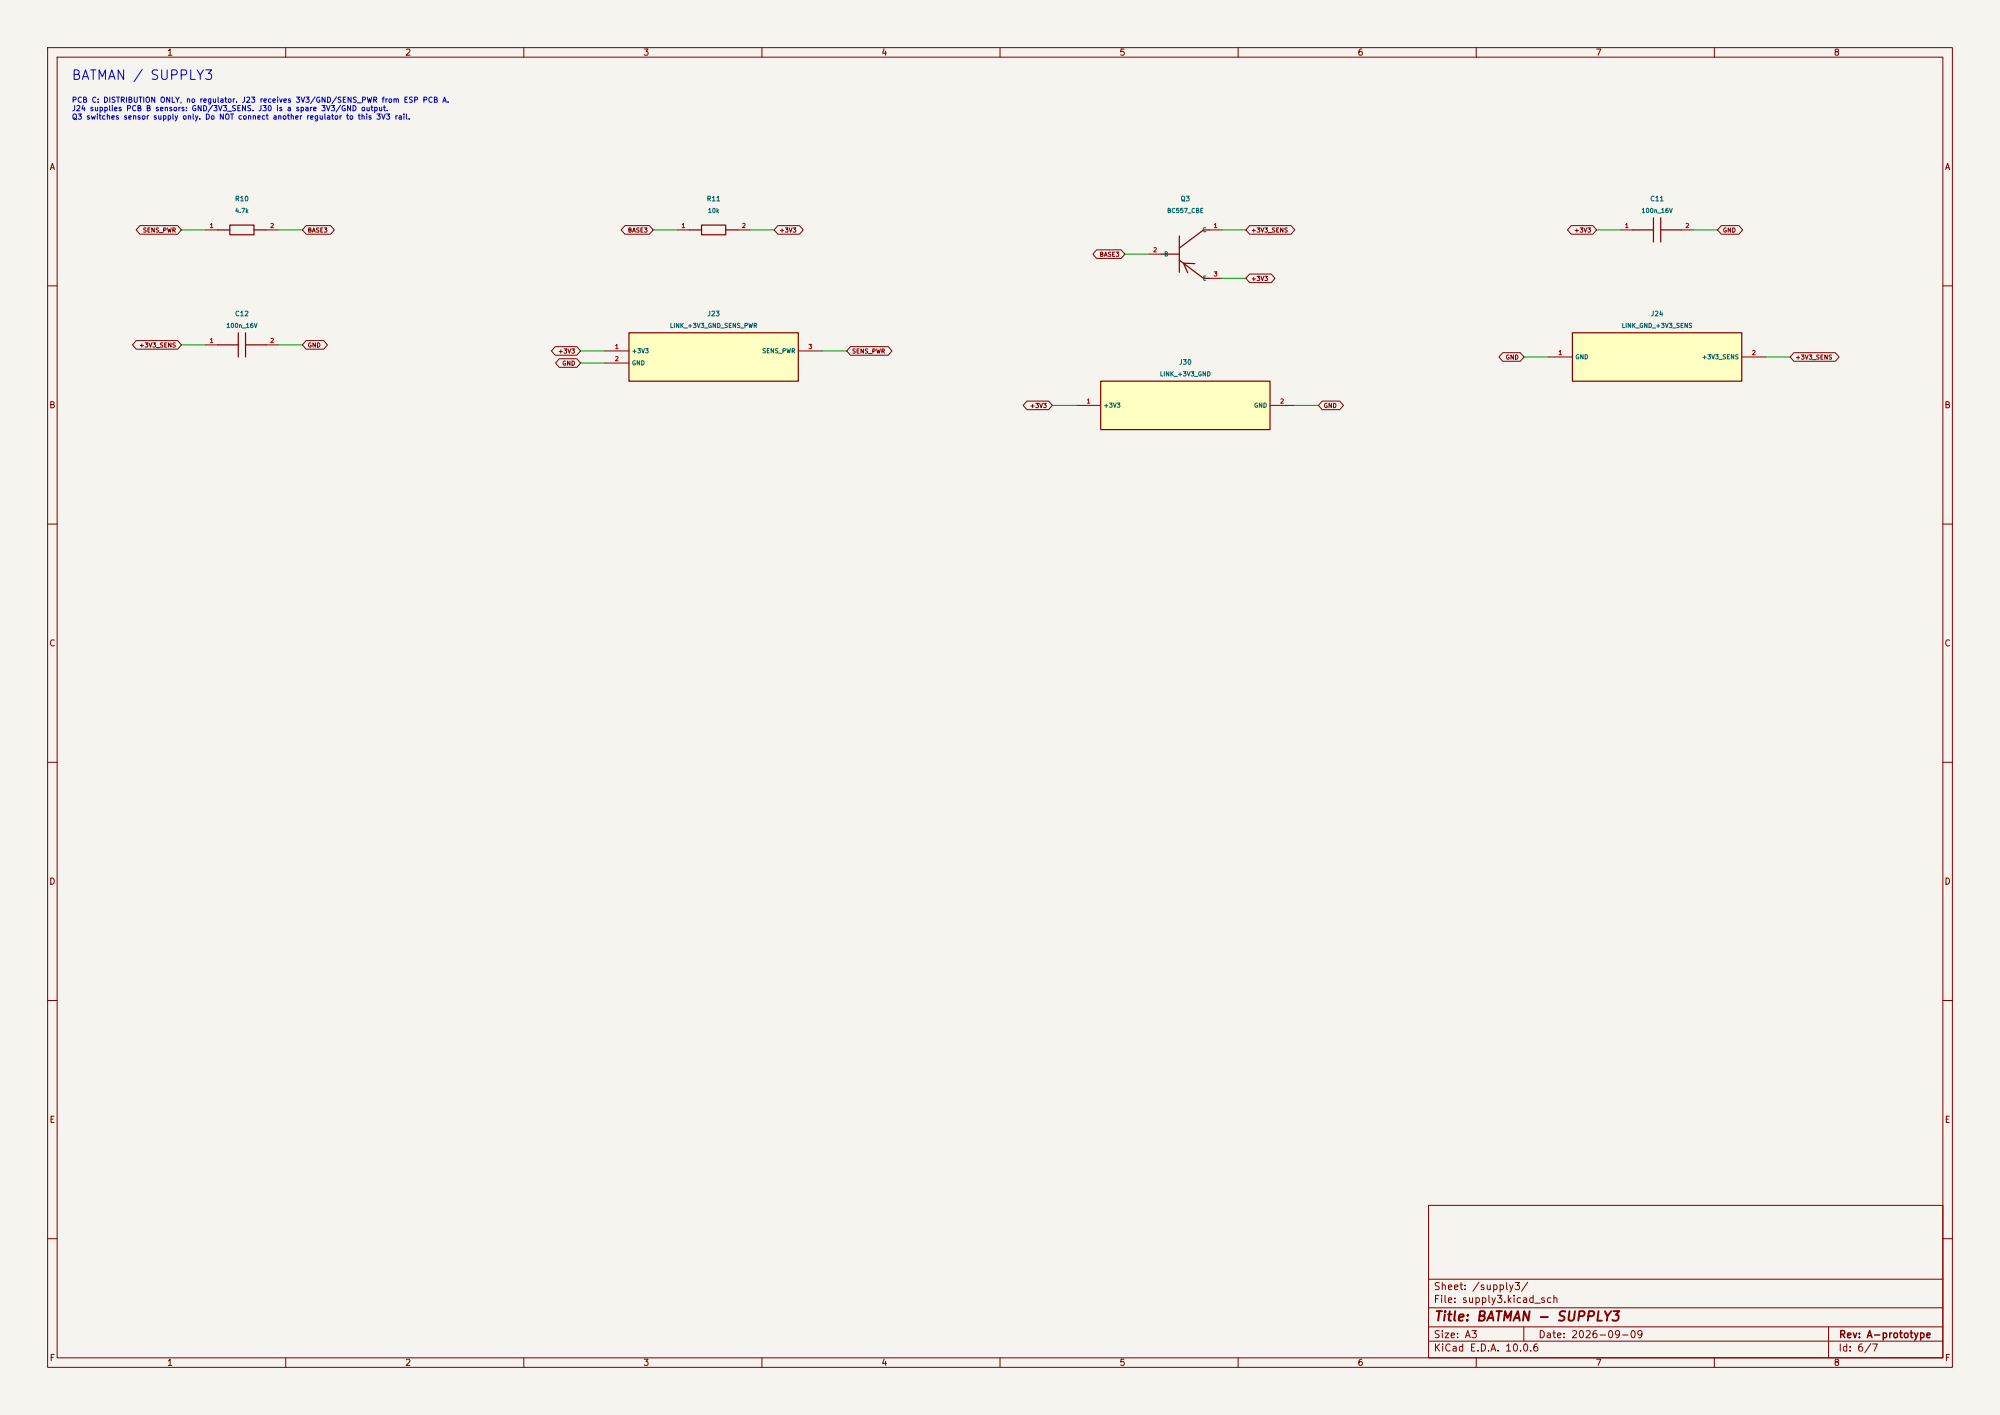
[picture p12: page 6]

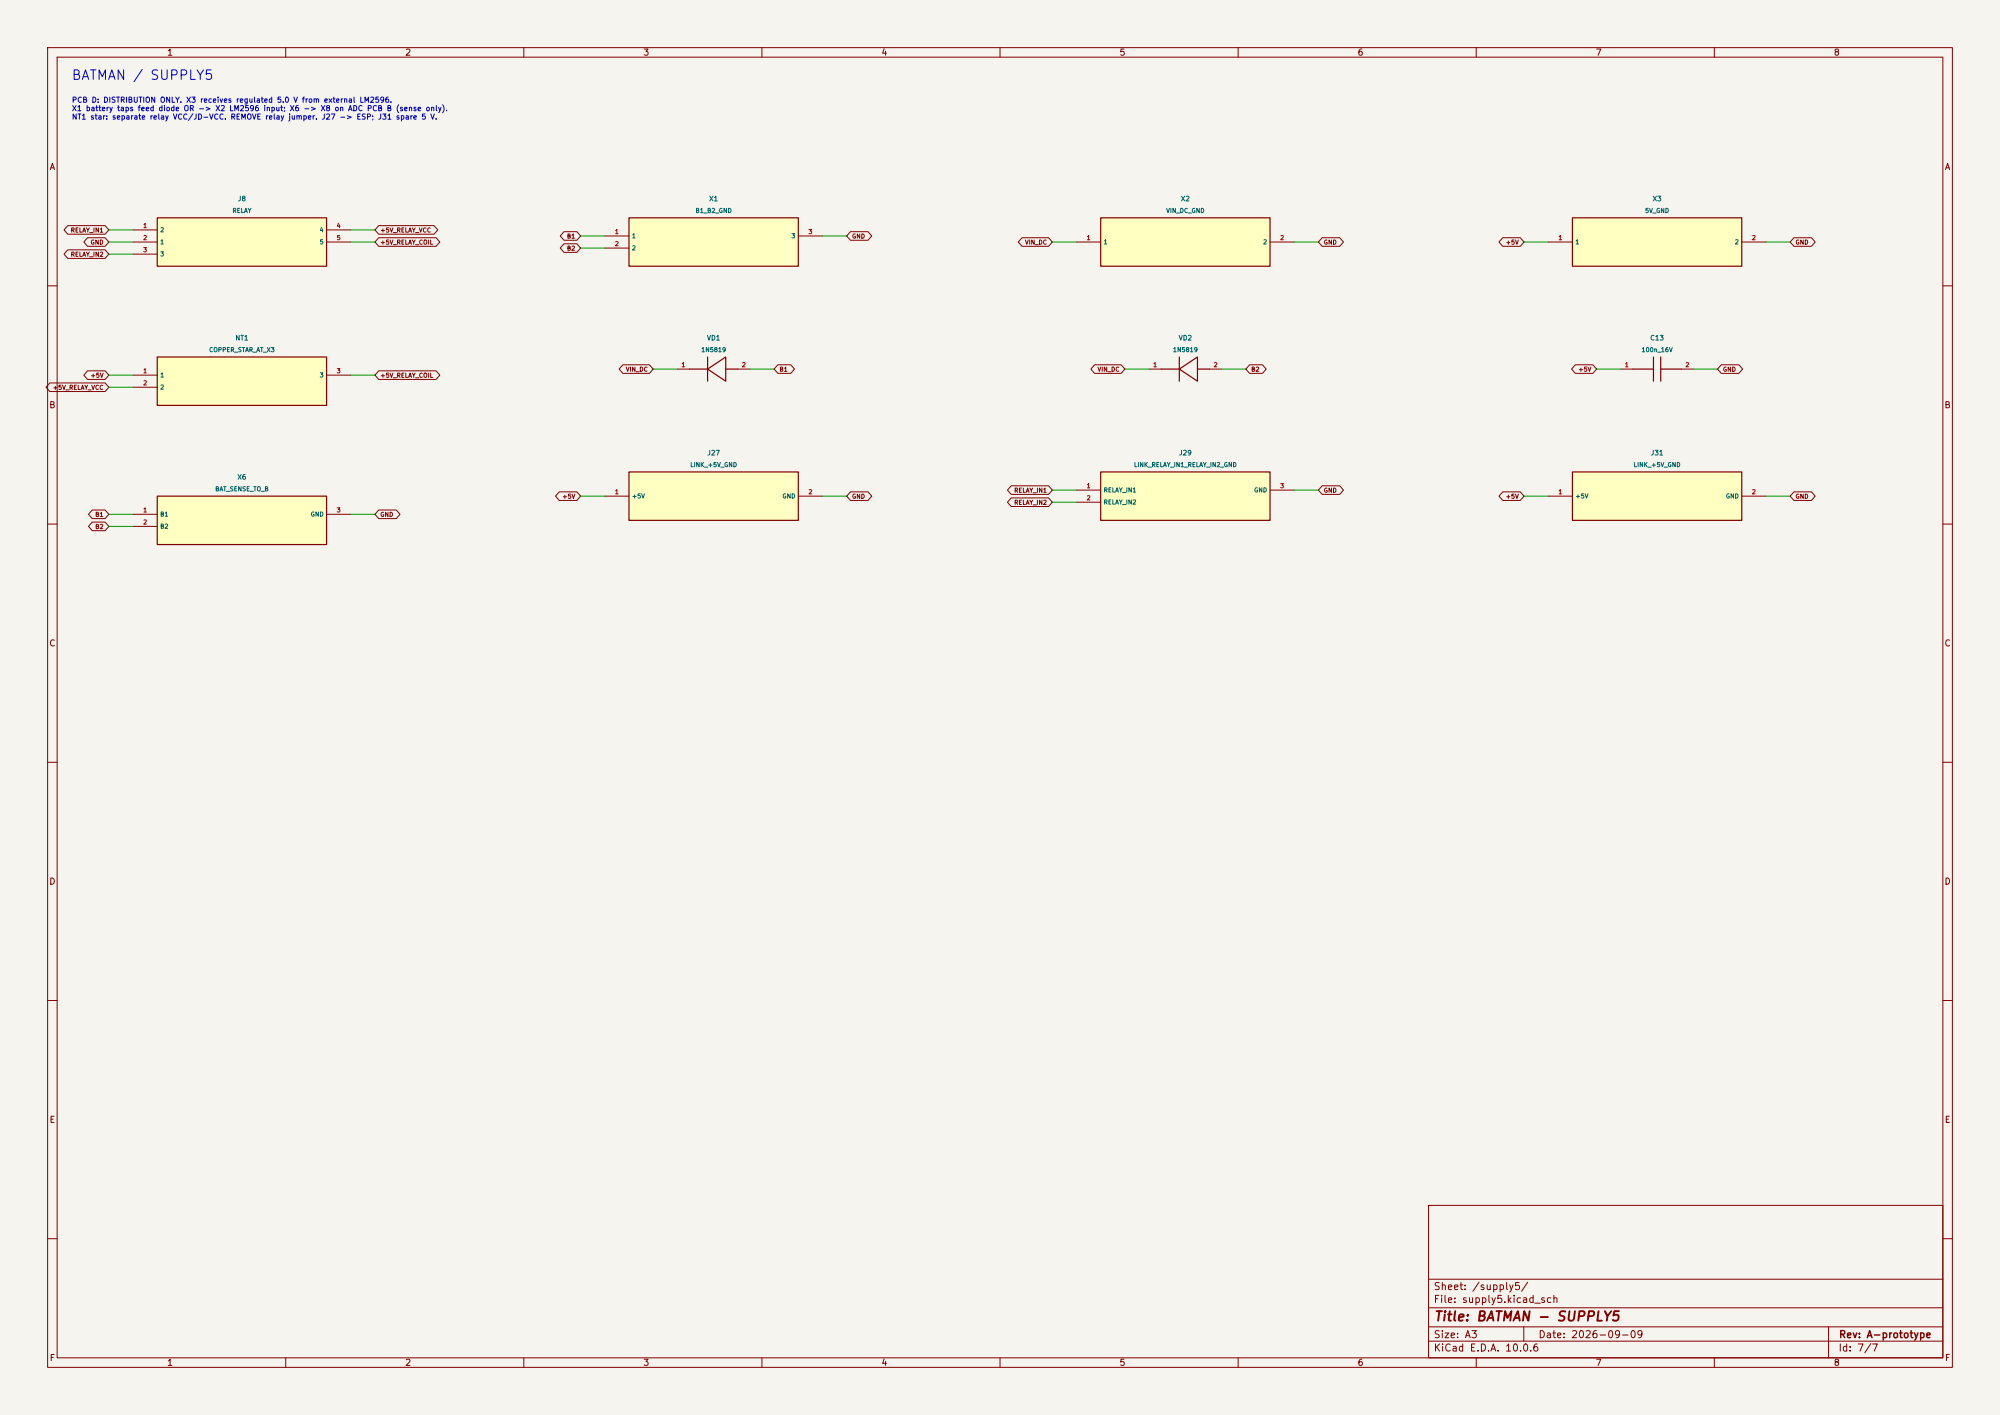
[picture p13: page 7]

PCB D: DISTRIBUTION ONLY. X3 receives regulated 5.0 V from external LM2596. X1 battery taps feed diode OR -> X2 LM2596 input; X6 -> X8 on ADC PCB B (sense only). NT1 star: separate relay VCC/JD-VCC. REMOVE relay jumper. J27 -> ESP; J31 spare 5 V. BATMAN / SUPPLY5

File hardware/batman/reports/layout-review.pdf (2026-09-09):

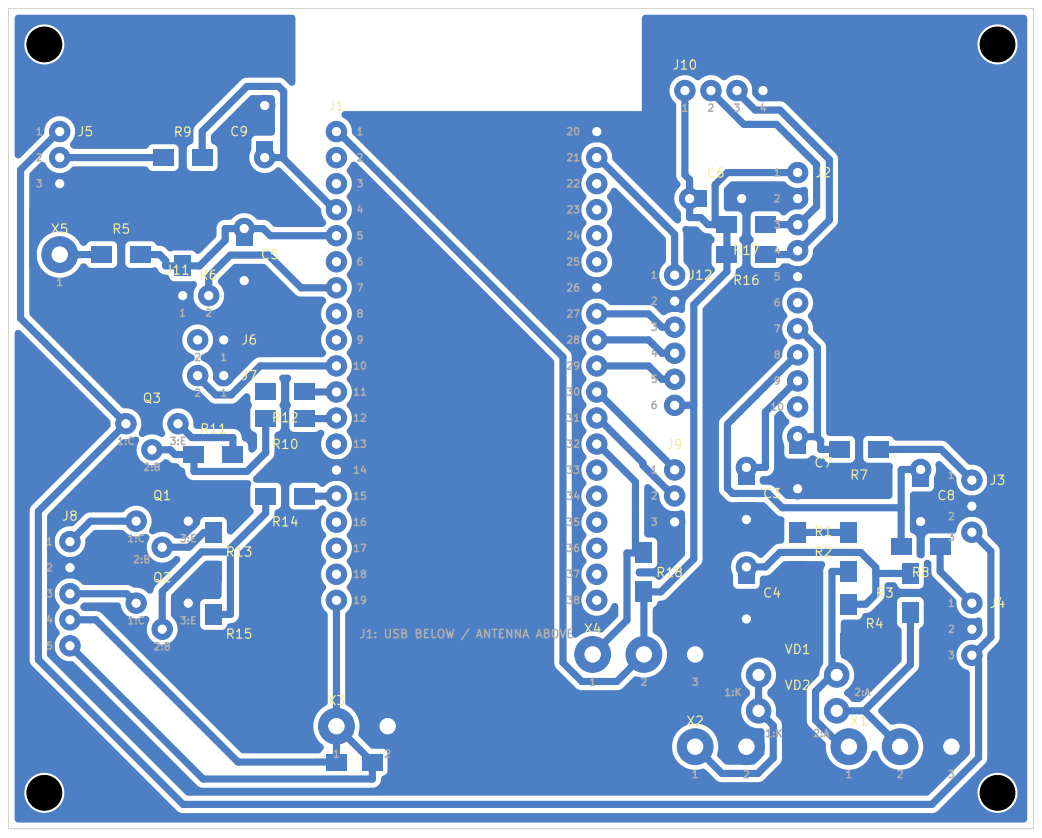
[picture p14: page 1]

J1: USB BELOW / ANTENNA ABOVE

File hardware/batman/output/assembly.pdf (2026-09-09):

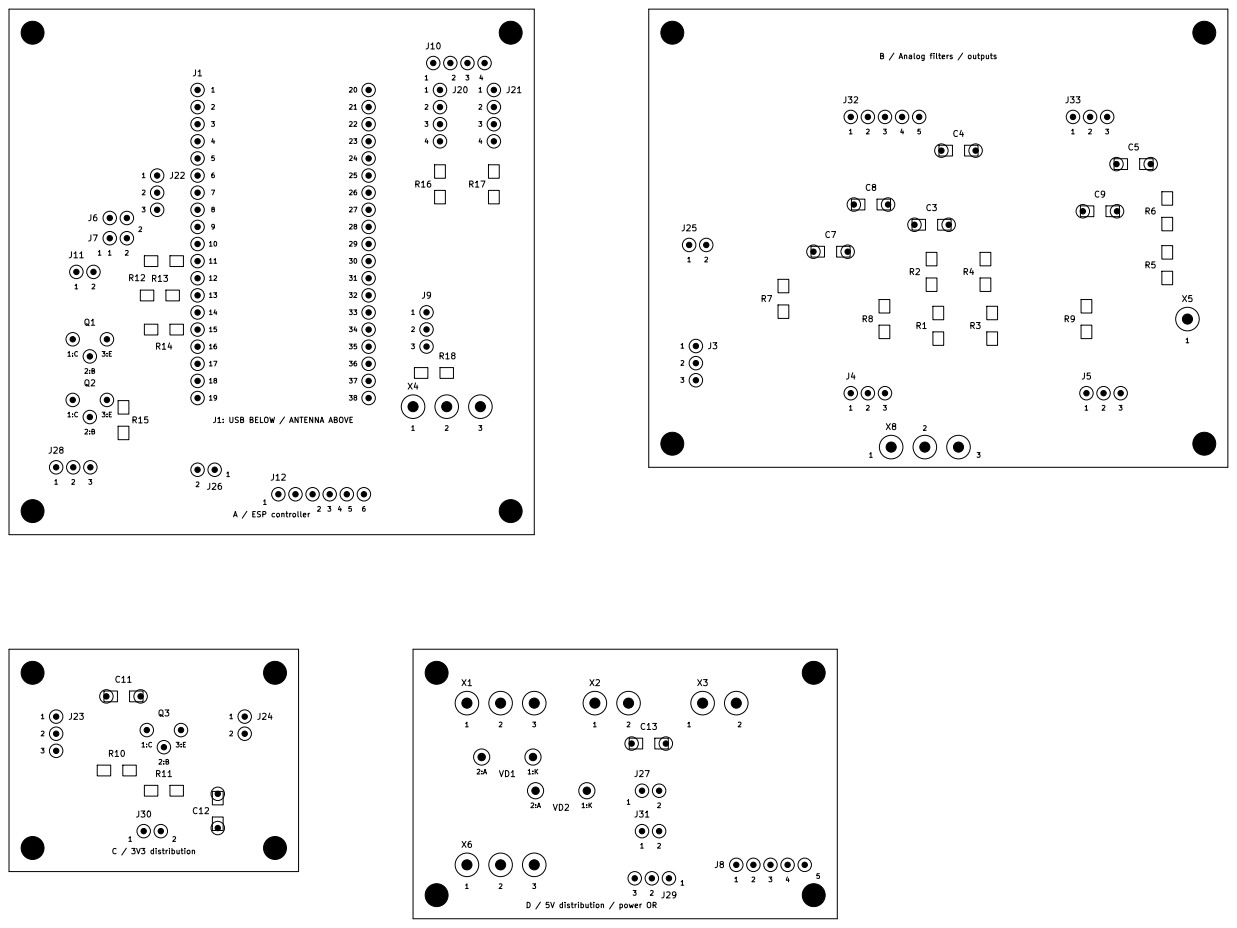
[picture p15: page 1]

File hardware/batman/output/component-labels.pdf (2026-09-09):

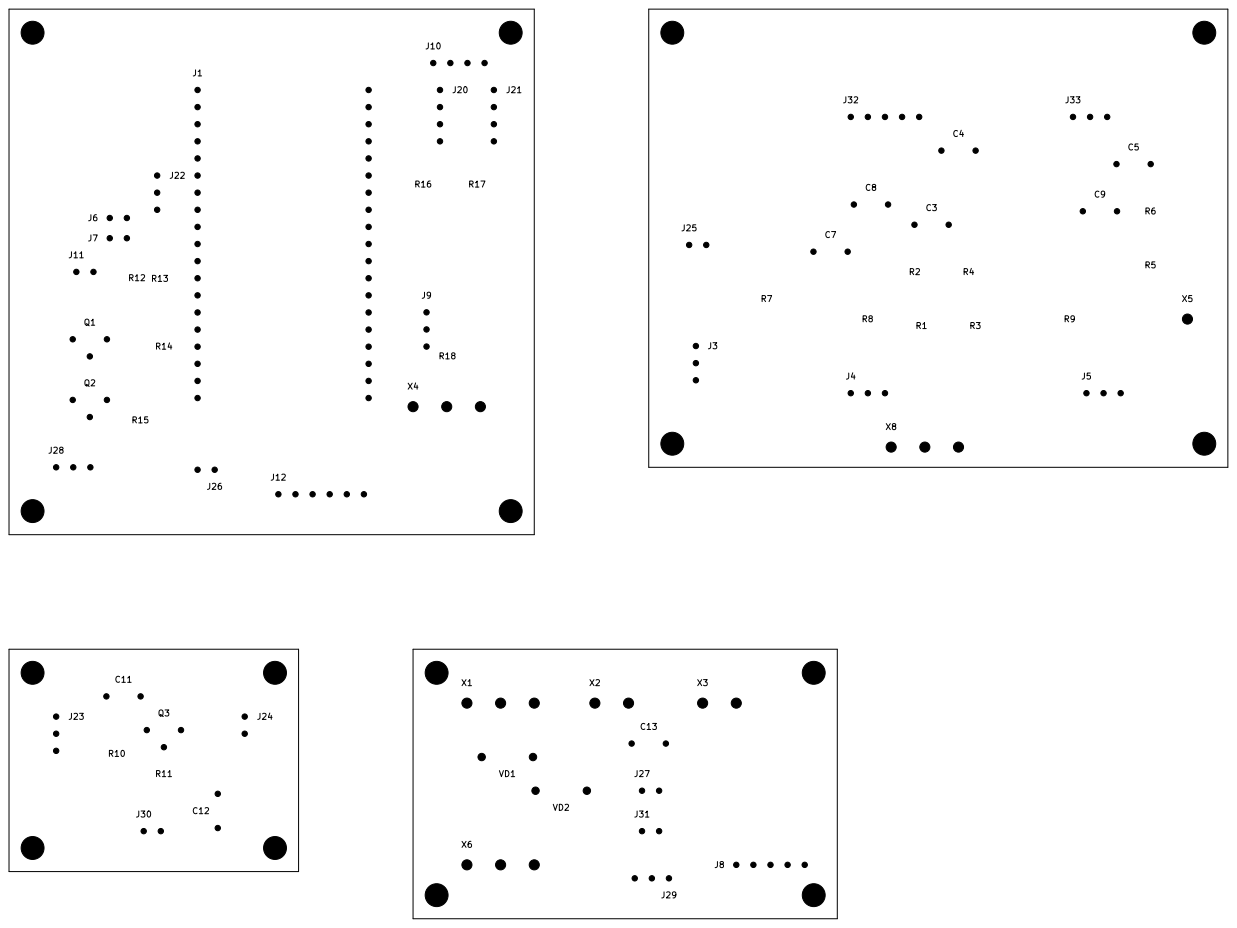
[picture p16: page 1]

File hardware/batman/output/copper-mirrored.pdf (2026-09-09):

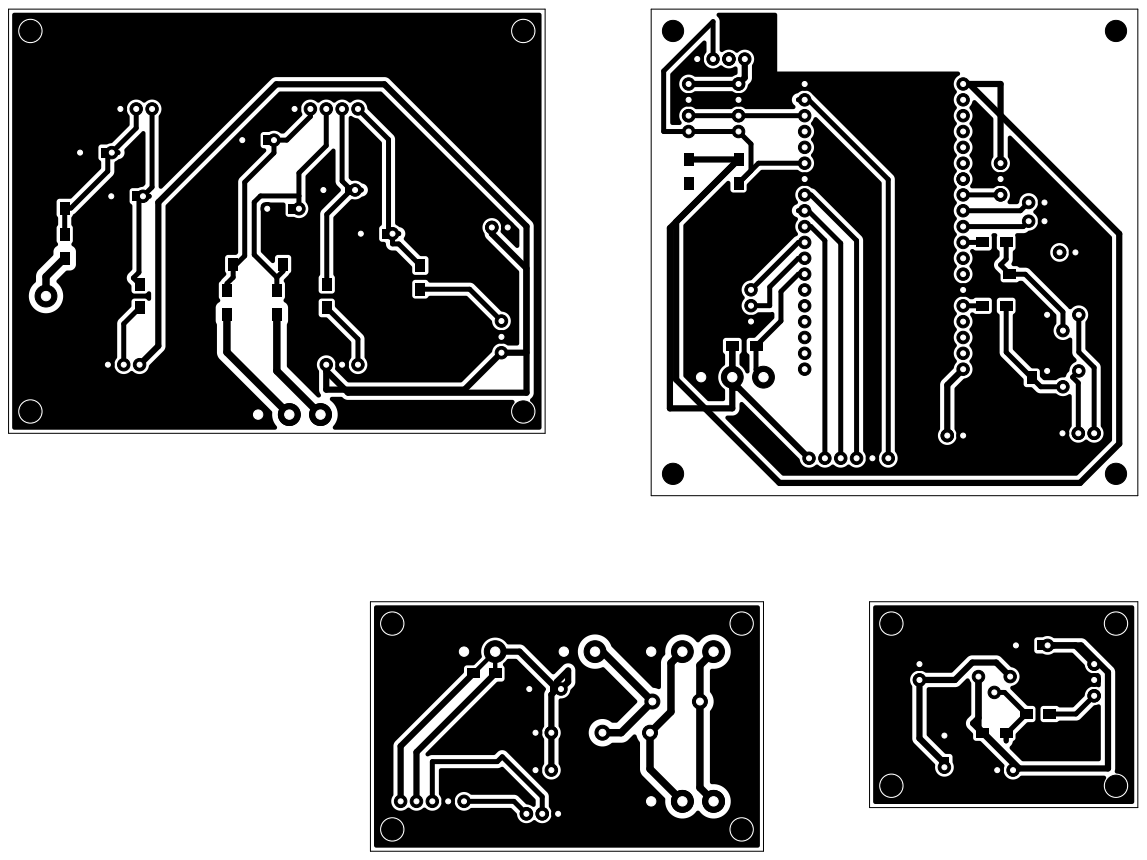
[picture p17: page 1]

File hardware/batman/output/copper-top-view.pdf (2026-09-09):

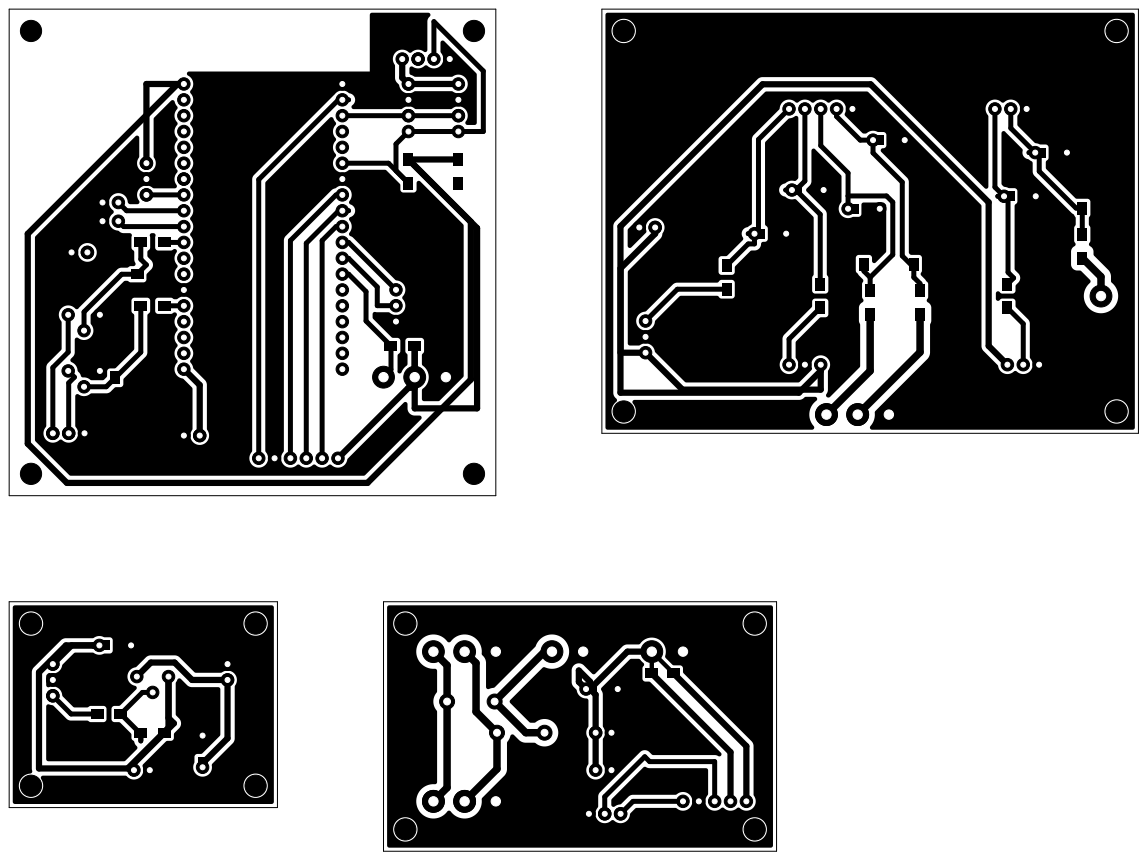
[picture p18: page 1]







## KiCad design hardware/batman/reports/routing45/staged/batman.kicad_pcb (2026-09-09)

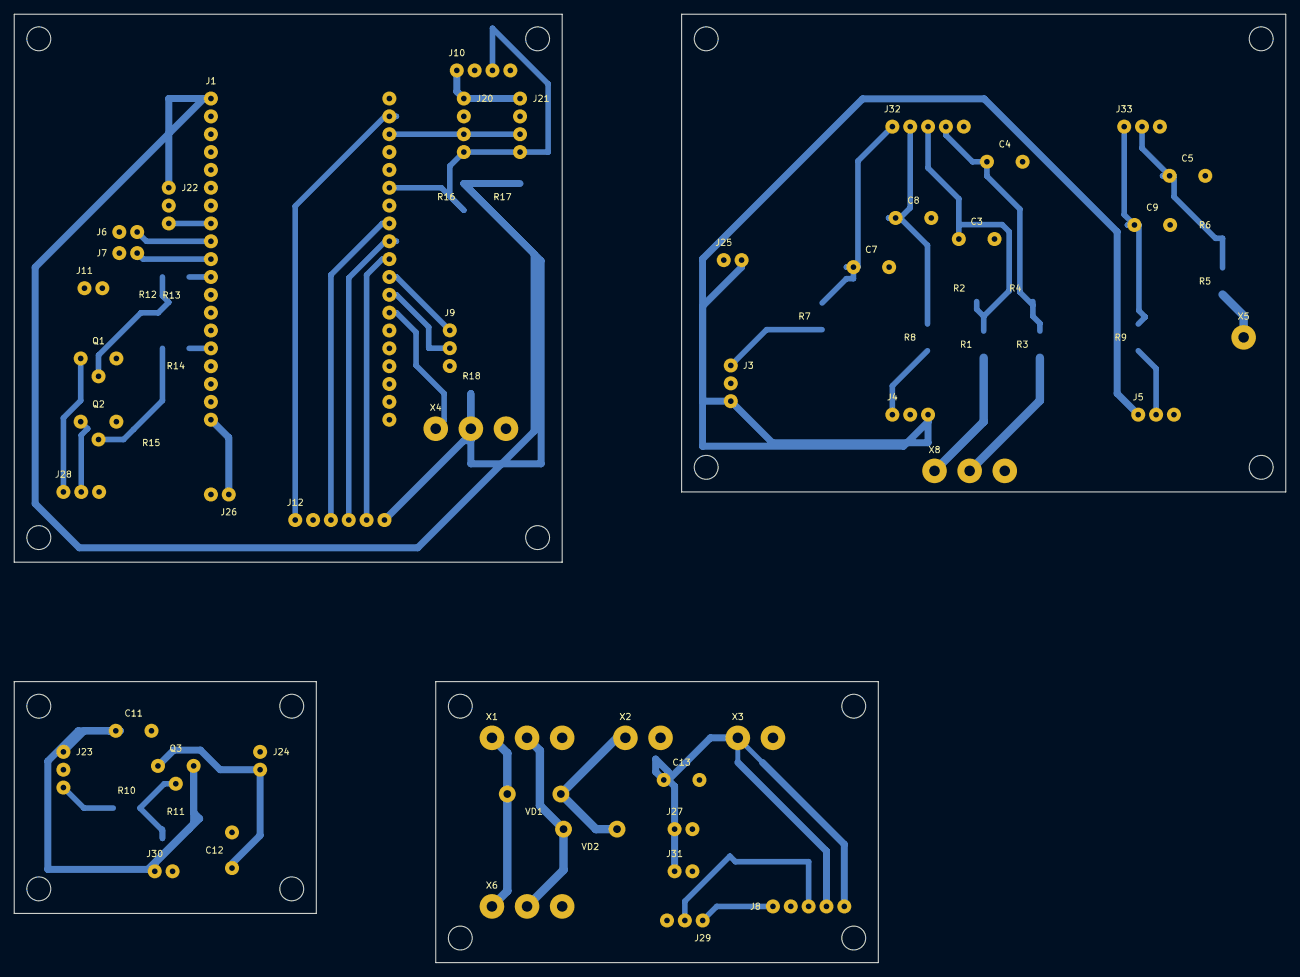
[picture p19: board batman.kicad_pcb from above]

Board: 2 copper layers, 181.0 x 135.0 mm, 98 parts (0 on the bottom side), 39 nets.

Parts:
C3: 100n_50V; LUT_C3
C4: 100n_50V; LUT_C4
C5: 100n_50V; LUT_C5
C7: 1u_16V; LUT_C7
C8: 1u_16V; LUT_C8
C9: 1u_16V; LUT_C9
C11: 100n_16V; LUT_C11
C12: 100n_16V; LUT_C12
C13: 100n_16V; LUT_C13
HA1, HA2, HA3, HA4: M3_NPTH_3.4; Mount_M3
HB1, HB2, HB3, HB4: M3_NPTH_3.4; Mount_M3
HC1, HC2, HC3, HC4: M3_NPTH_3.4; Mount_M3
HD1, HD2, HD3, HD4: M3_NPTH_3.4; Mount_M3
J1: DevKitC_38_socket_mMCU; LUT_J1
J3: ACS1_3WIRE; LUT_J3
J4: ACS2_3WIRE; LUT_J4
J5: ACS3_3WIRE; LUT_J5
J6: SW1_GND_ON; LUT_J6
J7: SW2_GND_ON; LUT_J7
J8: RELAY; LUT_J8
J9: DPS_UART; LUT_J9
J10: OLED_I2C; LUT_J10
J11: BUTTON; LUT_J11
J12: SPI; LUT_J12
J20: LINK_+3V3_GND_SCL_SDA; LUT_J20
J21: LINK_+3V3_GND_SCL_SDA; LUT_J21
J22: LINK_+3V3_GND_SENS_PWR; LUT_J22
J23: LINK_+3V3_GND_SENS_PWR; LUT_J23
J24: LINK_GND_+3V3_SENS; LUT_J24
J25: LINK_GND_+3V3_SENS; LUT_J25
J26: LINK_+5V_GND; LUT_J26
J27: LINK_+5V_GND; LUT_J27
J28: LINK_RELAY_IN1_RELAY_IN2_GND; LUT_J28
J29: LINK_RELAY_IN1_RELAY_IN2_GND; LUT_J29
J30: LINK_+3V3_GND; LUT_J30
J31: LINK_+5V_GND; LUT_J31
J32: LINK_I_B1_I_B2_U_B1_U_B2_GND; LUT_J32
J33: LINK_I_LOAD_U_LOAD_GND; LUT_J33
NT1: COPPER_STAR_AT_X3; LUT_NT1
Q1: BC547_CBE; LUT_Q1
Q2: BC547_CBE; LUT_Q2
Q3: BC557_CBE; LUT_Q3
R1: 100k_1%; LUT_R1
R2: 10k_1%; LUT_R2
R3: 100k_1%; LUT_R3
R4: 10k_1%; LUT_R4
R5: 100k_1%; LUT_R5
R6: 4.7k_1%; LUT_R6
R7: 1k; LUT_R7
R8: 1k; LUT_R8
R9: 1k; LUT_R9
R10: 4.7k; LUT_R10
R11: 10k; LUT_R11
R12: 1k; LUT_R12
R13: 10k; LUT_R13
R14: 1k; LUT_R14
R15: 10k; LUT_R15
R16: 4.7k; LUT_R16
R17: 4.7k; LUT_R17
R18: 4.7k; LUT_R18
VD1: 1N5819; LUT_VD1
VD2: 1N5819; LUT_VD2
WA1: INSULATED_WIRE; LUT_WA1
WA2: INSULATED_WIRE; LUT_WA2
WA3: INSULATED_WIRE; LUT_WA3
WA4: INSULATED_WIRE; LUT_WA4
WC2_1: EXTERNAL_CABLE_NOT_PCB; LUT_WC2_1
WC2_2: EXTERNAL_CABLE_NOT_PCB; LUT_WC2_2
WC2_3: EXTERNAL_CABLE_NOT_PCB; LUT_WC2_3
WC3_1: EXTERNAL_CABLE_NOT_PCB; LUT_WC3_1
WC3_2: EXTERNAL_CABLE_NOT_PCB; LUT_WC3_2
WC4_1: EXTERNAL_CABLE_NOT_PCB; LUT_WC4_1
WC4_2: EXTERNAL_CABLE_NOT_PCB; LUT_WC4_2
WC5_1: EXTERNAL_CABLE_NOT_PCB; LUT_WC5_1
WC5_2: EXTERNAL_CABLE_NOT_PCB; LUT_WC5_2
WC5_3: EXTERNAL_CABLE_NOT_PCB; LUT_WC5_3
WC6_1: EXTERNAL_CABLE_NOT_PCB; LUT_WC6_1
WC6_2: EXTERNAL_CABLE_NOT_PCB; LUT_WC6_2
WC6_3: EXTERNAL_CABLE_NOT_PCB; LUT_WC6_3
X1: B1_B2_GND; LUT_X1
X2: VIN_DC_GND; LUT_X2
X3: 5V_GND; LUT_X3
X4: DS18B20; LUT_X4
X5: U_LOAD_SENSE; LUT_X5
X6: BAT_SENSE_TO_B; LUT_X6
X8: BAT_SENSE_FROM_D; LUT_X8

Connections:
+3V3: C11.1, J1.1, J10.1, J12.6, J20.1, J21.1, J22.1, J23.1, J30.1, Q3.3, R11.2, R16.2, R17.2, R18.2, WA1.1, WC2_1.1, X4.2
+3V3_SENS: C12.1, J3.3, J4.3, J5.1, J24.2, J25.2, Q3.1, WC3_2.1
+5V: C13.1, J1.19, J26.1, J27.1, J31.1, NT1.1, WC4_1.1, X3.1
+5V_RELAY_COIL: J8.5, NT1.3
+5V_RELAY_VCC: J8.4, NT1.2
B1: R1.1, VD1.2, WC6_1.1, X1.1, X6.1, X8.1
B2: R3.1, VD2.2, WC6_2.1, X1.2, X6.2, X8.2
BASE1: Q1.2, R12.2, R13.1
BASE2: Q2.2, R14.2, R15.1
BASE3: Q3.2, R10.2, R11.1
BTN: J1.7, J11.2, WA2.1
CS: J1.29, J12.5
DPS_RX: J1.31, J9.2
DPS_TX: J1.30, J9.1
GND: C3.2, C4.2, C5.2, C7.2, C8.2, C9.2, C11.2, C12.2, C13.2, J1.14, J1.20, J1.26, J3.2, J4.2, J5.3, J6.1, J7.1, J8.2, J9.3, J10.4, J11.1, J12.2, J20.2, J21.2, J22.2, J23.2, J24.1, J25.1, J26.2, J27.2, J28.3, J29.3, J30.2, J31.2, J32.5, J33.3, Q1.3, Q2.3, R2.2, R4.2, R6.2, R13.2, R15.2, WC2_2.1, WC3_1.1, WC4_2.1, WC5_3.1, WC6_3.1, X1.3, X2.2, X3.2, X4.3, X6.3, X8.3
I_B1: C7.1, J32.1, R7.2
I_B2: C8.1, J32.2, R8.2
I_LOAD: C9.1, J33.1, R9.2
I_RAW1: J3.1, R7.1
I_RAW2: J4.1, R8.1
I_RAW3: J5.2, R9.1
K1: J1.11, R12.1
K2: J1.15, R14.1
LOAD+: R5.1, X5.1
MISO: J1.27, J12.3
MOSI: J1.21, J12.1
OW: J1.32, R18.1, X4.1
RELAY_IN1: J8.1, J28.1, J29.1, Q1.1, WC5_1.1
RELAY_IN2: J8.3, J28.2, J29.2, Q2.1, WC5_2.1
SCK: J1.28, J12.4
SCL: J1.22, J10.2, J20.3, J21.3, R17.1, WA3.1, WA4.1
SDA: J1.25, J10.3, J20.4, J21.4, R16.1
SENS_PWR: J1.8, J22.3, J23.3, R10.1, WC2_3.1
SW1_ON: J1.9, J6.2
SW2_ON: J1.10, J7.2
U_B1: C3.1, J32.3, R1.2, R2.1
U_B2: C4.1, J32.4, R3.2, R4.1
U_LOAD: C5.1, J33.2, R5.2, R6.1
VIN_DC: VD1.1, VD2.1, X2.1

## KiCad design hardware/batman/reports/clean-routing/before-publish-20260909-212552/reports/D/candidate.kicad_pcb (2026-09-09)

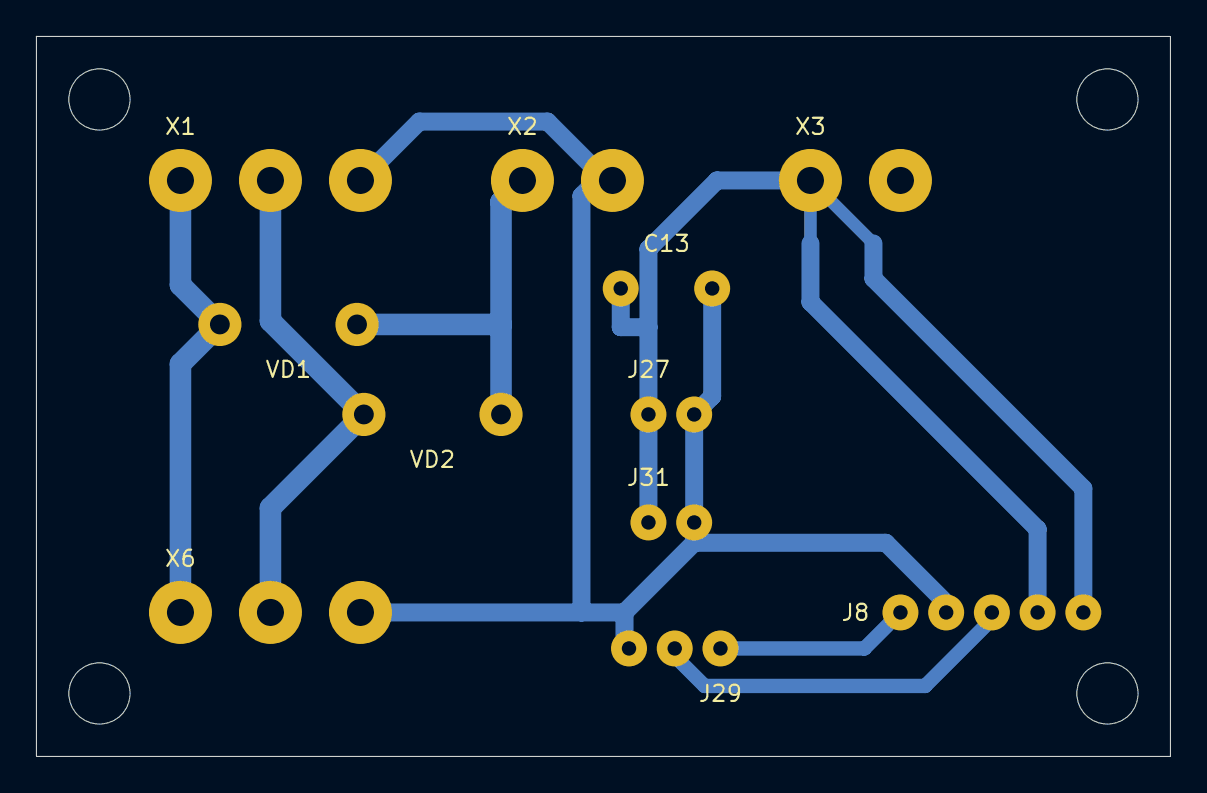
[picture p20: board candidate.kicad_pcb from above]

Board: 2 copper layers, 63.0 x 40.0 mm, 16 parts (0 on the bottom side), 9 nets.

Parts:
C13: 100n_16V; LUT_C13
HD1, HD2, HD3, HD4: M3_NPTH_3.4; Mount_M3
J8: RELAY; LUT_J8
J27: LINK_+5V_GND; LUT_J27
J29: LINK_RELAY_IN1_RELAY_IN2_GND; LUT_J29
J31: LINK_+5V_GND; LUT_J31
NT1: COPPER_STAR_AT_X3; LUT_NT1
VD1: 1N5819; LUT_VD1
VD2: 1N5819; LUT_VD2
X1: B1_B2_GND; LUT_X1
X2: VIN_DC_GND; LUT_X2
X3: 5V_GND; LUT_X3
X6: BAT_SENSE_TO_B; LUT_X6

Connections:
+5V: C13.1, J27.1, J31.1, NT1.1, X3.1
+5V_RELAY_COIL: J8.5, NT1.3
+5V_RELAY_VCC: J8.4, NT1.2
B1: VD1.2, X1.1, X6.1
B2: VD2.2, X1.2, X6.2
GND: C13.2, J8.2, J27.2, J29.3, J31.2, X1.3, X2.2, X3.2, X6.3
RELAY_IN1: J8.1, J29.1
RELAY_IN2: J8.3, J29.2
VIN_DC: VD1.1, VD2.1, X2.1

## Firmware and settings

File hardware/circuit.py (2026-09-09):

from dataclasses import dataclass
import json
from pathlib import Path


@dataclass
class Part:
    ref: str
    value: str
    sheet: str
    pins: list
    kind: str = "block"
    board: str = ""
    position: tuple = (0, 0)
    footprint: str = ""
    alias: str = ""


def circuit():
    parts = []

    def add(ref, value, sheet, nets, kind="block", board="", position=(0, 0), names=None, types=None):
        names = names or [str(number + 1) for number in range(len(nets))]
        types = types or ["passive"] * len(nets)
        pins = [(str(number + 1), name, net, pin_type)
                for number, (name, net, pin_type) in enumerate(zip(names, nets, types))]
        part = Part(ref, value, sheet, pins, kind, board, position)
        parts.append(part)
        return part

    def resistor(ref, value, first, second, x, y, sheet="sense"):
        return add(ref, value, sheet, [first, second], "R", "A", (x, y))

    def capacitor(ref, value, first, second, x, y, sheet="sense", board="A", kind="C"):
        return add(ref, value, sheet, [first, second], kind, board, (x, y))

    left = ["3V3", "EN", "GPIO36", "GPIO39", "GPIO34", "GPIO35", "GPIO32", "GPIO33",
            "GPIO25", "GPIO26", "GPIO27", "GPIO14", "GPIO12", "GND", "GPIO13",
            "GPIO9", "GPIO10", "GPIO11", "VIN"]
    right = ["GND", "GPIO23", "GPIO22", "GPIO1", "GPIO3", "GPIO21", "GND", "GPIO19",
             "GPIO18", "GPIO5", "GPIO17", "GPIO16", "GPIO4", "GPIO0", "GPIO2",
             "GPIO15", "GPIO8", "GPIO7", "GPIO6"]
    gpio = {"3V3": "+3V3", "GND": "GND", "VIN": "+5V", "GPIO39": "I_LOAD",
            "GPIO34": "U_LOAD", "GPIO32": "BTN", "GPIO25": "SW1_ON",
            "GPIO26": "SW2_ON", "GPIO27": "K1", "GPIO33": "SENS_PWR", "GPIO13": "K2",
            "GPIO23": "MOSI", "GPIO22": "SCL", "GPIO21": "SDA", "GPIO19": "MISO",
            "GPIO18": "SCK", "GPIO5": "CS", "GPIO17": "DPS_TX", "GPIO16": "DPS_RX",
            "GPIO4": "OW"}
    pin_names = left + right
    pin_types = ["power_out" if name == "3V3" else "power_in" if name in ("GND", "VIN")
                 else "input" if name in ("GPIO34", "GPIO35", "GPIO36", "GPIO39")
                 else "bidirectional" for name in pin_names]
    add("J1", "DevKitC_38_socket_mMCU", "logic", [gpio.get(name) for name in pin_names],
        "MCU", "A", (8, 24), pin_names, pin_types)
    add("J2", "ADS1115_socket_mADC", "sense",
        ["+3V3", "GND", "SCL", "SDA", "GND", None, "I_B1", "I_B2", "U_B1", "U_B2"],
        "header_h", "A", (45, 28), ["VDD", "GND", "SCL", "SDA", "ADDR", "ALRT", "A0", "A1", "A2", "A3"],
        ["power_in", "power_in", "input", "bidirectional", "input", "open_collector", "input", "input", "input", "input"])
    for index, y in enumerate([8, 15, 22], 1):
        raw = f"I_RAW{index}"
        add(f"J{index + 2}", f"ACS{index}_3WIRE", "sense",
            ["+3V3_SENS", "GND", raw], "header_h", "A", (78, y),
            ["VCC", "GND", "VOUT"])
    add("J6", "SW1_GND_ON", "logic", ["GND", "SW1_ON"], "header", "A", (94, 8))
    add("J7", "SW2_GND_ON", "logic", ["GND", "SW2_ON"], "header", "A", (94, 16))
    add("J8", "RELAY_GND_IN1_IN2_VCC_JDVCC", "logic",
        ["GND", "RELAY_IN1", "RELAY_IN2", "+5V_RELAY_VCC", "+5V_RELAY_COIL"], "header", "A", (94, 45))
    add("J9", "DPS_GND_TX_RX", "logic", ["GND", "DPS_TX", "DPS_RX"], "header", "A", (94, 25))
    add("J10", "OLED_GND_VDD_SCK_SDA", "logic", ["GND", "+3V3", "SCL", "SDA"], "header_h", "A", (43, 76))
    add("J11", "BUTTON", "logic", ["BTN", "GND"], "header_h", "A", (61, 76))
    add("J12", "SPI_3V3_GND_SCK_MISO_MOSI_CS", "logic",
        ["+3V3", "GND", "SCK", "MISO", "MOSI", "CS"], "header_h", "A", (43, 34))
    for ref, value, nets, position in [
            ("X1", "B1_B2_GND", ["B1", "B2", "GND"], (44, 5)),
            ("X2", "VIN_DC_GND", ["VIN_DC", "GND"], (61, 5)),
            ("X3", "5V_GND", ["+5V", "GND"], (8, 5)),
            ("X4", "DS18B20_3V3_DATA_GND", ["+3V3", "OW", "GND"], (78, 76)),
            ("X5", "U_LOAD_SENSE", ["LOAD+"], (94, 35))]:
        add(ref, value, "logic" if ref == "X4" else "power", nets, "terminal", "A", position)
    add("NT1", "COPPER_STAR_AT_X3", "power", ["+5V", "+5V_RELAY_VCC", "+5V_RELAY_COIL"], "net_tie", "A", (8, 5))
    add("VD1", "1N5819", "power", ["VIN_DC", "B1"], "D", "A", (43, 13), ["K", "A"])
    add("VD2", "1N5819", "power", ["VIN_DC", "B2"], "D", "A", (55, 13), ["K", "A"])
    for index, (source, destination, y) in enumerate([("B1", "U_B1", 42), ("B2", "U_B2", 49), ("LOAD+", "U_LOAD", 56)]):
        resistor(f"R{1 + 2 * index}", "100k_1%", source, destination, 45, y)
        resistor(f"R{2 + 2 * index}", "10k_1%" if index < 2 else "4.7k_1%", destination, "GND", 53, y)
        capacitor(f"C{3 + index}", "100n_50V", destination, "GND", 61, y)
    for index, (net, x, y) in enumerate([("I_B1", 45, 64), ("I_B2", 45, 71), ("I_LOAD", 70, 64)], 1):
        resistor(f"R{6 + index}", "1k", f"I_RAW{index}", net, x, y)
        capacitor(f"C{6 + index}", "1u_16V", net, "GND", x + 9, y)
    capacitor("C6", "100n_16V", "+3V3", "GND", 73, 34)
    resistor("R10", "4.7k", "SENS_PWR", "BASE3", 63, 22, "logic")
    resistor("R11", "10k", "BASE3", "+3V3", 72, 17, "logic")
    add("Q3", "BC557_CBE", "logic", ["+3V3_SENS", "BASE3", "+3V3"], "PNP", "A", (63, 15), ["C", "B", "E"])
    for index, y in [(1, 42), (2, 54)]:
        resistor(f"R{12 if index == 1 else 14}", "1k", f"K{index}", f"BASE{index}", 71, y, "logic")
        resistor(f"R{13 if index == 1 else 15}", "10k", f"BASE{index}", "GND", 71, y + 5, "logic")
        add(f"Q{index}", "BC547_CBE", "logic", [f"RELAY_IN{index}", f"BASE{index}", "GND"],
            "NPN", "A", (82, y), ["C", "B", "E"])
    resistor("R16", "4.7k", "SDA", "+3V3", 44, 20, "logic")
    resistor("R17", "4.7k", "SCL", "+3V3", 54, 20, "logic")
    resistor("R18", "4.7k", "OW", "+3V3", 68, 71, "logic")
    add("XLP", "LOAD_P06_P12_P13", "power", ["LOAD+"] * 3, "terminal")
    add("XGND", "GND_P24_P25_P26_P27_P28", "power", ["GND"] * 5, "terminal")
    capacitor("C1", "100u_50V_ALUMINIUM", "LOAD+", "GND", 0, 0, "power", "", "CP")
    capacitor("C2", "100n_50V", "LOAD+", "GND", 0, 0, "power", "", "C_bus")
    add("D3", "1.5KE33A_DNP", "power", ["LOAD+", "GND"], "TVS", names=["K", "A"])
    for index in [1, 2]:
        add(f"XB{index}", f"BAT{index}_PANEL", "power", [f"P{1 if index == 1 else 7:02}", "GND"], names=["+", "-"])
        add(f"F{index}", "ATO_15A", "power", [f"P{1 if index == 1 else 7:02}", f"P{2 if index == 1 else 8:02}"], "fuse")
        add(f"mACS{index}", "ACS711EX_15.5A", "power",
            [f"P{2 if index == 1 else 8:02}", f"B{index}", "+3V3_SENS", "GND", f"I_RAW{index}"],
            names=["IP-", "IP+", "VCC", "GND", "VOUT"],
            types=["passive", "passive", "power_in", "power_in", "output"])
        add(f"mSW{index}", "Pololu_2815_HP", "power", [f"B{index}", f"P{5 if index == 1 else 11:02}", "GND", f"SW{index}_ON"],
            names=["VIN", "VOUT", "GND", "ON"], types=["passive", "passive", "power_in", "input"])
        add(f"mDIO{index}", "XL74610", "power", ["LOAD+", f"P{5 if index == 1 else 11:02}"], "diode_module", names=["K", "A"])
    add("mACS3", "ACS711EX_15.5A", "power", ["LOAD+", "P14", "+3V3_SENS", "GND", "I_RAW3"],
        names=["IP-", "IP+", "VCC", "GND", "VOUT"],
        types=["passive", "passive", "power_in", "power_in", "output"])
    add("Fout", "ATO_15A", "power", ["P14", "LOAD_OUT+"], "fuse")
    add("XLOAD", "LOAD_PANEL", "power", ["LOAD_OUT+", "GND"], names=["+", "-"])
    add("XPSU", "PSU_33V_10A_PANEL", "charge", ["P22", "GND"], names=["+", "-"])
    add("mDPS", "DPS5015_9600_8N1_ADDR1", "charge", ["P22", "GND", "P16", "GND", None, "DPS_TX", "DPS_RX", "GND"],
        names=["IN+", "IN-", "OUT+", "OUT-", "V_UNUSED", "R_RXI", "T_TXO", "G_UART"],
        types=["power_in", "power_in", "power_out", "power_in", "passive", "input", "output", "power_in"])
    add("Fchg", "ATO_15A", "charge", ["P16", "P17"], "fuse")
    add("mDIO3", "XL74610", "charge", ["CHG", "P17"], "diode_module", names=["K", "A"])
    add("mREL2", "FL_3FF_5V_10A_REMOVE_JUMPER", "charge",
        ["CHG", "B1", None, "CHG", "B2", None, "GND", "RELAY_IN1", "RELAY_IN2", "+5V_RELAY_VCC", "+5V_RELAY_COIL"],
        names=["COM1", "NO1", "NC1", "COM2", "NO2", "NC2", "GND", "IN1", "IN2", "VCC", "JD_VCC"])
    add("mDC5", "LM2596_SET_5.0V_FIRST", "charge", ["VIN_DC", "GND", "+5V", "GND"],
        names=["IN+", "IN-", "OUT+", "OUT-"], types=["power_in", "power_in", "power_out", "power_in"])
    add("mOLED", "SSD1306_0x3C", "logic", ["GND", "+3V3", "SCL", "SDA"],
        names=["GND", "VDD", "SCK", "SDA"], types=["power_in", "power_in", "input", "bidirectional"])
    for index in [1, 2]:
        add(f"T{index}", "DS18B20_PROBE", "logic", ["+3V3", "OW", "GND"],
            names=["VCC", "DATA", "GND"], types=["power_in", "bidirectional", "power_in"])
    add("SW1", "PANEL_BUTTON_NO", "logic", ["BTN", "GND"], "switch")
    for net in ["GND", "VIN_DC", "+3V3_SENS", "P22"]:
        add("#FLG" + str(len(parts)), "PWR_FLAG", "charge", [net], "flag", types=["power_out"])
    for part in parts:
        if not part.ref[-1].isdigit():
            part.alias = part.ref
            part.ref += "1"
    pinout_path = Path(__file__).with_name("connector_pinout.json")
    if pinout_path.exists():
        pinouts = json.loads(pinout_path.read_text(encoding="utf-8"))
        by_ref = {part.ref: part for part in parts}
        allowed = {f"J{number}" for number in range(3, 13)} | {f"X{number}" for number in range(1, 6)}
        assert pinouts.keys() <= allowed
        for ref, nets in pinouts.items():
            part = by_ref[ref]
            pins_by_net = {pin[2]: pin for pin in part.pins}
            assert len(nets) == len(part.pins) and set(nets) == pins_by_net.keys(), ref
            part.pins = [(str(index + 1), pins_by_net[net][1], net, pins_by_net[net][3])
                         for index, net in enumerate(nets)]
            part.value = {"J8": "RELAY", "J9": "DPS_UART", "J10": "OLED_I2C", "J12": "SPI",
                          "X4": "DS18B20"}.get(ref, part.value)
    by_ref = {part.ref: part for part in parts}
    for ref in ["J3", "J4", "J5", "X5", "R1", "R2", "R3", "R4", "R5", "R6",
                "R7", "R8", "R9", "C3", "C4", "C5", "C7", "C8", "C9"]:
        by_ref[ref].board = "B"
        by_ref[ref].sheet = "sense"
    by_ref["J2"].board = ""
    by_ref["J2"].value = "ADS1115_0x48_EXTERNAL"
    by_ref["C6"].board = ""
    for ref in ["Q3", "R10", "R11"]:
        by_ref[ref].board = "C"
        by_ref[ref].sheet = "supply3"
    for ref in ["X1", "X2", "X3", "VD1", "VD2", "NT1", "J8"]:
        by_ref[ref].board = "D"
        by_ref[ref].sheet = "supply5"
    by_ref["J1"].pins = [(number, name, None if name in ["GPIO34", "GPIO39"] else net, pin_type)
                         for number, name, net, pin_type in by_ref["J1"].pins]
    add("J13", "ADS1115_0x49_EXTERNAL", "sense",
        ["+3V3", "GND", "SCL", "SDA", "+3V3", None, "I_LOAD", "U_LOAD", "GND", "GND"],
        "header_h", "", names=["VDD", "GND", "SCL", "SDA", "ADDR", "ALRT", "A0", "A1", "A2", "A3"],
        types=["power_in", "power_in", "input", "bidirectional", "input", "open_collector", "input", "input", "input", "input"])
    capacitor("C10", "100n_16V", "+3V3", "GND", 0, 0, "sense", "")
    capacitor("C11", "100n_16V", "+3V3", "GND", 0, 0, "supply3", "C")
    capacitor("C12", "100n_16V", "+3V3_SENS", "GND", 0, 0, "supply3", "C")
    capacitor("C13", "100n_16V", "+5V", "GND", 0, 0, "supply5", "D")
    for ref, board, sheet, nets in [
            ("J20", "A", "logic", ["+3V3", "GND", "SCL", "SDA"]),
            ("J21", "A", "logic", ["+3V3", "GND", "SCL", "SDA"]),
            ("J22", "A", "logic", ["+3V3", "GND", "SENS_PWR"]),
            ("J23", "C", "supply3", ["+3V3", "GND", "SENS_PWR"]),
            ("J24", "C", "supply3", ["GND", "+3V3_SENS"]),
            ("J25", "B", "sense", ["GND", "+3V3_SENS"]),
            ("J26", "A", "logic", ["+5V", "GND"]),
            ("J27", "D", "supply5", ["+5V", "GND"]),
            ("J28", "A", "logic", ["RELAY_IN1", "RELAY_IN2", "GND"]),
            ("J29", "D", "supply5", ["RELAY_IN1", "RELAY_IN2", "GND"]),
            ("J30", "C", "supply3", ["+3V3", "GND"]),
            ("J31", "D", "supply5", ["+5V", "GND"]),
            ("J32", "B", "sense", ["I_B1", "I_B2", "U_B1", "U_B2", "GND"]),
            ("J33", "B", "sense", ["I_LOAD", "U_LOAD", "GND"])]:
        add(ref, "LINK_" + "_".join(nets), sheet, nets, "header_h", board, names=nets)
    add("X6", "BAT_SENSE_TO_B", "supply5", ["B1", "B2", "GND"], "terminal", "D", names=["B1", "B2", "GND"])
    add("X8", "BAT_SENSE_FROM_D", "sense", ["B1", "B2", "GND"], "terminal", "B", names=["B1", "B2", "GND"])
    return parts


def validate(parts):
    by_ref = {part.ref: part for part in parts}
    assert len(by_ref) == len(parts)
    pins = {name: net for _, name, net, _ in by_ref["J1"].pins}
    assert pins["GPIO39"] is None and pins["GPIO34"] is None
    assert pins["GPIO33"] == "SENS_PWR"
    assert pins["GPIO14"] is None
    assert ("8", "GPIO33", "SENS_PWR", "bidirectional") in by_ref["J1"].pins
    assert not any(net == "FAULT" for part in parts for _, _, net, _ in part.pins)
    assert all(pins[f"GPIO{number}"] is None for number in [0, 2, 6, 7, 8, 9, 10, 11, 12, 15])
    assert pins["GPIO22"] == "SCL" and pins["GPIO21"] == "SDA" and pins["GPIO23"] == "MOSI"
    assert [pin[2] for pin in by_ref["J2"].pins][-4:] == ["I_B1", "I_B2", "U_B1", "U_B2"]
    assert [pin[2] for pin in by_ref["J13"].pins][-4:] == ["I_LOAD", "U_LOAD", "GND", "GND"]
    assert by_ref["J2"].pins[4][2] == "GND" and by_ref["J13"].pins[4][2] == "+3V3"
    assert all(not by_ref[ref].board for ref in ["J2", "J13", "C6", "C10"])
    assert not any(net in ["SDA", "SCL", "+3V3"] for part in parts if part.board == "B"
                   for _, _, net, _ in part.pins)
    for ref in ["J20", "J21"]:
        assert by_ref[ref].board == "A"
        assert [pin[2] for pin in by_ref[ref].pins] == ["+3V3", "GND", "SCL", "SDA"]
    for ref, adc, channels in [("J32", "J2", 4), ("J33", "J13", 2)]:
        assert by_ref[ref].board == "B"
        assert [pin[2] for pin in by_ref[ref].pins] == [pin[2] for pin in by_ref[adc].pins[6:6+channels]] + ["GND"]
    assert {part.board for part in parts if part.board} == {"A", "B", "C", "D"}
    for first, second in [("J22", "J23"), ("J24", "J25"), ("J26", "J27"), ("J28", "J29"), ("X6", "X8")]:
        assert [pin[2] for pin in by_ref[first].pins] == [pin[2] for pin in by_ref[second].pins]
    for ref in ["mACS1", "mACS2", "mACS3"]:
        assert by_ref[ref].pins[0][1] == "IP-"
        assert [pin[1] for pin in by_ref[ref].pins[2:]] == ["VCC", "GND", "VOUT"]
    for ref in ["J3", "J4", "J5"]:
        assert len(by_ref[ref].pins) == 3
    assert 30 * 10 / 110 < 3.3
    assert 30 * 4.7 / 104.7 < 2.5
    print(f"Circuit checks passed: {len(parts)} parts")


if __name__ == "__main__":
    validate(circuit())

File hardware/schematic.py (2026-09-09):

from pathlib import Path
import json
import uuid

from circuit import circuit, validate


ROOT = Path(__file__).resolve().parent / "batman"
SHEETS = ["power", "charge", "sense", "logic", "supply3", "supply5"]


def uid(name):
    return str(uuid.uuid5(uuid.NAMESPACE_URL, "batman/" + name))


def quote(value):
    return json.dumps(str(value), ensure_ascii=False)


def effects(size=1.0, extra=""):
    return f"(effects (font (size {size} {size})) {extra})"


def line(points):
    coordinates = " ".join(f"(xy {x} {y})" for x, y in points)
    return f"(polyline (pts {coordinates}) (stroke (width 0.254) (type default)) (fill (type none)))"


def geometry(part):
    if part.kind == "flag":
        return [("1", "pwr", part.pins[0][2], "power_out", 0, 0, 90)], 5.08, 5.08
    if len(part.pins) == 2 and part.kind in ["R", "C", "CP", "C_bus", "D", "TVS", "diode_module", "fuse", "switch"]:
        return [(*part.pins[0], -7.62, 0, 0), (*part.pins[1], 7.62, 0, 180)], 2.54, 2.54
    if part.kind in ["NPN", "PNP"]:
        return [(*part.pins[0], 7.62, 5.08, 180), (*part.pins[1], -7.62, 0, 0),
                (*part.pins[2], 7.62, -5.08, 180)], 3.81, 7.62
    count = (len(part.pins) + 1) // 2
    half_height = max(5.08, (count + 1) * 1.27)
    output = []
    for index, pin in enumerate(part.pins):
        right = index >= count
        row = index - count if right else index
        output.append((*pin, 22.86 if right else -22.86, (count - 1) * 1.27 - row * 2.54, 180 if right else 0))
    return output, 17.78, half_height


def symbol(part, embedded=False):
    pins, half_width, half_height = geometry(part)
    name = part.ref.replace("#", "_")
    graphics = []
    if part.kind == "R":
        graphics.append('(rectangle (start -2.54 -1.016) (end 2.54 1.016) (stroke (width 0.254) (type default)) (fill (type none)))')
        graphics.extend([line([(-5.08, 0), (-2.54, 0)]), line([(2.54, 0), (5.08, 0)])])
    elif part.kind in ["C", "CP", "C_bus"]:
        graphics.extend([line([(-0.762, -2.54), (-0.762, 2.54)]), line([(0.762, -2.54), (0.762, 2.54)]),
                         line([(-5.08, 0), (-0.762, 0)]), line([(0.762, 0), (5.08, 0)])])
        if part.kind == "CP":
            graphics.append(f'(text "+" (at -2.54 2.54 0) {effects()})')
    elif part.kind in ["D", "TVS", "diode_module"]:
        graphics.extend([line([(-1.27, -2.54), (-1.27, 2.54)]),
                         line([(-1.27, 0), (2.54, 2.54), (2.54, -2.54), (-1.27, 0)]),
                         line([(-5.08, 0), (-1.27, 0)]), line([(2.54, 0), (5.08, 0)])])
    elif part.kind in ["NPN", "PNP"]:
        graphics.extend([line([(-5.08, 0), (-1.27, 0)]), line([(-1.27, -3.81), (-1.27, 3.81)]),
                         line([(-1.27, 1.27), (3.81, 5.08), (5.08, 5.08)]),
                         line([(-1.27, -1.27), (3.81, -5.08), (5.08, -5.08)])])
        graphics.append(line([(0.5, -3.9), (3.0, -4.5), (2.0, -2.0)]) if part.kind == "NPN"
                        else line([(0.5, -3.9), (-0.4, -1.9), (2.0, -2.0)]))
    elif part.kind == "flag":
        graphics.append(line([(0, 0), (0, 2.54), (-1.27, 3.81), (0, 5.08), (1.27, 3.81), (0, 2.54)]))
    elif part.kind == "switch":
        graphics.append(line([(-5.08, 0), (-2.54, 0), (3.81, 2.54)]))
        graphics.append(line([(3.81, 0), (5.08, 0)]))
    else:
        graphics.append(f'(rectangle (start {-half_width} {-half_height}) (end {half_width} {half_height}) (stroke (width 0.254) (type default)) (fill (type background)))')
        if part.kind == "fuse":
            graphics.append(line([(-5.08, 0), (5.08, 0)]))
    pin_strings = []
    for number, pin_name, _, pin_type, x, y, angle in pins:
        length = 0 if part.kind == "flag" else 5.08 if half_width == 17.78 else 2.54
        pin_strings.append(f'(pin {pin_type} line (at {x} {y} {angle}) (length {length}) '
                           f'(name {quote(pin_name)} {effects(0.9)}) (number {quote(number)} {effects(0.9)}))')
    lib_name = "Batman:" + name if embedded else name
    hidden = "(hide yes)" if part.kind in ["R", "C", "CP", "C_bus", "D", "TVS", "diode_module", "fuse", "switch", "flag"] else ""
    return (f'(symbol {quote(lib_name)} (pin_names (offset 0.508) {hidden}) '
            f'(in_bom {"no" if part.kind == "flag" else "yes"}) (on_board {"yes" if part.board else "no"}) '
            f'(property "Reference" {quote(part.ref)} (at 0 {half_height + 2.54} 0) {effects()}) '
            f'(property "Value" {quote(part.value)} (at 0 {-half_height - 2.54} 0) {effects()}) '
            f'(symbol {quote(name + "_0_1")} {" ".join(graphics)}) '
            f'(symbol {quote(name + "_1_1")} {" ".join(pin_strings)}))')


def text(content, x, y, size=1.27):
    return f'(text {quote(content)} (at {x} {y} 0) {effects(size, "(justify left)")} (uuid {uid(content + str(x) + str(y))}))'
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

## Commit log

2026-09-09 Initial import
    [accepted.kicad_pcb, ads-configuration.csv, angle-trial.kicad_pcb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]
2026-09-09 Add modular cable cassette revision
    [assembly-cable-modular.blend]
2026-09-09 Add modular cable assembly images and update JSON configuration
    [assembly-cable-modular.blend]
2026-09-09 Add modular cable assembly preview images
    [assembly-cable-modular.blend]
